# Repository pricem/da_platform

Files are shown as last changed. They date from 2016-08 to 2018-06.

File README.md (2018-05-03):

# "Samoyed" digital audio platform

[Documentation site](http://da-platform.readthedocs.io)

##  What is it?

This is a set of PCB designs, FPGA firmware, and software for a digital audio interface.  The designs allow for up to 32 channels of audio I/O from four ADC/DAC modules per chassis.  The intent is to provide audio quality suitable for hi-fi systems, and to allow experimentation with ADC/DAC module design, digital filtering, and user interfaces.

More detailed documentation is located in the docs directory.  This documentation is in Sphinx format and is synchronized to http://da-platform.readthedocs.io.  A PDF version is periodically published to docs/da_platform.pdf.

Work is in progress.  If you have any questions, please contact the author by creating an issue, or commenting on a relevant issue if one already exists.

##  Use cases

The author is using this project as a music streaming server, digital crossover, and measurement device in a DIY audio system.  Other uses are possible and are described in more detail in the documentation.

## License information

This project is open source and intended for non-commercial use.  Intellectual property developed for this project is licensed partly under the Solderpad license (hardware) and partly under the GPL (software).  Please see the LICENSE file for more information, and the individual licenses in the docs/licenses directory for the complete terms.

Any other intellectual property included in this repository (whether for users' convenience, or accidentally) is covered by its own original license.

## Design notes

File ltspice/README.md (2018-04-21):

## LTspice schematics

This directory contains LTspice files for the design of some analog circuits used in this project:
* List to be added after all files are placed in this directory.

All designs here are licensed under the Solderpad license (docs/licenses/LICENSE-SHL).

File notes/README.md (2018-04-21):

## Miscellaneous planning and design notes

These files contain useful information, but are disorganized.  You can learn a lot (too much?) about my thought process by looking into the text files.  There are also BOM spreadsheets for ordering parts.

Over time, much of this will be reorganized into the docs directory.

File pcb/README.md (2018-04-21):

## Eagle PCB designs

This directory contains Eagle files for the design of PCBs used in this project:
* List to be added after all files are placed in this directory.

Please note that the files are in Eagle 5.x format.

All designs here are licensed under the Solderpad license (docs/licenses/LICENSE-SHL).

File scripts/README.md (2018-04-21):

## Shell scripts for DA platform

These are from the Raspberry Pi that I put in my DA platform box.  For now, these should be considered unsupported examples.

All code here is licensed under the GPL license (docs/licenses/LICENSE-GPL).

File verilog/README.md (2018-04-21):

## HDL design for DA platform

The baseline DA platform implementation has an FPGA in it, to act as an asynchronous FIFO and I2S/SPI/GPIO interface to the DAC and ADC cards.  This directory contains the SystemVerilog hardware description language (HDL) code for the digital logic on the FPGA.

The design is to some extent decoupled from the hardware platform that it runs on.  Please look at the xilinx directory for the scripts that build this into a bitstream for a specific FPGA.

All code here is licensed under the Solderpad license (docs/licenses/LICENSE-SHL).

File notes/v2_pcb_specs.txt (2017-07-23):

Specs for things to include on v2 PCBs
=========================================

PSU
---
Lowest reverse-recovery diodes possible
    Why not Schottkys?
12-pin connector to isolator

Carrier (shared)
----------------

Footprint for upside down RPi
JST power connector for 5 V (probably from ext wall wart)

Carrier option A - ZTEX FPGA
---------
FPGA board footprint (no mounting holes)
JTAG connector

Carrier option B - {USB, Mini}streamer
---------
Mechanical scheme for mounting streamer board
Header for attaching streamer board connections (put streamer upside down?)

Isolator
--------

Stuffing option for resistors instead of ADUM isolators
Debug header that is outside shadow of carrier

Jung discrete regs under center of board
Stuffing option for low cost 3 terminal regs for +/- 15, 5, 3.3 V

Clock
-----
Clock source support (stuffing options):
    Crystek CCHD-957
    Tentlabs XO
    Some other decent inexpensive osc.
    SMA input (SE CMOS level), as if from an arrogant module
Differential driver support:
    LVDS - low cost
        FIN1001 type driver
    CML - high performance
        ADCLK948 driver
        AD9515 receiver
Debug connections for:
    Clock sources - SMA
    Clock select input

Series resistance for CMOS clock outputs (10 to 22 ohm?)
Good supply decoupling / ferrite beads
Stuffing option for local supply regulation

Modules
--------
Module adapter for testing v1 modules before v2 modules are designed

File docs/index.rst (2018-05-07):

"Samoyed" digital audio platform
=======================

This page is the starting point for documentation about the project (often referred to as the "DA platform").

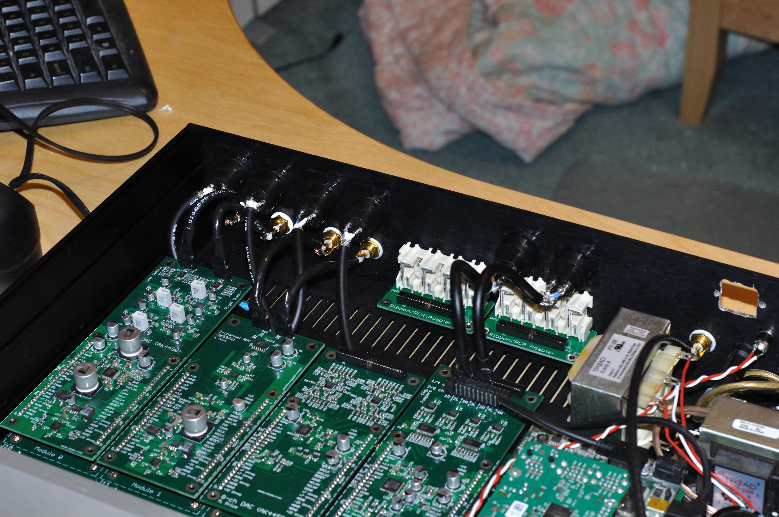
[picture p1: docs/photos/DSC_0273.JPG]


    A baseline implementation of the platform.  This one has two AK4490-based 2-channel DACs, as well as an 8-channel DAC and 8-channel ADC.  The onboard Raspberry Pi functions as a music streaming server and digital active crossover.
    
.. toctree::
   :maxdepth: 2
   :caption: Contents:
   
   intro
   history
   hw_arch
   measurements

Indices and tables
==================

* :ref:`genindex`
* :ref:`modindex`
* :ref:`search`

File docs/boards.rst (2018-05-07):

Boards designed so far
======================

This section describes the features of the PCB designs that have been completed and tested so far.  Eagle 5.x files for the boards can be found in the ``pcb`` directory.

Some modules were developed for an earlier version of the platform, and have been tested with the current version using an adapter PCB.  These older modules would need to be revised to meet the current interface specification, and don't fit within a reasonably sized chassis with the current backplane (because they are mounted vertically).

**Modules**

More detailed information about modules (explaining the design process) will be added later.  For now, here is a short summary of what is on each board.  The baseline implementations use AKM parts because they are readily available (with full datasheets), perform well, and the DACs conveniently have voltage outputs.

* DAC2 (2 channel DAC)

  * DSD1792_ (tested on earlier platform only)
  
    * No local regulation; uses regulated supplies from backplane
    * Two iterations of a common-base I/V stage
    
      * `Revision A`__ with simple BJT current sources and MOSFET follower output 
      * `Revision B`__ with improved PSRR, 3rd-order antialising filter and diamond buffer output
      
  * AK4490_

    * LT3042 local regulators for VDDL/R and VREFL/R; ADM7160 regulators for AVDD and DVDD
    * AD9515 LVPECL clock receiver powered by ADM7154 regulator
    * ADA4899-1 output buffer/filter powered by ADP7142/ADP7182 regulators
    * 2 V differential (1 V single-ended) full-scale output
    * 0/10/20/30 dB resistive attenuator controlled by GPIO

.. _DSD1792: https://github.com/pricem/da_platform/raw/master/docs/schematics/dac2_v1.pdf
.. __: https://github.com/pricem/da_platform/raw/master/docs/schematics/dac2_v1_iv_a.pdf
.. __: https://github.com/pricem/da_platform/raw/master/docs/schematics/dac2_v1_iv_b.pdf
.. _AK4490: https://github.com/pricem/da_platform/raw/master/docs/schematics/dac2_v2.pdf

* ADC2 (2 channel ADC)

  * AK5572_

    * LT3042 local regulators for AVDD and VREFL/R; ADM7160 regulator for DVDD
    * AD9515 LVPECL clock receiver powered by ADM7154 regulator
    * ADA4004-4 input buffer; ADA4932-2 ADC driver powered by ADP7142/ADP7182 regulators
    * 2.25 V full-scale input (differential or single-ended)

* DAC8 (8 channel DAC)

  * AD1934_ (tested on earlier platform only)
  
    * No local regulation; uses regulated supplies from backplane
    * Two iterations of a voltage gain / antialiasing filter stage
    
      `Revision A`_, `Revision B`_
      
  * AK4458_
  
    * ADP7118 regulators for AVDD and VREF; ADM7160 regulator for DVDD
    * LS90LV012 LVDS clock receiver powered by ADP7118 regulator
    * OPA1664 output buffer/filter
    * 2 V single-ended full-scale output (no differential output)
    * 0/10/20 dB resistive attenuator controlled by SPI

* ADC8 (8 channel ADC)

  * AK5578_
  
    * ADP7118 regulators for AVDD and VREF; ADM7160 regulator for DVDD
    * LS90LV012 LVDS clock receiver powered by ADP7118 regulator
    * OPA1664 input buffer; THS4524 ADC driver
    * 2.25 V full-scale input (differential or single-ended)

.. _AK5572: https://github.com/pricem/da_platform/raw/master/docs/schematics/adc2_v2.pdf
.. _AD1934: https://github.com/pricem/da_platform/raw/master/docs/schematics/dac8_v1.pdf
.. _Revision A: https://github.com/pricem/da_platform/raw/master/docs/schematics/dac8_v1_scaler_a.pdf
.. _Revision B: https://github.com/pricem/da_platform/raw/master/docs/schematics/dac8_v1_scaler_b.pdf
.. _AK4458: https://github.com/pricem/da_platform/raw/master/docs/schematics/dac8_v2.pdf
.. _AK5578: https://github.com/pricem/da_platform/raw/master/docs/schematics/adc8_v2.pdf

**Clock source**

* `Initial version`__ with multiple stuffing options
  
  * One clock is on and one is powered down at all times (selected by carrier)
  * Damped ferrite bead supply filters leading to each oscillator and to logic
  * Low cost stuffing example:
  
    * ADM7160 regulator
    * Epson SG-210STF oscillators
    * 74xx CMOS mux and FIN10xx LVDS buffer
  
  * High performance stuffing example:
  
    * ADM7154 regulator
    * Crystek CCHD-957 oscillators
    * ADCLK948 LVPECL clock mux/buffer
    
  Note that you can use any combination of oscillator, regulator and buffer.  There are SMD footprints which would fit (for example) the NDK NZ2520SD, and DIP footprints that fit (for example) the Tentlabs XO.
  
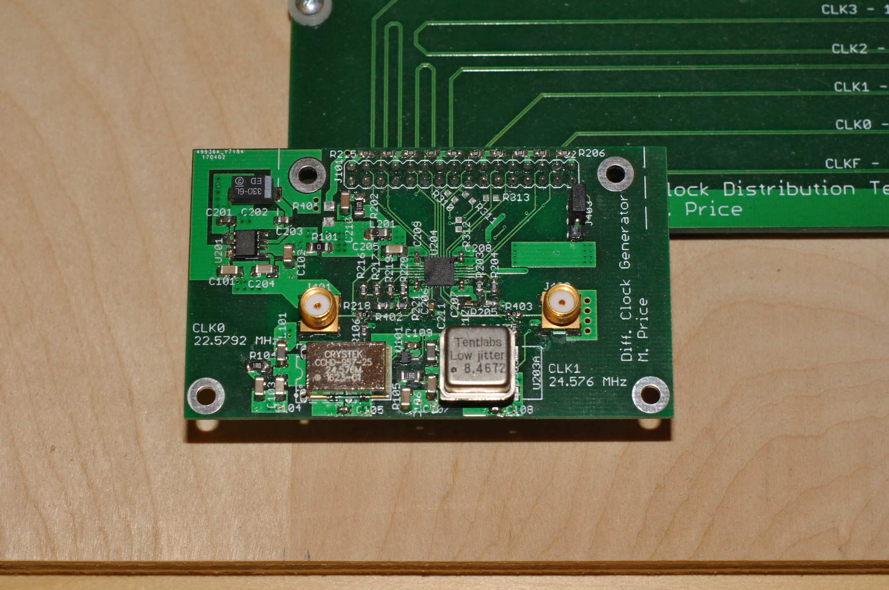
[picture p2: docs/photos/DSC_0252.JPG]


    Testing of a clock source board allowing comparison between Crystek CCHD-957 and Tent XO oscillators.
  
.. __: https://github.com/pricem/da_platform/raw/master/docs/schematics/clock_v2.pdf

**Backplane**

* `Initial version`__

  * Stuffing options for digital interconnect:
  
    * ADUM340x / ADUM14xE0 transformer isolators
    * Resistor/jumper bypass option for non-isolated system

  * Global regulation (+5 V, +3.3 V, +/- 15 V) with stuffing options:
  
    * LM317/LM337 with Vadj bypass
    * Jung regulators with LM317/LM337 preregulator

.. __: https://github.com/pricem/da_platform/raw/master/docs/schematics/isolator_v2.pdf

**Carrier**

* `Initial version`__ contains:

  * ZTEX USB-FPGA 2.13a (Xilinx Artix-7 XC7A35T FPGA, 256 MB memory)
  
    This project includes an HDL design and build scripts for the FPGA to function as the carrier, exercising all features of the module interface.  It also acts as a deep (8M sample) asynchronous FIFO, since the USB interface clock is unrelated to the audio clocks.  Much more information about this can be found in the `Digital design`_ section.
  
  * Raspberry Pi (optional)
  
    I use MPD running on the Raspberry Pi as a streaming server for audio files stored on a NAS.  The Raspberry Pi is mounted on the carrier card within the chassis, and has an extension cable to an Ethernet jack on the back.  However, you can leave out the Raspberry Pi and connect any computing device to the FPGA board using USB (with a similar extension cable).  It's possible to use a USB Wi-fi adapter.
  
  * External 5 V DC wall wart supply (can be isolated from audio supplies, if backplane is equipped with isolators)

  * Debug/expansion header (0.1" pitch) for prototyping

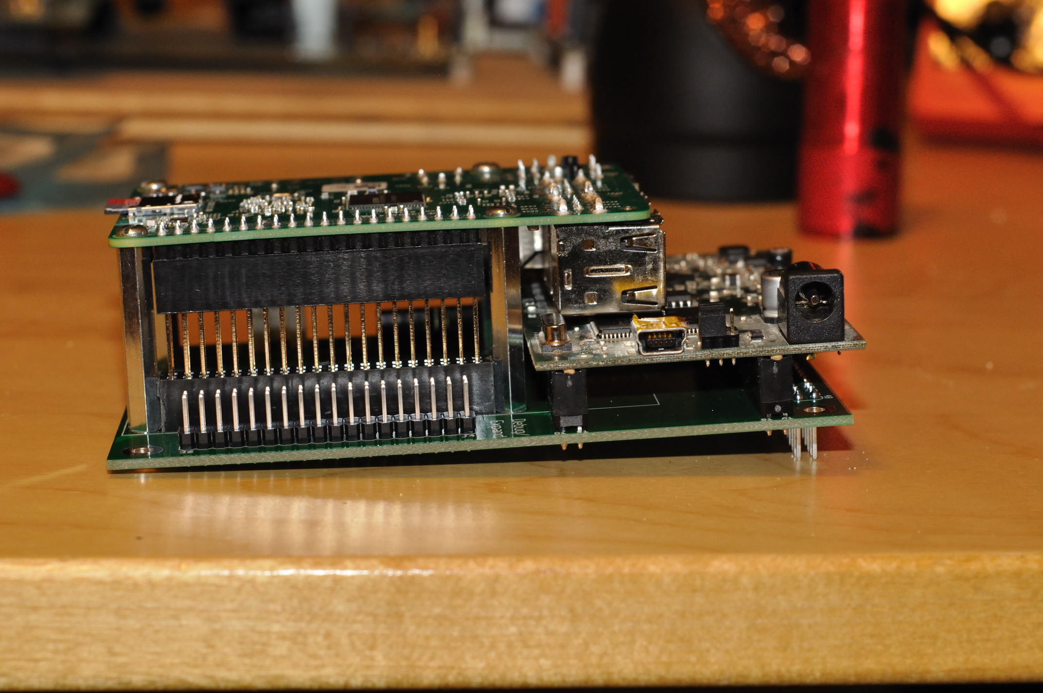
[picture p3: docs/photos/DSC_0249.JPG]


    Photo of carrier board stack showing ZTEX FPGA board (right) and Raspberry Pi (top) connected with a stacking header.

.. __: https://github.com/pricem/da_platform/raw/master/docs/schematics/carrier_v2.pdf

**PSU**

* `Initial version`_

  * 60 Hz linear supply with diode rectifiers
  * Dual 5 V (Triad VPS10-2500) and 28 Vct (Triad FD7-28) transformers
  * +7 V unregulated outputs for analog and digital sections
  * +/- 22 V unregulated outputs for analog sections
  * 10,000 uF decoupling for each rail
  * At least 1 A load is allowed for all supplies simultaneously

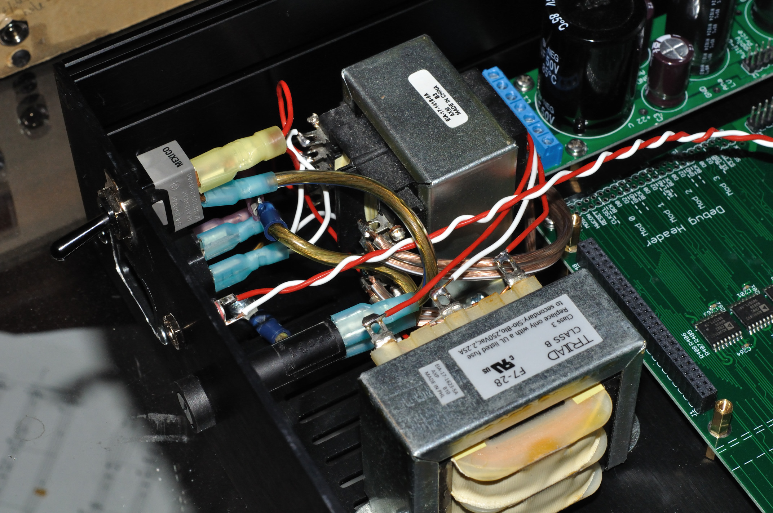
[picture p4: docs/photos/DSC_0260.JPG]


    Detail of transformer wiring for PSU.  The rectifier/filter PCB is in the upper right.

.. _`Initial version`: https://github.com/pricem/da_platform/raw/master/docs/schematics/psu_v2.pdf

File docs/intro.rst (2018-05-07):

Introduction
------------

Motivation
==========

There are many options for DIY digital audio, especially 2-channel DACs.  
You can buy complete kits or building blocks like USB I2S interfaces, power supplies, and DAC boards.
But there are some more complicated choices and compromises to make for other applications, like home theather, digital crossovers, music recording, and measurements.
This project aims to provide a common platform to support this variety of applications with minimal hardware or software re-design.
All of its PCB designs, FPGA firmware, and software code are open-source and included in the GitHub repository.

Features
========

The baseline design allows you to build a box with up to 32 channels of audio I/O at standard sample rates (44.1--192 kHz).  The main capabilities I pursued are: 

- **Removable DAC/ADC modules with a common mechanical and electrical specification**

  The modules can be swapped out based on system configuration needs, budget limitations, or listening preferences.
  DIYers can contribute novel converter and analog designs by designing a module, without "reinventing the wheel" for everything else.
  The platform carries up to 4 modules with up to 8 channels each.
  PCB designs are provided for 2-channel and 8-channel DACs and ADCs with recent AKM parts.

- **Support for FPGA-based asynchronous FIFO**

  The digital interfaces in the platform can be controlled by a ZTEX USB-FPGA 2.13a board containing a Xilinx XC7A35T FPGA and 256 MB of DRAM.
  I provide firmware for the FPGA to act as a set of large asynchronous FIFOs in both directions.
  This allows the use of a local master clock and makes performance independent of software and USB behavior.
  
- **Support for built-in music streaming server and real-time FIR filtering using Raspberry Pi**

  The Raspberry Pi can connect to a wired or wireless Ethernet network.
  MPD is used as a music server that can be controlled by an Android mobile app.
  It can play music stored on another computer or NAS, and stream music from another device.
  ALSA configuration options allow some channels to be directed through the speakers library or another filtering engine.

- **Support for galvanic isolation of modules**

  The complex digital portions of the system (typically Raspberry Pi and FPGA) have a separate power supply from the modules and clock sources.
  Digital signals (e.g. I2S, SPI) are routed through Analog Devices transformer isolators which allow these supplies to use separate grounds.
  The purpose of this is to reduce the currents flowing in the grounds (both digital and analog) used by the modules and clock sources.

- **Stuffing options for different budgets**

  In order to broaden the accessibility of this platform, different versions can be built with different capabilities.
  The only constant is the underlying PCBs, which are inexpensive.
  If an asynchronous FIFO and low-jitter clocking are not needed, a USBStreamer or Ministreamer I2S interface could be used.
  The baseline backplane can be built with jumpers in place of the galvanic isolators.
  Different DAC and ADC modules, clock sources, power supplies, and chassis can also be chosen for the desired system cost.

- **Moderate performance limitations**

  This platform probably won't achieve the same performance as a carefully designed and tweaked, purpose-built setup for a particular application.
  However, I believe it can get close.
  The backplane PCB does not carry analog audio signals.
  EMI can be suppressed by installing a conductive divider that places the ADC/DAC modules in a Faraday cage.
  Modules can provide their own supply regulation.
  The differential clock distribution scheme limits excess phase noise added to that of the clock sources.

These features are justified and explained in more detail in the following sections.

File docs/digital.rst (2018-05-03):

Digital design
==============

The baseline carrier design includes an FPGA, which gives it a lot of flexibility.  This section describes the digital logic that runs on the FPGA, providing up to 32 channels of audio I/O through asynchronous FIFOs, and allowing a host computer to exercise all module features via USB.

The logic is defined in SystemVerilog hardware description language (HDL).  Any future improvements will be shared with users who can simply reprogram their boards.  The design could also be retargeted to other carrier boards.  Please see the ``verilog`` directory of the repository for design and simulation sources, and the ``xilinx`` directory for build scripts.  

I started out with the `ZTEX USB-FPGA 2.13a board <https://www.ztex.de/usb-fpga-2/usb-fpga-2.13.e.html>`_, which has all of the necessary features and comes with an elegant and open-source software/firmware stack for delivering data to and from the custom logic via USB.  It is also affordable compared to other FPGA boards with similar capabilities.

The primary function of this design is to provide a bridge between a computing device and the physical interfaces (I2S, SPI, and GPIO) of the four DAC/ADC modules.  (From a digital design perspective, it would be easy to change the number of modules at build time.)  For now we are using a USB interface for the host computer, but other interfaces could be added in the future; for example, audio could be streamed over Ethernet, or control commands could be sent over a UART or SPI.

The architecture is shown in the following diagram.



Each module interfaces with a "slot controller" which accepts commands and audio samples specific to that module.  The audio sample I/Os are 32 bits wide and the stream of samples can be rearranged according to runtime configuration (number of channels, I2S vs. left-justified vs. right-justified, etc).  The command interface is 8 bits wide; commands are encoded into a stream of bytes, with the first byte representing the type of command and the remaining bytes containing parameters/arguments.

Data sent over USB (broken into 16-bit words) is directed to the command handler, a state machine which examines each word and takes the appropriate action.  There are some global commands which can be dealt with immediately by the command handler, for example the command to reset all of the modules.  Other commands are addressed to a specific module and thus are delivered to the appropriate slot controller; the response is returned to the host.  

Audio samples are handled differently: we want to provide a large buffer (FIFO) so the software on the host doesn't need to keep up with the exact timing of playback or recording.  A single buffer isn't enough since there are four modules, each of which could be functioning as a DAC or ADC, or not being used at all.  But with some massaging, we can use a single fast memory (DDR3) to provide a set of 8 virtual FIFOs (one in each direction for each module).  Access to this external memory is controlled by a block called the FIFO arbiter.  To the outside world, it looks like we have several independent FIFOs.  On the ZTEX FPGA board, the DDR3 memory is 256 MB, so each virtual FIFO is big enough for 8M samples--more than a minute of stereo audio at 44.1 kHz.

There are three clock domains in the design.  

1. The USB interface provides a 48 MHz clock.  The command handler and most of the control logic is driven by this clock; it is divided down to 3 MHz for SPI and GPIO signals.
2. The DAC/ADC modules run on a clock that is a multiple of the audio sample rate.  Nominally this is 22.5792 MHz or 24.576 MHz.  This clock must have very low phase noise at the DAC or ADC itself, but the data signals to/from the carrier don't need any special treatment as long as they meet the timing constraints of the chips they are talking to.  
3. The DDR3 memory runs on a faster clock (nominally 400 MHz).  Interfacing to this memory is handled by a specialized IP block provided by the FPGA vendor.

Within the design, synchronizers and asynchronous FIFOs are used to transfer signals between different clock domains.

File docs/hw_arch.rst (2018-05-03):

Hardware architecture
---------------------

The platform is divided into several components on PCBs.  Different functions may be implemented on each PCB, but the interfaces should stay the same to keep them interoperable.  These PCBs are illustrated in the figure below.



The following sections briefly describe the function of each PCB and their interfaces to the other PCBs.

**Modules**: An audio ADC or DAC.  The basic requirement of a module is an I2S input (or output).  The module interface provides for:

* Up to 4 lanes of I2S data (nominally 8 channels of audio)
* Regulated and unregulated power supplies
* SPI interface for software control of audio converters and other peripherals
* GPIO interface: 8 bits in and 8 bits out

If you design a new module complying to the module interface specification, you can write some high-level software to control it, but won't have to change any of the other links in the chain.

**Carrier**: A digital source/sink for the signals that go to each module.  Can include or interface to a computing device (whether embedded or separate) to improve flexibility.  Carriers don't necessarily have to support every possible feature.

**Backplane**: Interconnect between the carrier and the modules.  Also distributes power from the PSU to the modules.  The carrier can be powered by the same power supply as the modules, or have its own power supply.  The backplane also contains supply regulators for any modules that don't have local regulation.

**Clock source**: Supply of the necessary clocks for audio converters, at a nominal frequency of 22.5792 MHz or 24.576 MHz.  Clocks are distributed differentially by the backplane.  The clock source has separate output pins for 5 loads: one for each of the four modules, and one for the carrier.

**PSU**: An unregulated power supply.  Generates separate +7 V rails for the digital and analog sections, and +/- 22 V rails for the analog sections of modules.

.. include:: boards.rst

.. include:: interfaces.rst

.. include:: digital.rst

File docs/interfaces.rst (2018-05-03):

Interfaces
==========

This section describes the electrical interfaces in the initial version of the DA platform.  The idea is that different PCBs can be designed for each function (carrier, backplane, modules, etc.) and safely interchanged if they meet the interface specifications.  All of the board-to-board connections are made with standard 0.1" pitch headers.  It's possible to stack boards, or (except for modules) to put the boards side by side and make the connection with an appropriately sized ribbon cable.

**PSU to backplane** : 12 pins (6x2 header)

In the baseline design, the PSU has transformers directly screwed to the chassis, and a small rectifier/filter board that mounts to the right of the backplane.  They are connected via a ribbon cable.



==========  ======  ===========================================
Pin number  Name    Description
==========  ======  ===========================================
1           D7VU    Unregulated +7 V for digital section
2           DGND    Digital ground
3           D7VU    Unregulated +7 V for digital section
4           DGND    Digital ground
5           A7VU    Unregulated +7 V for analog section
6           AGND    Analog ground
7           A7VU    Unregulated +7 V for analog section
8           AGND    Analog ground
9           AP22VU  Unregulated +22 V for analog section
10          AGND    Analog ground
11          AN22VU  Unregulated -22 V for analog section
12          AGND    Analog ground
==========  ======  ===========================================

**Carrier to backplane**:

In the baseline design, the backplane has a female header on top, and the carrier has a male header on the bottom.  The carrier stacks on top of the backplane.


    
==========  ========    ============================================
Pin number  Name        Description
==========  ========    ============================================
1           S0_LRCK     I2S word clock for module slot 0
2           S0_BCK      I2S bit clock for module slot 0
3           S0_D1       I2S data lane 1 for module slot 0
4           S0_D0       I2S data lane 0 for module slot 0
5           S0_D3       I2S data lane 3 for module slot 0
6           S0_D2       I2S data lane 2 for module slot 0
7           DGND        Digital ground
8           DGND        Digital ground
9           S1_LRCK     I2S word clock for module slot 1
10          S1_BCK      I2S bit clock for module slot 1
11          S1_D1       I2S data lane 1 for module slot 1
12          S1_D0       I2S data lane 0 for module slot 1
13          S1_D3       I2S data lane 3 for module slot 1
14          S1_D2       I2S data lane 2 for module slot 1
15          DGND        Digital ground
16          DGND        Digital ground
17          S2_LRCK     I2S word clock for module slot 2
18          S2_BCK      I2S bit clock for module slot 2
19          S2_D1       I2S data lane 1 for module slot 2
20          S2_D0       I2S data lane 0 for module slot 2
21          S2_D3       I2S data lane 3 for module slot 2
22          S2_D2       I2S data lane 2 for module slot 2
23          DGND        Digital ground
24          DGND        Digital ground
25          S3_LRCK     I2S word clock for module slot 3
26          S3_BCK      I2S bit clock for module slot 3
27          S3_D1       I2S data lane 1 for module slot 3
28          S3_D0       I2S data lane 0 for module slot 3
29          S3_D3       I2S data lane 3 for module slot 3
30          S3_D2       I2S data lane 2 for module slot 3
31          DGND        Digital ground
32          DGND        Digital ground
33          HWFLAG      Serialized GPIO input from modules
34          HWCON       Serialized GPIO output to modules
35          CS_n        Serialized SPI chip select (active low)
36          DIRCHAN     Serialized module configuration indicator
37          SRCLK2      2nd level (64 bit) deserializer clock
38          SRCLK       1st level (8 bit) deserializer clock
39          MOSI        SPI data output to modules
40          MISO        SPI data input from modules
41          DGND        Digital ground
42          CLKSEL      Clock select (e.g. 22.5792 vs. 24.576 MHz)
43          SCLK        SPI and serializer clock
44          RESET_n     Module reset (active low)
45          DGND        Digital ground
46          C3V3        3.3 V digital supply from carrier
47          MCLK        Audio clock for I2S masters
48          C3V3        3.3 V digital supply from carrier
==========  ========    ============================================

**Clock source to backplane**:

In the baseline design, the backplane has a female header on top, and the clock source has a male header on the bottom.  The clock source stacks on top of the backplane, hanging over the lower edge.



==========  ========    ===========
Pin number  Name        Description
==========  ========    ===========
1           D7VU        Unregulated 7 V supply
2           DGND        Ground
3           DGND        Ground
4           S0_MCLKP    Differential clock output to module slot 0
5           DGND        Ground
6           S0_MCLKP    Differential clock output to module slot 0
7           D7VU        Unregulated 7 V supply
8           DGND        Ground
9           DGND        Ground
10          S1_MCLKP    Differential clock output to module slot 1
11          DGND        Ground
12          S1_MCLKP    Differential clock output to module slot 1
13          D3V3        Regulated 3.3 V supply
14          DGND        Ground
15          DGND        Ground
16          S2_MCLKP    Differential clock output to module slot 2
17          DGND        Ground
18          S2_MCLKP    Differential clock output to module slot 2
19          D3V3        Regulated 3.3 V supply
20          DGND        Ground
21          DGND        Ground
22          S3_MCLKP    Differential clock output to module slot 3
23          DGND        Ground
24          S3_MCLKP    Differential clock output to module slot 3
25          D3V3        Regulated 3.3 V supply
26          DGND        Ground
27          DGND        Ground
28          C_MCLKP     Differential clock output to carrier
29          DGND        Ground
30          C_MCLKP     Differential clock output to carrier
31          CLKSEL      Selects active oscillator (22.5792 or 24.576 MHz)
32          DGND        Ground
==========  ========    ===========

**Module to backplane** : 54 pins (2x 27x1 header, with 2.0" spacing)

The module has some additional mechanical requirements because they sit on top of the backplane.  

TODO: Drawing of mechanical footprint of module

If you can't fit all the necessary circuitry on one board of this size, consider vertical stacking.  You could also design an extra-wide module that takes up 2, 3, or 4 slots.



==========  ========    ====================================================
Pin number  Name        Description
==========  ========    ====================================================
1L          AP15V       Regulated +15 V supply for analog section
2L          AGND        Analog ground
3L          AGND        Analog ground
4L          AN15V       Regulated -15 V supply for analog section
5L          AGND        Analog ground
6L          A5V         Regulated 5 V supply for analog section
7L          D3V3        Regulated 3.3 V supply for digital section
8L          DGND        Digital ground
9L          BCK         I2S bit clock
10L         DGND        Digital ground
11L         LRCK        I2S word clock
12L         SDATA0      I2S data lane 0
13L         SDATA1      I2S data lane 1
14L         SDATA2      I2S data lane 2
15L         SDATA3      I2S data lane 3
16L         DGND        Digital ground
17L         CS_n        SPI chip select (active low)
18L         MOSI        SPI data input
19L         MISO        SPI data output
20L         DGND        Digital ground
21L         D7VU        Unregulated 7 V supply for digital section
22L         A7VU        Unregulated 7 V supply for analog section
23L         AGND        Analog ground
24L         AN22VU      Unregulated -22 V supply for analog section
25L         AGND        Analog ground
26L         AGND        Analog ground
27L         AP22VU      Unregulated +22 V supply for analog section
==========  ========    ====================================================

==========  ========    ====================================================
Pin number  Name        Description
==========  ========    ====================================================
1R          AP15V       Regulated +15 V supply for analog section
2R          AGND        Analog ground
3R          AGND        Analog ground
4R          AN15V       Regulated -15 V supply for analog section
5R          AGND        Analog ground
6R          A5V         Regulated 5 V supply for analog section
7R          D3V3        Regulated 3.3 V supply for digital section
8R          DGND        Digital ground
9R          HWCON       Serialized GPIO input
10R         HWFLAG      Serialized GPIO output    
11R         DIR         Module direction: 1 = DAC, 0 = ADC
12R         CHAN        Number of channels: 1 = 8-ch, 0 = 2-ch
13R         SCLK        SPI and serializer clock
14R         SRCLK       1st level deserializer clock
15R         SRCLK2      2nd level deserializer clock
16R         RESET_n     Reset (active low)
17R         DGND        Digital ground
18R         MCLKN       Differential audio clock input
19R         MCLKP       Differential audio clock input
20R         DGND        Digital ground
21R         D7VU        Unregulated 7 V supply for digital section
22R         A7VU        Unregulated 7 V supply for analog section
23R         AGND        Analog ground
24R         AN22VU      Unregulated -22 V supply for analog section
25R         AGND        Analog ground
26R         AGND        Analog ground
27R         AP22VU      Unregulated +22 V supply for analog section
==========  ========    ====================================================

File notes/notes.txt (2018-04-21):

Protocol and design notes

Command packet format
Byte 0: header byte (0xFF default)
Byte 1: port ID (0x00 - 0x03)
Byte 2-3: command

Data packet format
Byte 0: header byte (0xFF default)
Byte 1: port ID (0x00 - 0x03)
Bytes 2-3: length in bytes

Jan 18, 2015

- Micron DDR3 sim testbench

D:\projects\cdp\libs\micron_ddr3>iverilog -g2012 -Dsg125 -Dx16 -Dden2048Mb tb.v ddr3.v -o ddr3_tb

D:\projects\cdp\libs\micron_ddr3>vvp ddr3_tb
ERROR: $urandom_range requires two arguments.
ERROR: $urandom_range requires two arguments.
ERROR: $urandom_range requires two arguments.
-> fixed, added 0 as 2nd arg in subtest.vh

Confusing pins on DDR:
    cs_n - can tie low
    dm_tdqs - connect to dm
    tdqs_n - can be high impedance

Compiling FIFO-DDR testbench:
D:\projects\cdp\fpga_projects\usb_fifo_ddr>iverilog -g2012 -Dsg125 -Dx16 -Dden2048Mb -o usb_fifo_ddr_tb -I "D:\projects\cdp\libs\micron_ddr3" -y "C:\Xilinx\Vivado\2014.4\data\verilog\src\unisims" -y "C:\Xilinx\Vivado\2014.4\data\verilog\src\retarget" -s usb_fifo_ddr_tb -f sources.txt -f mig_sources.txt

D:\projects\cdp\fpga_projects\usb_fifo_ddr>iverilog -g2012 -Dsg125 -Dx16 -Dden2048Mb -o usb_fifo_ddr_tb -I "D:\projects\cdp\libs\micron_ddr3" -y "C:\Xilinx\Vivado\2014.4\data\verilog\src\unisims" -y "C:\Xilinx\Vivado\2014.4\data\verilog\src\retarget" -s usb_fifo_ddr_tb -f sources.txt -f mig_sources.txt

Aug 1--12, 2016
---------------
See paper notes packet on "DA platform resumption"
Much progress was made: basic audio output on ZTEX platform working, but there are glitches
ADC hardware is probably bad; so is DAC I/V conversion
Started working on an I2S loopback test to get that aspect working (slot 1 has DAC, slot 0 has ADC)

Dec 30, 2016
------------
Resurrecting project (again).  Keeping electronics notes since they last longer.

Startup procedure:
- Ensure that boards are hooked up
- program FPGA using FWLoader or Vivado
- run python ztex_test.py

Current state:
- can (most of the time) write/read one chunk of a small number of samples (80)
- can't do anything after that (hard lockup), even after reset_slots
    Note: reset_slots work but slot write FIFO command doesn't
    which indicates that top level I/O might be alright, but slot isn't

Short term: review I/O protocol to see what the device is supposed to be doing
    Looks like we're doing the right thing; short global commands don't have checksum like per-slot commands

ILA debug
    When SW gets stuck, main module is in state 2 (handle output) with write_counter 0xf4
    That doesn't seem right... let's check after the small initial test -> state 0, word counter 1
    Receiving the start-recording command goes alright
    Then we get some output... maybe we started writing samples and read samples came back at the same time?
        No, I never trigger the handle input state after recording started
        Was I2S running, or was there some buffer with samples left in it?
    It's possible to read 512 samples before even writing anything.
        -> Yes, I2S is left running.
        It looks like this is by design.  I2S outputs for DAC are always running and the data is all zeros.
    There is probably some problem parsing the ADC audio messages in SW
    After testing fixed data, there is a 22 word message left in report_unparsed
        It is an incomplete ADC audio packet
        That's because we were flushing by using low-level read() and not update_receive_state()
        Using a new flush() function seems to get rid of the leftovers, most of the time?
        This allows us to at least proceed to continuous test
    Continuous test: gets through 3 chunks (768 samples each way) then hangs
        It seems there is too much data waiting to be read
        Try, for now, reading more data than we wrote
        See if we can at least get continuous operation...
        If I read 4x as many samples as I write, it runs without crashing... but there are tons of zeros
        How to get things running at the same rate?  Big FIFOs?
        It looks like there are basically no FIFOs internally.  da_platform has 16 word FIFOs, and connects directly to EZ-USB.
        -> Increase size of da_platform FIFOs... trying 1k words
        With 1k FIFOs, still need to read at 2x write speed to avoid lockup... why?
        Bringing chunk up to 256 and reducing read timeout to 10 allows continuous operation
    Now time to investigate sample errors
        First 256 samples look good, then there are 186 zeros, then 256 more samples, then more zeros
        In general, it looks like there are some hiccups at beginning and eventually it gets "into a rhythm"
        First 178 samples OK, then samples 178--255 are a repeat of samples 0--77; then we have a string of zeros before correct samples resume
        Run to run, the exact number of samples varies (e.g. 176, 246)
        Note: switched to ramp input (i.e. count 1 to 44100) to avoid ambiguity.
    Trying ILA debug in arbiter to see if that has anything to do with it.
    Could this be done in simulation?
        Once we have a more detailed sense of the problem.  No sense wandering aimlessly in sim.
    Experimenting with smaller chunks, to see if the error can be tracked down
        With chunk size = 128, caught error on Logicport. (Lesson: DAC output is messed up.)
        After sample 88, left channel outputs 89 then right channel 0, both channels 0, then both channels 1
        Error is hard/impossible to trigger with a chunk size of less than 120
        But I saw it happen as early as sample 67
        Arbiter FIFOs have a 64 word capacity (1 word = 32 bits = 1 sample for 1 channel)
        Read side of DAC port has 80 word capacity.  
        Arbiter fills that up, then writes short bursts of typ. 9 words at a time to RAM FIFO
    Try another ILA test looking more at arbiter port 1
        In the "bad" case, it looks like samples get read during the write burst?
        Sim has a problem I haven't seen in reality: 1 word gets dropped from host input, leading to 16-bit shift in audio samples
            This seems to be caused by a modeling issue - main I/O had a repeated word, but I don't think this happens in reality
        Look at data going into arbiter's main write FIFO?
        arbiter.ports_dup[1].write_fifo output doesn't wrap around
        Main write FIFO in doesn't wrap around... need to look at main read FIFO out
        Read FIFO output does wrap around.
        -> Problem seems to be in either those FIFOs or the DRAM FIFO
            Mem write FIFO doesn't wrap around (i.e. main write FIFO out)
            Mem read FIFO does wrap around (i.e. main read FIFO in)
        Confusion between slots, maybe?
        Check internal FIFOs within MIG adapter.
            Write side: Not wrapping around
            Read side: Wrapping around
        -> MIG adapter must be getting confused between the two ports somehow.
        Try disabling recording. -> no wraparound on MIG read
        So what exactly is happening, with recording enabled?
            When ADC is writing 0x12e, DAC is reading 0x21
            So when ADC was writing 0x21, what was DAC doing?
            When DAC was writing 0x1ca, ADC was writing 0x003 to location 0x161 [wraparound at sample 0x160]
            And DAC was reading 0x57...
        Errors seem to happen whenever the ADC starts to get nonzero samples
            i.e. DAC errors start as soon as ADC samples are nonzero
            If DAC-ADC latency is larger than entire signal, then we don't notice errors
            Actually, this isn't DAC-ADC latency, this is software latency from start_recording to write_audio
            So something goes wrong as soon as DAC and ADC are going at the same time
            Memory address aliasing?  (ADC data overwrites DAC data)
    -> There was a memory aliasing issue. 2 bugs:
        Memory address app_addr was coded as [23:0], needed to be [27:0]
        Address was zero-padded going into MIG, which cut off the upper bits
        
On to the next set of problems
    First 512 samples recorded are fine, but then there are gaps
    The gaps are especially large near the beginning, but they don't entirely go away with time
    Software shows that the time to write each packet goes down
    -> Is this purely an issue of software-lag in sending samples?
        Writes only (no recording) takes 40-50% of real time at chunk size 256, 20% at 2048, 7-10% at 32k+
        It would be reasonable to assume that when you add reading, you're too slow
        Some slowdown is probably due to the VM, but still.  
        This is just 44.1 kHz stereo (32 bit = 352.8 kB/s), it should work fast.
        Right now it's about 4.6 MB/s at most, and it should be 40.  (ZTEX test of VM clocked at 9 MB/s.)
        Maybe this is a problem for later.
    So, should reads be at the request of the host?  How does the system know when to read out data from a particular port?
        Imagine that it isn't at request of the host. We can
            a) Wait for a certain number of samples to accumulate in the mem FIFO
            b) If idle, wait for a certain number of idle cycles to discharge the next port (round robin)
        Currently we are doing (b)
        The problem is, the host doesn't know when to read.  
            It could be trying to write when there is read data being sent (which wouldn't work).
        Let's look at how USB device drivers (audio class) do it.
            First, it looks like these are meant to be stereo out / mono in only.  Not so versatile.
            In USB, the source and sink endpoints are independent.  In other words, it can send and receive audio concurrently/independently.

1/1/2017
--------

Some background research
    ALSA
        has an "external plugin interface" that could be used to create a user space PCM driver
        already has a "file" plugin which can pipe a stream to a file or to a shell command (i.e. Python audio playing script)
        A plugin, once created, can be used by putting the right stuff in the .asoundrc file
        A plugin can also act as a signal source
    -> It is alright to work purely in user-space for now; ALSA will allow a user-space program to connect to other Linux apps
    Windows
        There is a user-mode driver framework, but it's apparently no good for drivers
        Tim Roberts of Probo recommends AVStream, but an easier method is a Directshow source filter
        Microsoft has an updated driver example: https://github.com/Microsoft/Windows-driver-samples/tree/master/audio/sysvad
        More documentation on MSDN
        But Windows programming is hard.
    USB audio class
        Seems to not be what we need.  But sometime down the line, it would be possible to alter the hardware architecture
        to comply with this spec.  (Multiple endpoints)
    Strategy for now (1/1/2017): make the hardware as simple as possible, do everything in userspace (i.e. request data from ADCs)

Implementing audio read request

1/2/2017
--------

    First test: send separate msg instead of read request at end of write msg
        No ILA
        Looks like we get data back, but even with blocking slots there's a big batch of audio at beginning - why?
        Also, we get an extra word received which throws off receive parsing
        In all, we don't get any valid samples back (maybe with a larger chunk we get one chunk?)
        After making audio_read use update_receive_state and requesting exact number of words: it takes 100 ms to receive even 32 samples (same for 64 samples) -- something in the USB chain?
        Larger chunk size fixes that, but:
        - Received data starts around 500 - is there a lag when unblocking slots, or lost samples?
           (Stop using slot-blocking for now)
        - FIFO status shows what you'd expect: massive number of ADC samples piling up and not being read
        - With a long enough timeout, it's possible to retrieve all of those samples at the end
        - As you'd expect, in the recording there are wide gaps between the chunks of valid samples, due to the long latency as seen by software
        -> Latency was being artificially supported by pktend_timeout input to ezusb_io
           Setting that to min. reduces latency from 100 ms to 1.3 ms
        Now, there are some performance issues in the software (multiple roundtrips).  Need to fix later.
        But by making the chunk size large enough (2k samples / 45 ms) we can close the loop in real-time.
        Now we see additional artifacts:
        1. Dropped samples (gap of 2 sample periods with 0 values, then signal resumes as if it "forgot" one sample)
           Note: sometimes there are gaps spaced by just 1 valid (mono) sample:. we drop LR then have a good L sample then drop RL
        2. Wrong samples (word swap?) - look into later
        Simulation probably isn't going to reveal these artifacts, but in the testbench there was a clock bug.  Could we be seeing a clock bug?
            Current clock structure: 
            - ifclk (generated by ezusb_io) used as host interface and core clock
            - fxclk used to generate 200/400 MHz memory clocks within da_platform_wrapper
        Example of bug: 2k chunk size, gap from 1703-1707 with first nonzero = 1224, or 679-683 with 971, 679-683/1138
        The gaps show up at the exact same places (679, 1703, ...), plus or minus a couple of samples
        Sometimes the gaps appear to have a regular pattern (every 512 samples?) but not always
        Are these gaps in playback or recording?  Try playing ones and looking at ILA
        Can't see since ILA only gets about 3 ms / 130 samples, while first gap is around 340
        Seems data dependent: if I change from a ramp to something else, errors go away
        -> So why not make the ILA trigger on the data?
    With the ILA, things actually get better... don't see errors at 680 again
        Look for something regular though
        Sometimes there are errors on a chunk boundary, e.g. 4k
        It took many tries to get a gap within a single chunk : 13654/16k/1382
        Seems possible to get error at 10920
        These errors aren't sufficiently repeatable.  Try different input patterns.
        -> To investigate async FIFO issues, could use ifclk instead of fxclk to generate mem clock (then it would be 192 rather than 200 MHz... close enough?)
        DAC sample == 0 didn't trigger when there was a gap in the output, so this is *probably* on the recording side
        Bad I2S connection? Fiddling with the wires made the problem worse.
        -> Try soldering I2S wires
        That's where the glitches within a chunk were coming from; probably parasitics, rather than bad connection
            (since moving the wires around makes more difference than soldering)
        Now we have to deal with gaps between chunks
        -> Was buffer underrun.  Just writing 1 chunk before starting reads fixes that, though smarter SW arch will help in the future.
        
    Time for a song test (4 minutes / 11M samples)
        First run: there was a 64 sample long error at 16M/22M
        This corresponds with 2^24 samples since the start of recording
        -> Explore in sim with region depth of 64 samples
        In sim, data after 171 is a bunch of zeros, followed by 107 (only) then 108--171, e.g 64 samples of errors?
        At least debug the sim...
    -> Clean results on 2 different songs (4-5 min each); no longer term testing yet
    
Now, try listening and measuring.
    Yuck.
    Lots of gain.
    Left channel distorts really fast
    Right channel may be a bit cleaner, but both have lots of spiky artifacts?
    At idle there are lots of spiky artifacts, i.e. 0s going into I2S
    Rate of spiky artifacts goes up significantly when music is playing
    Let's see if the loopback test still works, then disconnect I2S jumpers.  I2S could be coupling into I/V.
    -> Aha. Millions of errors.
    Disabled recording; shoved I2S wires out of the way.  Now fewer artifacts, but still some.
    -> Try to desolder them now.
    Left channel has way more gain than right (test at some point by exchanging I/V boards)
        Confirmed, this is with S/N 1 on left, S/N 2 on right; swapping I/V boards changes the gain
        Scope app confirms: gain difference is about 6, or 16 dB
    I2S wires removed: still clicking artifacts, but less than before
    For now, use the louder channel and try to fix clicking
        THD doesn't look so bad, if you ignore the clicking
        Clicking is scaled down in left channel, so it's present in the DAC output (not IV induced), and seems to happen on the same samples in L/R channels
        Probably 1-sample spike with pre- and post-ringing due to lowpass
        I2S signals themselves are probably fine.  
        Low quality of clock reaching DAC?
        When I did the I2S loopback test I was probing the I2S lines after the register.  And since those were fine, my guess is the DAC is having issues with the clock.
    Also try slot 0?
    -> Much better.  Must have been something wrong with slot 1 (probably clock distribution)--check soldering and layout.
    No spikes, though there is some hum (not too bad
    Back to the FFT.
        See measurements.txt.  SNR 79 dB, THD is generally around -70 dB though better around -20 dBFS
        Good enough for now.  Let's fix that other channel.

S/N 2 I/V stage debug
    Bias checks....
        Output: -39 mV on left, +196 mV on right (note: L- output is 86 mV)
        Inputs: R 5.6/5.3 mV, L 3.7/5.4 mV
        Current source (base): R 13.58/-13.63, L 13.52/-13.61
    Inspection.  Differences:
        R13 and R16 = 82.5 (L) / 47.5 (R)
        R12 = 1k (L) / 82.5 (R)
        The lower channel (neg out) is consistent with pos
    So what do those differences mean?
        a) R12
            This sets bias current for Q12.  With 82.5 ohm, expect 10.5 mA.  With 1k, expect much less (and clipping).
            Is this dependent on the zero point of the DAC?
            Datasheet says the center current is -6.2 mA.  Maybe I had the sign wrong?
        b) R13/R16
            This sets bias current for MOS output follower
            47.5 -> 18 mA
            82.5 -> 11 mA
            Why not leave these as is and see which channel is better
            (Maybe I changed that value for Sourcemeter testing?)
    -> Removed R12, it looks like I had the wrong sign on the datasheet current offset.
    THD is better without R12 esp. at high output (see measurements.txt)

At this point, the hacky setup is working as 2-channel DAC (see pictures).
    Stereo output (with isolation transformer) is reasonably clean.  
    THD < -80 dB in both channels at -30 dB and up
    Added to rack and configured laptop for testing with speakers
    Initial listening impressions: (comparing to memory of modified RCD-855 CD player)
        Reasonably relaxed, haven't been driven out of the room.
        Midrange a little more spacious?
        Bass is lean (good) and clean, but perhaps doesn't have as much impact as RCD-855
        Treble: noticeably drier, doesn't have the same body as before
            This might motivate a voicing adjustment on the speakers?
            Clean and detailed, though something might be missing.
        Better than Ezra track 12 was beautiful.
    Second listening (note: a little sick)
        More polite, peaceful.  Kind of sleepy? (Bela Fleck, Lumineers)
        Easier to follow the melody of the secondary instruments
        Missing the sense of body and impact (at moderate levels)

== End of sprint winter break 2016/2017 ==

Revisions to try on initial setup
- IV stage antialias filter (1st order: 3.3 nF cap to ground from IVOUT node of 750 ohm resistor)
- Different clock or clock distribution

1/4/2017
--------
Tried music server setup
    MPD on Linux VM
    Files shared over Samba (host: Windows PC)
    MPDroid on Android tablet
Seems to work, but didn't check audio output
    Wish list: album art?
Plan is to run MPD on a Raspberry Pi 3, should have a footprint for it on PCB

1/6/2017
--------
Trying IV stage antialias filter
First try, blew up IV stage output buf with shorted output (maybe some protection would be nice...)
Replaced MOSFET
Second try, got a lot of the clicking artifacts (bad clk/I2S signal integrity? more debug needed)
-> Needs more debug, and probably a hardware rev

1/7/2017
--------
Started bringing up DAC 8 ch board
Refreshed memory on the circuit.  Distortion performance may need improvement.
Plugged it in and turned on - nothing blew up.  
SV changes:
    - open up 8 channel I2S port support (when dir=1 chan=1) -- done
    - will need to support different SPI formats - currently only 16 bit (8 bit addr, 8 bit data) for DSD1792
        AD1934 needs 24 bit (8 bit global addr +RW, 8 bit reg addr, 8 bit data)
      in theory, there is a way to do this (in spi_master interface) but slot_controller hardcodes the bits.
      Just spend some time in the sim to prototype.

Note:
    When you have SPI working, carefully go through registers in the datasheet and make sure the settings make sense.
        i.e. read all regs, see initial vals, reprogram and reread
    Reg 0 bit 7 is internal MCLK enable - needs to be set to 1 for DAC to work?
    Reg 0 bit [4:3] is MCLKO pin - we can disable (set to 11) since MCLKO is NC
    Reg 1 bit 0 and 1 select between PLL (0) and MCLK (1)
    Try internal PLL, see if it helps over direct input

1/14/2017
---------
Modified SPI command handling in slot controller - new msg format needs to be migrated to Python code
Seems to do something, although the bits of each byte read are shifted left one, and bit 0 is then repeated

Soldered a pigtail for 4 channels (no matter, with only 1 scaler board we can only get 2 channels)

Examining output of first 2 channels - DC offset
    1L  170 mV
    1R  640 mV
    -> bad
    DC level of DAC output pins is 1.58 V - same as CM

Now check AC...
    1L  ~40 mV (wandering... just hook up and see)
    1R  ~90 mV
    
8-ch I2S: Looks like it's working, according to ILA

Need to look at 
a) DC operating point of scaler
b) Whether DAC outputs are doing anything
    No.  Probing output 2L gives const ~50 mV
    Probably jibberish because of no clock lock

Viewing on  scope:
    1L output does... nothing, but noise and offset
    
OK, alt. strategy: try using the PLL
    If I leave registers in default config, AC on output goes away; supplyign audio doesn't do anything
    Now turn on MCLK?
    I can see a little signal at the output... and not as horrible noise.
    Hey, a 400 Hz sine wave!  But it's really small, and doesn't register on the multimeter (AC volts) either.
    That's because the level was set in SW at -60 dB.  -40 is bigger.  Big enough to look clean.
    Definitely some clipping - 1.2% THD at 1 kHz full scale
    At -20 dB?  0.1%.  Not horrible, but mediocre.
    Some may be coming from transformer due to DC offset.  But yay, DAC is working!
        Nope, still 0.1% when bypassing transformer.  0.3% at -10 dB, 0.08% at -30
        1% at full scale... Hmm.
        According to LTspice it should be 0.1%, and most of it is coming from the diff pair.
        But my diff pair bias is at 6 V instead of 8 V - 12 mA instead of 9?
        Main diff pair should be 20 mA if the right resistors were used.  Increasing bias doesn't hurt distortion in LTspice.
        0 dB FS spectrum really looks like clipping the sound card.  Back off..
        At -3 dB, No more clipping, but still 0.8% THD.  Fund at -3, H2 at -45, H3 at -74
            -> mostly 2nd harmonic, 3rd harmonic is in line with expectations
    Definitely 2 problems: DC offset due to poor MOS matching, and crappy SMD caps that leak?
        The caps could be the cause of the HD also?  Maybe not.

So, need to fix the scaler.
    DC offset may just be down to MOSFET matching.  Vgs is supposed to be 0.8-2.4 V, and I made no effort to match.
    though there's a creepy 300 mV voltage drop across the gate resistors - why is there DC current? (bad soldering/bad caps?)
    
Do all 4 channels work?  (Test and write THD at -20 dBFS)
    1L: Yes, 0.11%
    1R: Yes, 0.03%
-> NM, scaler isn't plugged in.  Need more scalers.  But can test 8 DAC channels by moving scaler once fixed.

Also, note that the DAC does not work when external MCLK is selected or when MCLK is used as the PLL source.
But how do the I2S signals get in?  maybe there is a bad connection.

1/15/2017
---------
Viewed the 11.2896 MHz clock at the DAC board on the scope today
Note: scope probe adds additional ~10 pF load; scope itself has 20 pF, but it's a 10x probe

With scope hooked up to clock, PLL recovering LRCK may not work as reliably? Not sure.

Waveform obs:
    Freq looks OK, but there might be a massive amount of jitter?  Can't resolve waveform properly on my scope.  Trigger settings seem to impact display.
    Exponential decay rising.  No flat top.  Looks like a sawtooth almost.
    Voltage range = 0.2 to 2.6 V
    Slew (1-2 V) time = 12 ns (note: scope bandwidth may be coming into play)

Probe elsewhere to see if the wave shape changed?
    At the oscillator, it's much sharper, 0 to 5 V, 4 V rise in 10 ns -> scope isn't the main factor
    
    With DAC in slot 0, it looks, possibly, a little less jitter, but peaks at 2.5 V

Note: 74VHC04 output current specced at 4 mA for 3.0 V supply
    So, with 20 pF load, that's a slew rate of 0.2 V/ns or 5 ns/V
    We see 12 ns/V which would mean the load is closer to 50 pF? 

Switching CLKSEL = 0x0D on other channels to other clock makes a difference
Faster rise time, but harder to trigger; why?
Closer to 8 ns/V; voltage range now 0--2.9 V
    e.g. we went from 50 pF to 35 pF
But then the DAC doesn't work (recovering from LRCK).

Wait: ADG1436 has some significant cap.
    Cs (off) = 23 pF
    Cd (off) = 50 pF
    Cd+Cs (on) = 120 pF
    ???
    So maybe the 7404 is fine and we're just loading the crap out of it.

Multimeter shows 195 pF from CLK0A to gnd, minus 31 pF from holding wire nearby -> 164 pF

What about from SCLK1 (output side of switch)?
    115 pF (minus about 20 from holding wire) - with DAC8 board in place
    100 pF without DAC8 board
    
Wow.  Alright, clock switching needs to be rethought.
No "smoking gun" for PLL clock and clicking issues, but it's pretty strong circumstantial evidence.

So what's the plan?  Some options (non-exclusive):
    a) Rev the scaler and IV boards for better analog performance with same DAC2/DAC8 boards.  (Need more scalers anyway...)
        This will make me feel better since I don't want DC offset going into the amps or into the analog XO input transformers
        Also provides a warmup for Eagle, PCB ordering and assembly (get the necessary tools for SMT)
    b) Do mods to the current isolator board to improve clk reliability i.e. cut/jump (say, eliminating clock switching; 44.1 OK for now)
    c) Try to get the 8 channel ADC working
        Note: LRCLK PLL trick won't work since I2S pin direction is set jointly for all 6 slot data pins
        So, if we want the ADC to output SDATA, it has to also output BCK and LRCK (i.e. I2S master)
        meaning the FPGA cannot supply LRCK
    -> This is unlikely to work given the current clock situation
       So, abandon ADC plans until next isolator rev.
    d) Try to get DAC2 and DAC8 working at same time
        Ideally this would make digital XO and analog XO possible without reconfiguring hardware--just move connectors
    e) While prototype is working with DAC2/8, design next isolator rev.
    
-- Plan selected: (a), (b), (d), (e) in that order

1/15/2017 (Later that day)
----------

Experimenting with I/V stage.
Using ideal current sources to identify fundamental distortion sources

Baseline signal is 6dB at 1k, dist is -78 dB at 2k (-84 dB), -114 dB at 3k
    Not bad, but let's see if we can knock down the 2nd harmonic

Does Wilson current mirror help?
    No.
    
How about a regular cascoded current mirror?
    No.
    
So what's the nonlinearity from?
    Base current?  Varies between 21-48 uA at full scale

Try 10x current.. (and 10x power supply)
    Now base current is 390-435 uA
    OK, that made a small difference in THD... 2nd harmonic is down to -81... obviously not worth it
    
Try 1/10 voltage gain (75 ohm resistor instead of 750)... same 10 mA bias
    This gives -14 dB signal and -109 H2 = -95 dB
    So maybe a second stage would help.
    BTW, with 20 mA bias, H2 is same
    So it's not the current but the voltage swing that seems to be causing the distortion
    Nonlinear Vce cap?
    Try boosting supply voltage, see if that's related
    30 V supply, H2 at -111, 2 dB improvement for 2x the supply voltage
    Try 1/5 voltage gain (150 ohm res)... H2 = -100, sig = -8 (-92)
    Looking at Q1 (closest to input), the emitter current is a sinewave, but collector current has distortion -94 dB down (150 ohm or 750 ohm)
    So there is some base current, and that is nonlinear
    Base voltage is moving up and down (as it should)... 88 uV
    Ic from 6-14 mA, Ib from 21-48u -> Beta = 500
    -> Darlington connect?
        This severely raises the floor of the FFT.  Why?
        Compression doesn't affect it
        Tightening abstol makes sim really slow.  Loosening it... makes no difference
        Ah. changed to save sim data starting at 1 ms, maybe there was some transient at the beginning
        Now we're talking.  H2 at -116 with 750 ohm / 10 mA (-122 rel.)
        H3 is a little higher? -134 ... so still better, just not relative to H2.

Now add the MOS follower output buffer, which will probably get replaced eventually.
    V(ivout): Signal at +6 H2 at -115 H3 at -125 (hmm.. higher H3 especially, from loading?)
    V(out):   Signal at +6 H2 at -107 H3 and higher under the numerical floor (-118)
    numerical issue (need to wait more?)
    Wait 10 ms instead of 1.... doesn't help.  Waah?  Simulation accuracy is a pain.
    For some reason, we're good at IVOUT but not on the other side of the cap.

Darlington might be too much gain, see how it introduces higher harmonics?
    -> Deal with this later.  Buy some space first.

Time for bed.  But one problem has been solved (current buffer nonlinearity).  Try the other 3 tomorrow:
    2) Output buffer without DC offset
    3) 2nd order or steeper antialias filter
    4) Practical implementation of current sources that were made ideal for this experiment
    1) Numerical problems preventing accurate sim

Also, what transistor to use?  Want high current gain that's flat with current, and low noise.
    May still have some 2SC2240 lying around.  NXP claims BC849/850 is low noise.  (BC849 = 30 V, BC850 = 45 V, C version has better current gain)
    Borbely recommends 2SC3329/2SA1316
    rljones: 2SA1015L and 2SC1815L
    Bob Cordell: 2N4401/4403
    Salas: "2N4401/4403 will come at circa 0.9nVrtHz and they are a dime a dozen. "
    Maybe noise isn't an issue here since the swing is so big.  It's not a phono stage input.

1/16/2017
---------
LTspice: examine MOS follower distortion
Bias = 1 mA, driving 10k load: not good
Bias = 10 mA, driving 10k load: good, sig -6 H2 -106 H3 -146
    But it probably won't be able to drive heavier loads: H2 = -52 H3 = -68
    -> Output needs to be complementary e.g. diamond-buffer
    Or what about a BJT?
    Nope doesn't help.
Now looking at diamond buffer with BJTs. 600 ohm load
    1 mA bias not enough
    10 mA bias: H2 -83 H3 -75
    Note: into 600 ohm, 2 V RMS = 2.83 V peak = 4.7 mA peak
    Now, with 100 ohm emitter resistors in 1st stage and 10 ohm in 2nd stage: H2 -89 H3 -101
        Note: bias currents are 2 mA and 14 mA
    I think that's good enough given the load.  With 10k: H2 -90 H3 -117
        Hmm, anyway to get H2 down a bit?  (Where does it come from?)
        
Mirroring around the input current seems hard? (what am I missing... I get -70 dB dist even with Darlingtons)

OK, for now, I give up and just hook the load resistor to the supply.
Performance simulated:
    THD in 600 ohm: H2 -97 H3 -110 (rel +6)
    THD in 10k: H2 -99 H3 -115 (rel +6)
    THD in 10k, -26 dBFS: H2 -151, others not visible (rel -20)
    Supply current: about 60 mA (1.8 W)
        Note: much of this is in output stage, can be reduced...
        Biasing = 2 mA
        DAC 16 mA neg, 11 mA pos
        Interstage buffer 4 mA
        Diamond buffer first stage 3 mA
        Diamond buffer second stage 25 mA
    Freq response
        (-3 dB) 1.6 Hz to 55k Hz
        (-0.1 dB) 11 Hz to 20k Hz
        3rd order rolloff
        70 dB stopband suppression (1--100 MHz, no parasitics)
    PSRR
        Pos supply: 0 dB (Adding RC filter just filters HF; cap has to be quite large for LF audio performance to be helped)
            Adding Darlington capacitance multiplier with 10k/10u gets us to 26 dB in most of band (21 dB at 20 Hz)
            MOSFET is same.
            However, this dramatically increases distortion because of the finite output impedance
                14 dbohm = 5 ohm, so 2.5 mA RMS gives us 7.5 mV RMS -> more than -60 dB distortion
            Power the two halves of the differential circuit from the same cap multiplier?
                With ideal current sourec there's about 500 uV left, and distortion is fine.
                -> A viable idea, I think.  Can't complain about 26 dB PSRR.
        Neg supply: 1 dB (why? current sources somehow)
            Yes.  Biasing is proportional to supply.
            Switch to LED based current sources -> 40 dB from neg supply, not bad.
            Still needs to be clean however.

Choosing output stage bias
    Decreasing the current makes THD go down with 10k load.
    3.5 mA is enough
    So what loads are we going to support?
    May also want power reduction in other places
    But deal with this later. PSRR first.  Leave at 3/20 mA (diamond 1/2) for now = 26 total for output.
    Default version: -95 -107 -140 -145 into 600 ohm, -97 -114 -140 -146 into 10k
        R16/R17 = 475 current = 2/20 mA
    Reduced version: -83 -63 -117 -99 into 600 ohm, -108 -115 -140 -146 into 10k
        R16/R17 = 2.2k current  = 0.5/2 mA
    So, choose based on whether you want heavy load drive or not.
    Also, don't overdrive internal buffer stage (or maybe you should to get more H2).  Reducing bias to gives -112 -115 -140 -146.
        R10 = 1k -> 1 mA
    Can we save any power on the input stage? (without hurting distortion)
    Not really.
    For now, compromised with 1/8 mA output stage, 2 mA internal buffer. 10k gets -101 -115 -140 -146 
        600 ohm load gets -96 -89 -141 -129
    Total power = 1.3 W -> 5.2 W for stereo DAC module
    
Noise is currently about 25 nV/rt(Hz).  -> 5 uV at output, or 112 dB SNR
    Most of this appears at V(IVOut). -> 24 nV
    What's the noise of a 750 ohm resistor? About 4 nV
    R19 and R20 are big contributors.  Investigate tomorrow.
    Interestingly, increasing them decreases the noise.  But does it have any other side-effects?
    Can get down to about 3 uV noise (116 dB SNR) with 220 ohms; doesn't seem to affect linearity (plenty of power burning headroom)

Adding some big decoupling caps on high impedance nodes helps...
    Down to 11.5 nV/sqrt(Hz) in mid/high freqs.  Knee around 100 Hz.  30 nV at 10 Hz. -> ~1.7 uV out, 120 dB SNR
    But that destroys PSRR.  Can't put any cap to ground on Vc node driving current mirror.
    With other caps, PSRR is now around 40 dB on both rails.  But output noise is back to 20 nV/sqrt(Hz).
    With Big Vc cap to negative rail it might work...22 uF (different values do different things)
        + PSRR now degrades at LF... still -26 dB at 20 Hz
        - PSRR is still good
        Noise is good
    -> We have a winner.
    
Also, we should survive an output short circuit for a time.  ~120 mA on supplies means 3.6 W for the channel with the shorted output.
    
TODO: See how much capacitance to load cap multiplier with
But otherwise this is ready to go, I think
    -> No cap needed due to filtering
    PSRR remains at 26 dB (+), 40 dB (-)

Noise is

2/11/2017
---------
Want to design an op amp I/V to compare to DSD1792 discrete version
But what op amp/topology to use?

AD844 - recommended by Pedja with TZ node loaded by resistor to reduce gain
But there are potential problems:
    1) Input stage linearity?  someone mentioned 0.03-0.07% THD which showed up in Ayre CDP output.  Stereophile review of CX-7e
    2) Buffer is bad.  Pedja said 0.5% THD.  So you'd need a buffer IC or discrete from the TZ pin.

What's wrong with AD844 or other fast CFB opamp used the standard way (resistor feedback)?
    Jocko Homo and Elso Kwak didn't like CFB 10 years ago.  Said it sounded bad.
    
Avnet has AD844 slightly cheaper than Digikey.

What to do for the lowpass filter?
    Only get 1 pole with the AD844
    Need a std op amp buffer.  georgehifi from diyaudio.com uses AD825 for 3rd order filter and likes it.  But likes discrete buffer (complementary JFET follower) better.
    Just use ADA4001-2 for the 2 differential halves.

By the way, how about AD812? Cheaper, plus 2 op amps per package.
    Specs?
    OL transresistance is 800k, -In resistance 65 ohm
    145 MHz unity gain bandwidth, 1.6 V/ns slew rate at +/- 15 V
    THD of -90 dB at 1 MHz, but fig 20 shows < -120 dB in audio band (and 2nd above 3rd)
    3.5 nV/sqrt(Hz) voltage noise, 18 pA/sqrt(Hz) current noise -> 13 nV/sqrt(Hz) at output for 2 V RMS single-ended
    This looks like the way to go

Should cancel current offset with a resistor from supply.  
    Experiment with different values?
    But the nominal should balance the 6.2 mA DC output
    And there is a DC blocking cap going into the LP filter also.
    
-> Plan. AD812 configured as recommended by AD844 datasheet for IV conv.  Then ADA4001-2 LPF with same components as discrete version.

2/12/2017
----------
3 PCBs have been designed:
    1. I/V for DSD1792 - discrete version (4 layer) 1.48 x 2.22 = 3.29 in^2
    2. I/V for DSD1792 - opamp version (2 layer) 1.48 x 1.285 = 1.90 in^2
    3. Voltage scaler/filter for AD1934 - opamp version (2 layer) 2.084 x 1.637 = 3.41 in^2

All boards DRC clean in EAGLE, CAM processed for OSHPARK

When to order boards?
    As soon as I'm confident I will be able to use boards in stereo for long term testing
    Prereqs:
        DAC2 and DAC8 working smoothly/reliably (no clock or major noise/distortion issues)
    Not prereqs:
        RPi music server (i.e. laptop hack is OK)
        ADC2 and/or ADC8 operation

What to do before ordering boards?
    1) Test DAC2/DAC8 in as-is configuration.  A) one at a time, B) both
    2) Try clock switch mod
    
Notes on the bringup process
DAC2:
    Lots of nasty noise (-66 dB) and a little sinewave (-40 dB) at 0 dBFS
    0.5 V DC offset... no, 1.15 V / 0.99 V
    Check DC op point: Where is the offset coming from?
        Supplies are OK
        Current inputs at -30, -40, -70, -180 mV
        Try reseating everything... still messy
        Try giving slots 1-3 CLK1 instead of CLK0.  OK, now I get a big sinewave with a lot of glitches.
        And the idle output is full of glitches.
        But this is a separate issue from the DC offset.
        Op amp issues with the cap there?
            LTSpice doesn't see a problem.  And I don't either since it doesn't affect feedback.  Except for stray cap.
            Check DC blocking.  Gate of MOS - either side of big resistor. R17/R27
            R17.  Top side 2.15/1.84 bottom side 2.39/2.10 top side
            R27.  2.08/1.86 bot 2.40/2.14
        Whatever.  Let's deal with clock issue first.

DAC8:
    DC offset looks familiar - 0.16 V in 1 ch, 0.76 V in other
    Got it working in slot 1 - 0.1% THD at -20 dB, 1% at 0 dB (right) 0.035%/1% at 0 dB (left)... not sure of L/R ordering
    with LRCK recovery.  Smooth operation otherwise.
    -> More confidence that clock dist is the main issue.
    
Notes on the clock hacking
    Plan: Remove IC35/36 (ADG1436), solder mini-wires across pads (adjacent) connecting CLK1
        (which is the one we are using now, it looks like... 0, 1 what's the difference)
    Got IC35 off, took several of the pads with it...
    Fortunately SCLK0/1 both have vias.  As does CLK1A.  Destruction is now accepted.
    IC36: Cleaner job the 2nd time around...
    Now we're ready to wirewrap.
        FROM: CLK1A via connected to top copper T-junction, corner of IC10
        TO: SCLK0 and SCLK1 vias - under what was IC35
        
After clock hacking mod
    Trying DAC8 in slot 1
    DC offsets about same as before
    SPI read/write fails - try reprogramming FPGA.  That fixed it.  (Bitfile stored in flash didn't support 16 bit SPI addr)
    Now we have analog out.... for a second at a time, it looks like.
    On the plus side, it looks like we can lock to MCLK as the PLL source (or LRCK)
    Audio cutting in/out might be more frequent when using LRCK?  Suggests bad connection on I2S or something.  
    More EMI floating around with faster clock edges?
    Glitches still happen after removing debug wires
    Try slot 0? -> SPI doesn't work.  Weird.
    This is slightly sad.  Try DAC2 in same slot.
        Output looks reliable, but lots of noise/HD - 2-3% at -20 dB.  Worse as ampl increases.  (But ampl is correct.)
        Probably offset related.
    Try DAC2 in slot 0
        SPI is broken.  Analog output is the same.
        -> So, it's time to fix the offset issue.
    Try both: DAC2 in slot 0, DAC8 in slot 1
        Either one works, to the same degree it worked before.
        DAC8 continuity?  Looks good.  Maybe it suppressed clock ringing or something to have them both plugged in?
        
Time to figure out what happened to DAC2 I/V (for now removed DAC8)
    Try removing antialiasing cap?  Just for giggle.  (One channel)
    Removed caps from board SN 2, and now offset is 0.21 V.  Huh?
    Check distortion..  Yeah, noise floor and distortion are lower in the right channel, which is the one I removed the cap from.
    But they are still not great (not what they were originally, in measurements.txt).  Figure out, what is going on?
    Now removed caps from SN 1.  Boom, 0.01% THD in both channels.
    Definitely a major screw-up going on with those caps.
    Try alternate mounting, one channel/polarity only?
    Tried on SN 2 (right), neater soldering under the board.  Now all kinds of shit shows up in the RTA.  0.6% distortion and some sidebands.
    Parasitics?  Offset is also back up.
    May have to do with supply somehow, but I'm not going to bother finding out.
    -> Giving up on antialias caps.  May need to leave them off 2nd version also, and use 2nd order antialias filter only.  If problem continued
    Well, what about putting them on the M1 gate?  Would that be better?
        Less offset, but still worse distortion - 0.22%
        Is it related to the kind of cap?
        Tried 1 nF polyprop cap instead.  Now we have 0.04%.  Still not right.  Backing out.
        
Installed Jung regs in all slots - seems fine
DAC2 only setup back in stereo
Listening impressions:
    Clean.  Midrange is relaxed as it should be.  Maybe a little hard (nasal?) on Eva Cassidy's voice.
    But I haven't listened in a while, and might be sick.  Ears need to warm up.
    Treble balance seems slightly off, but it's not grainy like I remember.  (Regulators?)
    Dynamics are at least making an effort.

Need to buy stuff.
    DONE PCBs (Oshpark for I/Vs-$42, ITEAD for scalers-$20)
        Except ITEAD is verifying the Gerbers for the scaler.
    DONE Parts
    DONE Tweezers
    DONE Hot air station
    DONE Raspberry Pi

2/14/2017
---------

Listening notes: 
    Alabama
        Voice sounds a little funky when loud and not in the sweet spot.  Not too familiar with the record, maybe this is baffle effects from the speaker?  Also studio processing.
        Bass sounds surprisingly lively and clean.  Again, unfamiliar record.
    Tom Harrell (trumpet jazz)
        Not grainy anymore (due to regulators, or clock changes?).  Still pretty chill, highs a little recessed.
        There is just a little edge missing, like the band is playing from within a cloud.
        The "air" is cool, like a more "analog" sound but it sounds a little fake.

Next up: Raspberry Pi music server setup for DAC2 and some software cleanup.

2/16/2017
---------
DAC doesn't work, suspecting clock issue.

2/17/2017
----------
Turns out the 5V LDO reg (which BTW has 21 V in) was putting out 1 V.  
Temporarily, replaced it with a 7805.  Listening impressions:
    Tone is more neutral, it seems.  Highs missing the fake air.  A little crisper.  
    Dynamics not impressive (but only listened to a couple of tracks).
    Overall pretty clean.  Maybe the 5 V reg was causing problems and it's got potential to be better?

Will have to debug the reg eventually.
Anyway, more important things to do: Raspberry Pi is here

2/18/2017
---------
Raspberry Pi is running (password = strawberry)
Running Python in a virtualenv might be a bad move

Got streaming working, controlled by MPDroid.  
    ALSA PCM file output piping to Python script
    Rearranged Python scripts to be more organized (SVN r116)
    
This is fun to use.  Problems:
1. Albums don't appear.  MPD thinks the only album is a Nine Days album that was MP3 instead of WAV.
    Hypothesis was that the tag parsing (ID3 format) was only being done on MP3 files.
    But WAV can contain ID3, and Windows Explorer seems to think the WAV files are properly annotated.
    -> Can try converting an album to MP3 and see if it gets picked up.
    Tried compiling latest version of MPD.  No change.
2. No volume control from the app
    Is this a client limitation or an MPD limitation?
    Long term, may need to write a separate app for controlling the configuration, volume, filters etc.

Sound seems same as before (hopefully)
    Hypothesis:
    - Using 78xx regs for +/- 15 V supply was causing grainy sound due to bad I/V PSRR
    - Bad 5V discrete reg was causing "fake air" on treble (but should probably listen to Tom Harrell again)
    - Any difference caused by clock risetime?

Need to think about the next steps, given hardware debug situation on the original DAC/ADC boards and isolator (and reg...).

2/19/2017
----------
Order of operations after thinking about planning:
1.  Try ADC boards and debugging other issues (SPI, 5 V reg) with current setup
2.  Assemble and test new DAC output boards
3.  Figure out Netflix streaming and other practical needs (i.e. someone's phone)
4.  Try digital crossover - work on speakers library

General goal: Get as far as you can with current platform, and do some extra SW/integration work for:
a) Risk reduction
b) So it's fun to use while working on next HW platform

Also consider working on measurement tools, e.g. noise amp to examine supplies/outputs.  Would help understand where problems are.

2/20/2017
---------
Listening notes: The Jayhawks
    Clean, balanced, easy to follow the counterpoint
    Highs may be a bit "crisper" than I'm used to, but not fatiguing at the low levels I listened at.
The Wallflowers
    Laid back at 80 dB.
    Didn't notice the same crispiness, but treble is generally softer on this album.
    Compressed.  Firm sound, though.  I think this is making the best of the record.
Eva Cassidy
    Amazing as always.  Hard to say anything about the sound.
Beethoven piano concerto
    Piano more engaging than I remember it.  Maybe this is just a lower noise floor (or masking?)
    Soundstage a bit unbalanced on this track (violins all seem to come from one place?)
    Acceptable microdynamics.  Overall dry sound which you'd expect from the speakers.
    
Overall, it was a very good evening.
Good time to take it down for ADC testing.

2/21/2017
----------
ADC debugging

Notes
    ACON should be 0x59 but I think I knew that already.
    Python script: runs fine, doesn't receive any audio
    Once I got a USB overflow error suggesting there was audio (intermittent if any, can't reproduce)?
    Probing nodes: 
        RST is high (good, it's active low)
        LRCK is high, BCK is low, SDATA is low
        This would seem to indicate lack of lock
    OK, the problem is that the 5 V rail is low.  Why?
        Overcurrent protection.  Why?
        Because the CM level of the input buffer is wrong.
        -2.5 V is dragging the op amp output negative, turning on the ESD clamps in the ADC.
        So the op amps are getting hot and the ADC is getting hot.
        Fixed, sort of.  Won't really be fixed until a PCB revision gives a proper input buffer.
    Now I can record samples.  But the frequency looks wrong.
    Stim freq = 1k Hz
    Recorded period = 15 samples?  Should be 44.1.. (using 500 Hz gives period = 30, same issue)
    What I do with ACON seems to not matter.  100 Hz, period = 146.8 indicating Fs = 14.68 kHz (44.1 kHz / 3)
    This would indicate that the chip is operating with the assumption of 768 Fs.
    -> Next time, check ACON for real.  (PCB probe)

2/24/2017
---------
It looks like you can only control ACON if you are in slot 0 or 2 (see slot_controller.v)
So, moved to slot 0.  Now what?
    No trouble reading samples, but they're all 0.
    Wait, now ACON has an effect.
        Default of 0x51 or no setting -> -20 dB RMS, jibberish data (wrong format?)
        Set to 0x59 -> all zeros
    Why don't we use the Logicport...
        Bad connection on I2S? Looks like I2S with noisy LRCK/BCK and zero data.
        Reseated, now LRCK/BCK look better,  but data is all zeros. (Regardless of ACON)
        
2/25/2017
---------
Investigating FPGA pinout as potential cause of ACON issue
    Spreadsheet says ACON0 is ZTEX pin D26 (FPGA P2) and ACON1 is D25 (R2)
    ACON0 -> FACON1 net on PCB
    ACON1 -> FACON2 net on PCB
    ACON0 serialized version looks fine... 0x59 at the moment.  Now probe deserialized nets?
    DC level of serialized net post-isolator is 1.65 V when 0x59... 1.24 V when 0x51. Probably working.
    It goes to pin 7 of slot 0 connector (HWCON) then into IC3 on ADC board.  I guess we have to probe that.
        It's a 74164 shift reg (clocked by MCLK) tied to a 74574 reg (clocked by SRCLK)
        DC probes on ADC board: MCLK = 1.68 V, SRCLK = 3.11 V, looking good.. ACON0 = 1.24 V, meaning things are probably connected to it
        What about ACONs going into ADC?  Have to probe across the upper pins of IC2...
        Far to near...         0001010
        With ACON set to 0xFF: 0101011 
        Let's reflow the connections on those registers...
        Now with ACON0 at 0xFF: 0011101
    Maybe there is something wrong with the ADC? I did abuse it.
        SDATA DC = 0.42 V... Logicport?  Shows 1 bit high for each of L/R, maybe the 8th bit?
        Try different ACONs...  First experiment with format.
        0xFF - 1 bit high in 8th cycle; FMT = 11 = DSD
        0xFE - 1 bit high in 8th cycle; FMT = 10 = PCM standard
        0xFD - all zeros, FMT = 01 = I2S
        0xFC - some kind of data (reasonable noise like stuff)... FMT = 00 = left-justified
    Plug in a sinewave and see.
    Small sinewave with noise on it... period = 874 cycles at 100 Hz, indicating 88.2k sample rate.
    Try changing upper bits of ACON?
        Good thing bit 2 (M/S) was stuck low?.
        0xF8 =  - looks like left justified at 88.2k  1 1 111 0 00
        0xD8 = 1 1 011 0 00.  Now LRCK is very glitchy.  (But maybe 44.1k?)
        0xE8 = 1 1 101 0 00.  Same - very glitchy.
        0xC8 = 1 1 001 0 00.  Glitchy and slower.
    Try changing HPFD? 0x38 same as F8.  
    Maybe it's still having trouble with the clock input.
        At 0x60 I get clean I2S at 29.4 kHz... 0x70, 58.8 kHz
        With everything at 0, cycle through OSR options (bits [5:3]) to see which are clean and which are glitchy.
        000 -> 0x00, clean 14.7k (single rate 768fs)
        001 -> 0x08, glitchy (single rate 512fs)
        010 -> 0x10, glitchy (single rate 384fs)
        011 -> 0x18, glitchy (single rate 256fs)
        100 -> 0x20, clean 29.4k (dual rate 384fs)
        101 -> 0x28, glitchy (dual rate 256fs)
        110 -> 0x30, clean 58.8k (quad rate 192fs)
        111 -> 0x38, clean 88.2k (quad rate 128fs)
    Trying slot 1 to see if clocking or I2S makes any difference.  
    Slot 0 DIR pin is grounded.  ACON controlled via slot 0.
        000 -> 0x00, clean 14.7k (single rate 768fs)
        001 -> 0x08, glitchy (single rate 512fs)
        010 -> 0x10, glitchy (single rate 384fs)
        011 -> 0x18, glitchy (single rate 256fs)
        100 -> 0x20, clean 29.4k (dual rate 384fs)
        101 -> 0x28, glitchy (dual rate 256fs)
        110 -> 0x30, clean 58.8k (quad rate 192fs)
        111 -> 0x38, clean 88.2k (quad rate 128fs)
    Now, can we get I2S to work?  Add 01 to end...
        Logicport looks plausibly I2Sey.

Wait: Datasheet says "The PCM1804 needs RST = low when logic levels on the OSR2, OSR1, and OSR0 pins are changed."
    Likewise for the other config pins.
    So, let's implement this... now have ENTER_RESET (0x4B) and LEAVE_RESET (0x4C) commands.
    Reset functionality works.  But I2S output is still glitchy in the clock modes we care about.
    CLK0 reaching FPGA is stable 11.28953 MHz

Options..
    Look at clock signal reaching ADC pin?  (Then can decide to adjust clock dist)
        Before that, try adding 18pf cap on CLK line.  Doesn't seem to have an effect either on working or nonworking mode.
    ACON0 pins could be flaky... I did get some anomalous readings with the multimeter, but it's hard to tell if I'm probing accurately.
        Adding solder paste and reflowing digital ICs, ADCs and connector didn't help.
    ADC could be bad (heat damaged?)
        Have another one.  Try the SMT heat gun tomorrow, I guess.
        May want to retry current one- maybe some solder underneath chip (it's not flat on the board)

2/26/2017
---------
Tried more hardware debugging around ACON:
    Replaced ADC.  No difference.
    Replaced registers.  Now can't get anything besides all zeros for ACON (i.e. 14.7kHz).
    Check pinouts: LVTH574.. bad OE?  No... but maybe bad VCC.  Add a wire connection in case PCB pad is lifted.
        Fixing that didn't affect behavior.  ADC acts like its control pins are low.
        But it's worth checking the other connections around those chips.
        SRCLK to reg: OK
        data, clock to shift reg: data is OK, clock is OK
        CLR is high
 
Are there other places I use this deserializer circuit, and do they work?
    Pattern is SRCLK falls for half a cycle during positive phase of MCLK
    Yes: clock selects, and ADC/DAC chip select for SPI
    Have had some SPI problems...
    Since clock select mux is removed... can experiment with that.
        Setting CLKSEL to 0x03 (0011) shows:
            CLKSEL3 = 0.05 V
            CLKSEL2 = 2.41 V (0.72x)
            CLKSEL1 = 3.32 V
            CLKSEL0 = 2.07 V (0.62x)
        Hmmmm...
            CLKSEL = 0x01: 0, 0, 2.24, 1.94
            CLKSEL = 0x02: 0, 2.57, 3.32, 0
        Looks like a timing violation to me... or a misunderstanding of how the shift reg is supposed to work.
        Output (574) is a DFF positive edge triggered.

Much debugging (2+ hr) later...
Looks like there were 2 problems
    1) Bad timing going into shift reg. due to launch on rising clock edge
    2) Bad connectivity on PCB between shift reg and DFF
Now, I can get good data at 44.1k.  There might be a bit shift though.
How's the performance?
    Datasheet says to expect around -102 dB THD+N.
    I see a lot of power supply crap.  Also other odd spurs (can't tell if they're from the soundcard or not).
    And the harmonics are around -90 dB (HD2/3 each around -93 dB).

OK, let's bring the DAC back.
    Had to modify RTL to allow slot 1 to set ACON0
    Reason: for mechanical clearance of PCBs (I/V stages), DAC must be in slot 0 and ADC in slot 1.
    Now there's a problem: ADC output is intermittent when both it and DAC are plugged in.
    Presumed reason: bad connection
        But try it the other way round, anyway.
        DAC appears to work.  But ADC doesn't come up and do anything with its I2S port.
        Scope?  Clock is OK.
        A5V is at 1.69 V... (isolator board has 5.01)
        Bad connection.  Reflowed slot connector pin, seems OK.  
        But there are still a bunch of other bad connections on the ADC board, relating to ACON at least.
        -> Retire this board.  The concept was proven, the execution was bad.

Time to look at the new I/V
    Doesn't blow anything up.  
    Follow up.
        Supplies: -15.42 +15.45
        Offset (mV): IIN- 25 IIN+ -163 VOUT- -108 VOUT+ -80
        Bias: voltages across (pos half)
            (pos rail) R26=15.45/13.90 (1.55)  R27=15.45/14.09 (1.35) R28=14.49/0.35 R14=14.1 
            (neg rail) R23=-9.85 R22=-9.85 R15=-14.1 R17=-14.1
        LTSpice expected for R22/23 was -11.4
        Others are reasonable.  1.3 V drop across res is... possibly heating up bias?
            Vpb = +13.65, Vnb = -13.64 (1.8 V drop on LED)
            LTspice expects 1.7 V across the LED and 1.03 V across the resistors.  I have 1.8 and 1.35 or so. (+30%)
                -> BC817 have lower Vbe than expected.  OK.
            LTspice expects 6 V (13.5 - 10 mA * 750 ohm) at IVOut.  I have 0.35 V (14.5 - 19 mA * 750 ohm).
        Now instead of 16.5 mA in 62 ohm and 10.3 mA in 100 ohm, I have 21.7 and 13.5.
        220 ohm resistors show Wilson mirror current is 25 mA instead of expected 16.5.
            -> Mirror appears to be working.  But R26 has too much current due 1.55 V drop instead of 1.03.
            Replace with 100 ohm?  That would bring current to 15.5 mA.

    Given drop on R26 (1.55 V), R27 (1.35 V), to get 16.5 mA and 10.3 mA, I need 94 ohm and 131 ohm.
    But I only have 100 ohm, 200 ohm, and higher values. Paralleling?
    First investigate other half:
        R46: 15.45 - 13.95 = 1.50
        R47: 15.45 - 14.08 = 1.37
    All LEDs are around 1.8
    Let's try:
        R26 -> 100 ohm (15.5/15 mA mA)
        R27 -> 162 ohm (8.3/8.5 mA)
        Difference of currents = 7.2/6.5 mA
        Meaning: upper half will sink 1 mA too little, dragging output up by 0.75 V.
        But that's better than what we're doing now, which is sinking 9 mA too much and collapsing the output entirely.

Maybe I need to switch from green to red LEDs?  Red may have smaller voltage drop.
Nope, trying 100/162 ohm.  Seems to fix the most egregious issue.  IVOut is now 7.88 V which is OK I guess (target was 6).
    Note: fix on negative half also.  But should be able to test THD as is.  (Nope... then cap multiplier won't work.)
    
Performance: Some quick measurements
    Looks like -95 dB or so at full scale.  -100 dB at -14 dB and lower.  Mostly 2nd harmonic.  Some 3rd.
        Note: Sound card loopback shows the floor is around -106
    Almost what I was hoping for.  Investigate more later?  Maybe.   Want to listen first.
    Worse at higher/lower frequencies - could be isolation transformer, could be something else
    
Listening notes: Purple I/V boards
    Tonally, back closer to what I remember from the CD player.  But not quite.
    Bass was loose at first (amp warming up?) and treble a little hard/opaque e.g. "I Feel Lucky"
    Still laid back, but not as much as previous version.  Especially in the mids
        Guns and Roses still sounds squashed, with a piercing guitar, but more tolerable than I remember
        Toy Matinee is relaxed except for the one part towards the end of "Last Plane Out"
        Wallflowers is relaxed
    Highs a little sharper/shimmery.
        Eva Cassidy tracks more alive
    Surprising ass kicking capability.
    Piano leaps out from the darkness (spent a while listening to quiet Schubert)
        Classical may be as engaging as previous version, will have to listen more
-> Seems more neutral, but its possible something has been lost since the last version.
    Will have to listen more.

2/27/2017
----------
Some more listening, didn't pay close attention.  Sounded fine.

Soldered op amp IV board.  Not tested yet.

3/2/2017
--------
Did a quick comparison of "old" and "new" discrete IV stages while friends were over.
    Jenny Scheinman, relatively quiet
    Old was definitely softer IMO.  Mike thought this was a negative, but I thought it was a positive.
    Should investigate more carefully on the bench and experiment with discrete IV.   
        Cap related distortion?
        DAC loading difference with 3.3n IV conversion bypass?

Tried opamp IV.
    Turned on, was quiet for a few seconds and made some nasty sounds.  (No damage apparent.)
    Appears to be oscillating.  Fixed some solder joints, didn't help.
    Need to try with fewer caps.  Might just need more careful layout.

Next up:
    a) DSD1792 I/V comparison experiments
    b) AD1934 prep/testing - prepare digital crossover using speakers library
        (want to be ready to try it out when the XLR connectors arrive)

3/3/2017
--------
A little more listening to V2 discrete I/V.
    Seems to be growing on me.
    Amazing treble (realism? maybe) on Stanley Clarke Trio
    Everything seems in balance, even at a higher volume level.
    Not relaxed, but not fatigued either.
    May be more transparent in the mids.  Bass could be a little light?  Hard to tell.
    Is it breaking in, or are my ears breaking in?
    Should probably listen more when people aren't around.
    
Another try for opamp I/V.
    Current FB op amps don't like caps in the feedback network.
    Removed 3.3n lowpass caps.
    Changed 4.7n to 3.3n in LPF to keep response reasonably flat.
    Result: Distortion
    The circuit is really sensitive to stray capacitance.
    -> Next thing to try will be fiddling with power supply bypassing - remove (short) ferrite bead L52?  
    But do this next time you have the platform on the bench.

3/4/2017
--------
Plan: 
    a) Test 8-ch DAC and try speakers lib (so we're ready for XLRs)
    b) Explore variants on discrete IV stage in more detail (caps as distortion source?)
    c) Try 8-ch ADC again.  Loopback would be great.
    
Discrete IV stage comes first
Captured spectrums at 1k and 5k.  
    Some extra spurs at HF, would like to see them gone.  
    Also want higher order HD gone.
    Left and right are similar.
Also found that turning on soldering iron makes the noise floor go up.
Also found that LF distortion (-60 dB at 50 Hz full scale) was mostly caused by isolation transformer.  
    About -86 dB without isolation transformer.  Decent, but maybe should be improved?
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

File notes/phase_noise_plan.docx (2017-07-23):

Audio clock distribution prototyping - Phase noise measurement plan

Author: Michael Price <price@kilentra.net>

Background

I work for Analog Devices (Cambridge, MA), but this is a hobby project not sanctioned by the company. In other words, low priority.

In my spare time, I’m making a board that allows up to 4 audio DAC/ADC modules to be plugged in with a standardized interface. Each module can be either 2-channel or 8-channel. The intent is to support various audio system configurations (digital crossover/equalization, music recording, multichannel, etc.) and facilitate experimentation. The design will be open sourced after I test a complete prototype.

The system has two clocks, 22.5792 MHz and 24.576 MHz. At any time, one of the clocks is active depending on the desired audio sample rate (44.1 kHz vs. 48/96/192 kHz). The board has to perform this 2:1 muxing and distribute the selected clock to the 4 modules (over about 12” or 300 mm of PCB) and to an FPGA that buffers the audio samples.

Audio enthusiasts can be particular about the quality of the clocks provided to their DAC/ADC chips. Phase noise in the clock is one of the error sources, in addition to the converter itself and the analog interface (filtering and/or I/V conversion). Some audio DAC designs employ high performance oscillators (positioned in proximity to the DAC chip), extensive supply filtering, and/or mechanical isolation to minimize phase noise. The errors are small, and I’m not very experienced with the subjective impacts. However, I would like to ensure that my clock distribution does not significantly degrade the performance of the oscillator, or at least quantify the degradation if it is measurable. The intent is to make other hobbyists comfortable using the platform even if they have concerns about phase noise.

Another intent of this measurement is to teach myself about the impact of board-level design choices, which is why I constructed options to evaluate different oscillators and clock distribution parts. The options are listed below.

Device under test

The prototyping setup consists of two boards: a clock source and clock receiver.

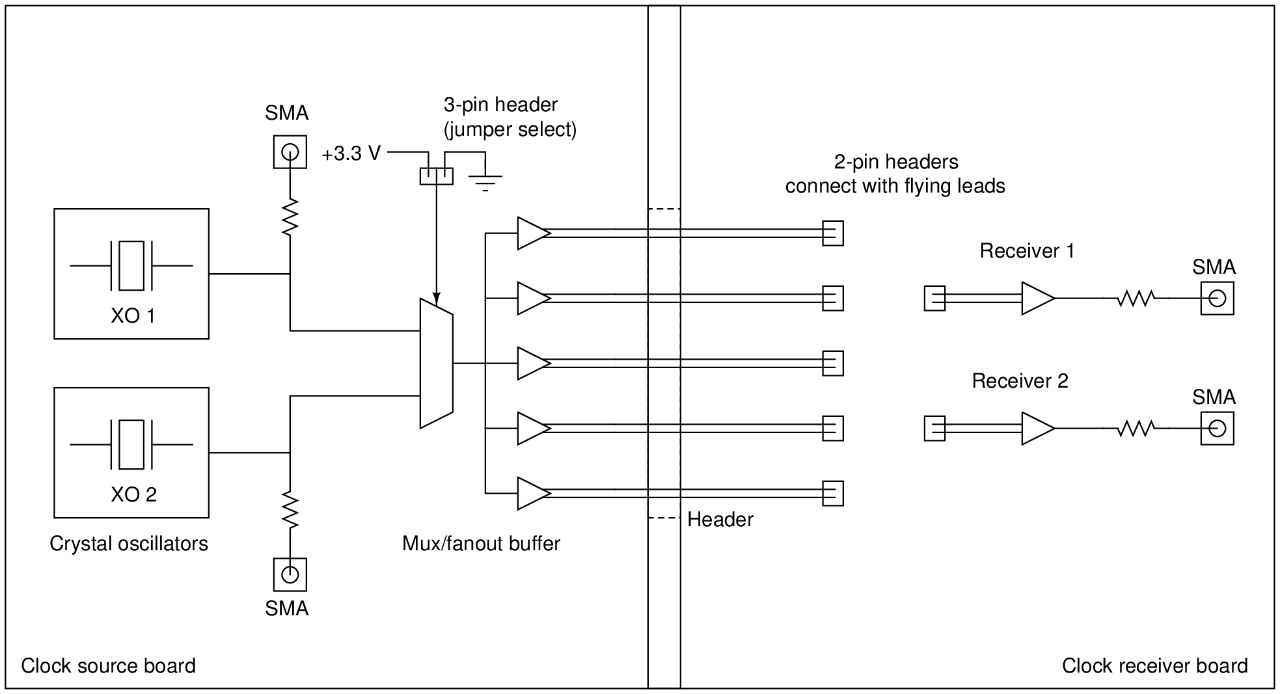
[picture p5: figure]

There are two interchangeable clock source boards:

- One clock source uses a 74-series mux and standard LVDS transmitters to drive differential outputs. It is populated with two crystal oscillators (selectable by jumper):
  1. Epson SG-210STF (2.5x2.0 mm SMD), 22.5792 MHz. Specified phase noise is -145 dBc/Hz at 1 kHz offset.
  2. Crystek CCHD-957 (14x9 mm SMD), 22.5792 MHz. Specified phase noise is -149 dBc/Hz at 1 kHz offset. (-97 dBc/Hz at 10 Hz offset)
- The other clock source uses an ADCLK948 to perform muxing and drive differential outputs. Its oscillators are:
  3. Crystek CCHD-957 (14x9 mm SMD), 24.576 MHz. Specified phase noise is -149 dBc/Hz at 1 kHz offset. (-98 dBc/Hz at 10 Hz offset)
  4. Tentlabs XO (11x11 mm DIP), 8.4672 MHz. Specified phase noise is -151 dBc/Hz at 1 kHz offset. (-93 dBc/Hz at 10 Hz offset)

Each clock source board has 5 differential clock outputs routed to a 0.1”-pitch header that connects to a socket on the clock receiver board. (These outputs are named CLK0, CLK1, CLK2, CLK3, and CLKF.)

There are two receivers (differential to single-ended converters) on the clock receiver board:

- One uses a standard LVDS receiver.
- The other uses an AD9515.

Each of these receivers has a 2-pin 0.1” header for differential input and is AC coupled by 10 nF capacitors. Meanwhile, the 5 outputs of the clock source are routed (over traces from 3.5” to 12” in length) to 2-pin 0.1” headers. One of these can be connected to each receiver using jumper wires or zero-ohm resistors.

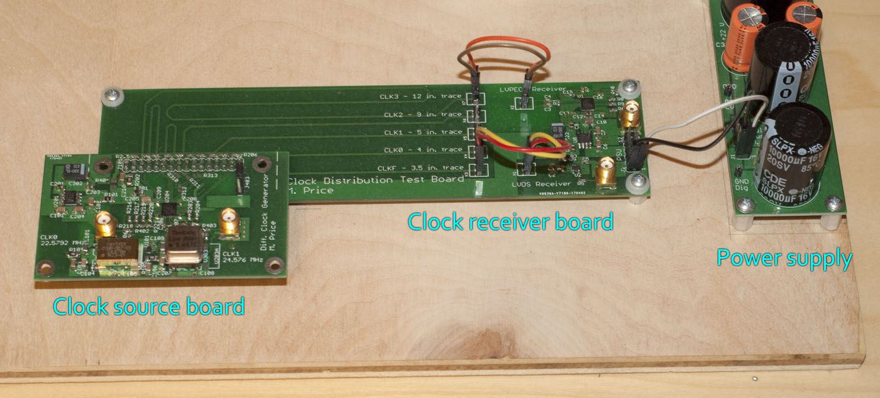
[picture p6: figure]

QUESTION: Any obvious problems with this design?

QUESTION: Would this DUT require metal shielding to obtain the desired performance?

QUESTION: Each SMA connector is connected to its CMOS output pin through series resistance. Is the value of the resistor important? If so, what should it be?

Measurements so far

I confirmed that the boards are functional: 3.3 V single-ended clock outputs appear with the right frequency for each oscillator.

TODO: Test with a 50 ohm load and/or attenuator.

SAFETY WARNING: The linear PSU has exposed connections that carry high voltages, including the 120 V AC input. To minimize risk, no one should reach into the open chassis while it’s powered on, or touch it except to switch the power off. Also, the filter capacitors retain charge after AC power is removed. Any changes to power supply connections must be made carefully (this should not be necessary as part of the phase noise measurements).

Measurement plan

Equipment:

- Prototyping chassis with PSU and clock boards installed
- Phase noise analyzer with appropriate reference source
- SMA cables and attenuators as needed
- SPL meter for vibration sensitivity tests

QUESTION: What attenuator configuration should be used for a 3.3 V single-ended source?

QUESTION: What reference sources (VCO) are available and which should be used? The E5505 manual shows that the 8662/3A has better close-in performance than other sources, but the numbers still seem high compared to the crystal oscillator specifications (maybe because the frequencies are different).

The frequency offset range of interest is from 10 Hz to half the oscillator frequency (a constant limit between 1-4 MHz for all tests would be fine). I would ideally like to obtain measurement files on a USB stick (or, failing that, images of the spectrum display for each measurement).

I envision that some setup adjustments (and possibly revisions to the DUT hardware) may be required to get the best measured performance.

Part 1: oscillators

The first set of measurements is to capture the differences between the three available types of oscillators. The clock receivers are not connected or used. We only observe the 3.3 V CMOS output directly from the oscillator.

1. Install clock source board 1. Place the oscillator select jumper on pins 1-2. Connect the phase noise analyzer to SMA connector J401. Power up the PSU and capture the phase noise spectrum.
2. Power down the PSU. Move the oscillator select jumper to pins 2-3. Move the phase noise analyzer to SMA connector J402. Power up the PSU and capture the phase noise spectrum.
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

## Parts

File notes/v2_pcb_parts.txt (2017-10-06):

iv_diff_v2 parts - nonstandard
-----------------

100 uf tant 399-5214-1-ND 
22 uf tant 399-3746-1-ND
10 uf tant 399-3734-1-ND 

1.5 nf np0 1276-2814-1-ND
3.3 nf np0 490-3351-1-ND
4.7 nf np0 445-2333-1-ND

1 uf mkt box 399-11451-1-ND 

LED 1206 160-1456-1-ND

BC807 PNP SOT23 BC807-40LT1GOSCT-ND 
BC817 NPN SOT23 BC817-40LT1GOSCT-ND 

scaler_v2 parts (if not listed above)
----------------

33 pf np0 1276-1252-1-ND
220 pf np0 399-8167-1-ND
270 pf np0 478-1485-1-ND
470 pf np0 399-1213-1-ND

ADA4001-2 ADA4001-2ARZ-R7CT-ND 

Other notes
------------
0.1u 1206 NP0 cap: 490-6505-1-ND (warning: expensive at $15 for 100)
600R 1206 ferrite bead: 732-1623-1-ND (expensive at $23 for 100)

isolator and carrier parts
--------------------------
2x24 0.1" female header with 0.325" insulation height: 929975E-01-24-ND

4-40 Al standoff M/F 1/4" high: 36-8714-ND 

Diode: Panasonic DB2W40300L DB2W40300LCT-ND  has 40V, 3A, 50 pF cap, 15 ns trr - Schottky
    Use for 7 V supply: SOD-123F 

    ES2AFSCT-ND  has 20 ns trr, 18 pf - not Schottky (50V 2A)
    I think this is good for the +/- 22 V supply.  Package = DO-214AA (SMB) 

How much cap do you need?
    1 A load, 100 mV droop at 120 Hz: 83000 uF.
    That sounds excessive.  Try 1/5 of that.
    10000 uF cap across +/- (50 V rated), one 1000 uF cap (30 V rated) from each rail.
        10k uF 50 V: 338-1568-ND (snap-in) - $4, 10mm spacing, 30x40mm
        1000 uF 35 V: 493-16077-1-ND  (SMD 14x14 mm) or 399-6120-ND  (TH 13mm D x 27 mm H, 5mm spacing)
    For 5V supplies: 16 V rated caps
        1k uF 16 V; 399-6082-ND - 10x21mm can, 5mm lead spacing
        10k uF 16 V: 338-1564-ND  - snap in with 10mm lead spacing, 22x30mm
    10 uF film bypass.
        399-12458-ND - 26.5x8.5x18mm box with 22.5mm spacing, $2.64
        Or a ceramic/tantalum one would be cheaper and in this app, just as effective. 399-8336-1-ND 2413
        Nice low-Q characteristic with ~0.1 ohm from 10k to 3meg
    Series power res.?  (to limit charging current)
        Leave space for 1 ohm or 0 ohm jumper... 2512

Also: AC input filter?

Clock parts
-----------
10u 25V 1206 cap: 1276-1804-1-ND 
1u 25V 0805 cap: 399-8004-1-ND
330u tantalum cap: 718-1038-1-ND  2917 pkg 0.287" L x 0.169" W (7.30mm x 4.30mm) 
SMA conn $2.86 CONSMA001-SMD-G-ND 

Regulator and regulator-testing parts
-------------------------------------
16V SOD-123 zener DDZ16Q-7DICT-ND 
15V DDZ16Q-7DICT-ND 
10V DDZ10C-7DICT-ND 
25 ohm 10W resistor with small footprint: TNP10SC25R0FE-ND 
15V SOT-223 Reg LM2940IMP-15/NOPBCT-ND 
-5V reg (DPAK) MC79M05CDTRKGOSCT-ND 

100uf 35v cap with low ESR: PCE4554CT-ND $0.48/ea qty 10 (Panasonic size code D8)... taller version of D, 7.7 mm high
    The larger, lower ESR version is PCE4442CT-ND $.62/ea qty 10 (size code F)... 8mm dia 10mm high
    These are better than the FC of the same size (obsolete... even capacitors get better)
    The low ESR through hole series is FM, which is about the same performance as the FP
    -> Use FP size F
    
D2PAK version of D44H11: 497-15455-1-ND (D45H11: MJB45H11GOS-ND )

6.8 V SOD-123 diode: BZT52C6V8-FDICT-ND 
3.0 V version BZT52C3V0-FDICT-ND 

Surface mount headers for jumpers etc.
    5x2 header 952-2842-ND $0.63 https://cdn.harwin.com/pdfs/M20-876.pdf
    1x2 952-1913-ND $0.24 
    1x3 952-1951-ND $0.27
    1x4 female  	S5596-ND  $0.83
    
1000uf 50v cap UVY1H102MHD-ND

V2 module parts

2200uf, 10 V cap for reference filtering
    PCE3456CT-ND $1.32  Size code H13
    
10uf, 16 V cap for +/- 5 V opamp supply bypassing, and AKM supply bypassing
    PCE4179CT-ND  $.32  Size code B

-5 V reg ADP7182ACPZ-5.0-R7CT-ND $4.00

6.8 V SMB zener diode

1uf 0603 X5R cap for ADM7160 decoupling: 587-4281-1-ND

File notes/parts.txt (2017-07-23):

Connectors
----------
Consider polarized headers from Futurlec

Isolator to audio slots: 30-pin 0.05" x 0.05"
Vertical SMD receptacle 	609-1551-ND
Right-angle T/H header      609-3174-ND

Isolator to power regulators: 3-pin 0.1" breakaway
Vertical T/H receptacle 36  929850E-01-36-ND
Right-angle T/H header 36   S1111E-36-ND
Vertical T/H header 36     	S1011E-36-ND

FX2 receptacle:     FX2-100S-1.27DS(71)    H10644-ND

Chips
-----
ADuM3400                ADUM3400CRWZ-ND
ADuM3401                ADUM3401CRWZ-ND (2 samples ordered)
ADuM3402                ADUM3402CRWZ-ND
DSD1792A                296-21534-1-ND (2 samples ordered)
PCM1804                 PCM1804DB-ND (2 samples ordered)
AD1934                  AD1934YSTZ-ND (2 samples ordered)
AD1974                  AD1974YSTZ-ND (2 samples ordered)
ADG1436                 ADG1436YRUZ-ND (not available)
74VHC164 (8-bit SIPO)   TC74VHC164FTMCT-ND
74VHC165 (8-bit PISO)   TC74VHC165FTMCT-ND
74FCT2574 (8-bit D)     296-13635-1-ND
74LTVH574 (8-bit D)     296-8736-1-ND
AD844                   AD844JRZ-16-ND
LM358 (cheap opamp)     LM358MXFSCT-ND
74VHC02 quad NOR        74VHC02MTCXCT-ND
LM317 D2PAK             LM317D2TGOS-ND

LM329 (6.9 V) TO-92     LM329DZ-ND
ADR441 (2.5 V) MSOP-8   ADR441ARMZ-ND       

Actives
-------
BC856B PNP SOT-23       BC856BMTFCT-ND
BC846B NPN SOT-23       BC846BMTFCT-ND
D44H11 DPAK             MJD44H11TMCT-ND
D45H11 DPAK             MJD45H11TMCT-ND

MSR860 soft recovery    MSR860GOS-ND

1N5235B (DO-35 6.8V)    1N5235BFSCT-ND         
1N5225B (DO-35 3.0V)    1N5225B-TPCT-ND 

Green LED SMD 1206      160-1169-1-ND

Passives
--------

PSU filter caps
0.1u 50V SMD 1206 ceramic           399-1248-1-ND
10u 20V SMD 6032-28 (6x3mm) tant    718-1043-1-ND
22u 6.3v SMD 3216-18 tant           478-3865-1-ND
47u 6.3v SMD (4.3x4.3mm) lytic      PCE3863CT-ND            Panasonic Size Code B
120u 6.3V SMD (6.60mm x 6.60mm)     493-2985-1-ND           Panasonic Size Code C
120u 25V FC radial              	P10270-ND    

Ferrites
Bead SMD 1206                       732-1625-1-ND
    -> 7/9/2017: Should use 732-1623-1-ND instead, higher current

Resistors
10k 1/4w SMD 1206 thick film        RHM10.0KFCT-ND

Film signal caps
0.1u 50V SMD 1913 film              PCF1561CT-ND
1n SMD 1206 film

Power
-----
AC receptale            Q212-ND

Other things to get
-------------------
Electret capsule        P9965-ND        (Note: perform Linkwitz 3-wire mod)

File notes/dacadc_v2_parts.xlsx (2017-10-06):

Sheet: parts to order
Parts for 1x DAC2v2, 1x ADC2v2
Desc | Qty needed | Qty on hand | Qty order | Supplier | Part num | Notes
ADA4932-2 24 pin LFCSP | 1 |  | 1 | Arrow
AD9515 | 2 |  | 2 | Arrow
ADA4899-1 8 pin LFCSP | 4 |  | 4 | Digikey |  | Rrrr, Arrow didn't have them
ADA4004-4 SOIC14 | 1 |  | 1 | Arrow
ADM7154 SOIC8 | 2 |  | 2 | Arrow
ADM7160 5-lead TSOT | 1 |  | 1 | Arrow
ADP7142 5-lead TSOT | 2 |  | 2 | Arrow
ADP7182 5-lead TSOT | 2 |  | 2 | Arrow
1u box film cap | 4 |  | 4 | Digikey | 399-11451-1-ND
15n 0603 NP0 cap | 2 |  | 2 | Digikey | 399-10044-1-ND
1n 0603 NP0 cap | 4 |  | 4 | Digikey | 445-15236-1-ND
3.3n 0603 NP0 cap | 4 |  | 4 | Digikey | 445-16162-1-ND
4.7n 0603 NP0 cap | 4 |  | 4 | Digikey | 399-14206-1-ND
1u 0805 cap | 8 |  | 10 | Digikey | 399-8004-1-ND
10u 1206 cap | 19 | 10 | 10 | Digikey | 1276-1804-1-ND
4.7u 1206 cap | 1 |  | 10 | Digikey | 1276-6706-1-ND
LF50ABDT (5 V, DPAK regulator) | 2 |  | 2 | Digikey | 497-8344-1-ND
4 pin female 0.1" header | 4 | 0 | 4 | Digikey | S7037-ND
10u Panasonic B-size electrolytic cap | 20 |  | 25 | Digikey | PCE3878CT-ND
2200u Panasonic H13-size electrolytic cap | 3 |  | 3 | Digikey | PCE3456CT-ND
AK4490 | 1 |  | 1 | Digikey | 974-1060-1-ND
AK5572 | 1 |  | 1 | Digikey | 974-1116-1-ND
2.49 ohm 0603 resistor | 4 |  | 10 | Digikey | 311-2.49HRCT-ND
10 ohm 0603 resistor | 8 |  | 10 | Digikey | 311-10.0HRCT-ND
10.5 ohm 0603 resistor | 4 |  | 10 | Digikey | 311-10.5HRCT-ND
24.9 ohm 0603 resistor | 4 |  | 10 | Digikey | 311-24.9HRCT-ND
45.3 ohm 0603 resistor | 4 |  | 10 | Digikey | 311-45.3HRCT-ND
90.9 ohm 0603 resistor | 4 |  | 10 | Digikey | 311-90.9HRCT-ND
249 ohm 0603 resistor | 8 |  | 10 | Digikey | 311-249HRCT-ND
887 ohm 0603 resistor | 4 |  | 10 | Digikey | 311-887HRCT-ND
100k 0603 resistor | 8 |  | 10 | Digikey | 311-100KHRCT-ND
74164 TSSOP14 | 1 |  | 1 | Digikey | 1727-6656-1-ND
DG9424 switch TSSOP16 | 2 |  | 2 | Digikey | DG9424EDQ-T1-GE3CT-ND
74574 TSSOP20 | 1 |  | 1 | Digikey | 1727-6472-ND
10n 0402 cap | 8 | 15 | 0 | N/A
0.1u 0603 cap | 32 | 100 | 0 | N/A
10n 0603 cap | 4 | 7 | 0 | N/A
330u 7343 tantalum cap | 2 | 2 | 0 | N/A
D44H11 DPAK | 1 | 2 | 0 | N/A
D45H11 DPAK | 1 | 2 | 0 | N/A
27 pin male 0.1" header | 4 | Many | 0 | N/A
0 ohm 0603 resistor | 4 | 8 | 0 | N/A
1 ohm 0603 resistor | 3 | 7 | 0 | N/A
22.1 ohm 0603 resistor | 5 | 10 | 0 | N/A
49.9 ohm 0603 resistor | 13 | 18 | 0 | N/A
100 ohm 0603 resistor | 6 | 10 | 0 | N/A
825 ohm 0603 resistor | 2 | 8 | 0 | N/A
1k 0603 resistor | 6 | 7 | 0 | N/A
4.12k 0603 resistor | 2 | 9 | 0 | N/A
Ferrite bead 1206 | 3 | 5 | 0 | N/A
MMSZ5235B SOD-123 | 2 | 8 | 0 | N/A
1u 0603 cap | 3 | 2 | 10 | Digikey |  |  | Added just before purchase

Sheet: parts on pcb
Board | Desig | Value | Pkg
adc | C37 | 10n | C0402
adc | C38 | 10n | C0402
adc | C39 | 10n | C0402
adc | C40 | 10n | C0402
dac | C37 | 10n | C0402
dac | C38 | 10n | C0402
dac | C39 | 10n | C0402
dac | C40 | 10n | C0402
dac | C28 | 1u | C050-050X075
dac | C53 | 1u | C050-050X075
dac | C61 | 1u | C050-050X075
dac | C69 | 1u | C050-050X075
adc | C1 | 0.1u | C0603
adc | C2 | 0.1u | C0603
adc | C3 | 0.1u | C0603
adc | C8 | 0.1u | C0603
adc | C11 | 0.1u | C0603
adc | C12 | 0.1u | C0603
adc | C13 | 0.1u | C0603
adc | C16 | 0.1u | C0603
adc | C19 | 0.1u | C0603
adc | C20 | 0.1u | C0603
dac | C1 | 0.1u | C0603
dac | C2 | 0.1u | C0603
dac | C3 | 0.1u | C0603
dac | C7 | 0.1u | C0603
dac | C9 | 0.1u | C0603
dac | C11 | 0.1u | C0603
dac | C13 | 0.1u | C0603
dac | C15 | 0.1u | C0603
dac | C23 | 0.1u | C0603
dac | C24 | 0.1u | C0603
dac | C48 | 0.1u | C0603
dac | C49 | 0.1u | C0603
dac | C56 | 0.1u | C0603
dac | C57 | 0.1u | C0603
dac | C64 | 0.1u | C0603
dac | C65 | 0.1u | C0603
dac | C72 | 0.1u | C0603
dac | C73 | 0.1u | C0603
dac | C74 | 0.1u | C0603
dac | C75 | 0.1u | C0603
dac | C81 | 0.1u | C0603
dac | C82 | 0.1u | C0603
adc | C33 | 10n | C0603
adc | C34 | 10n | C0603
dac | C33 | 10n | C0603
dac | C34 | 10n | C0603
adc | C4 | 15n | C0603
adc | C5 | 15n | C0603
dac | C25 | 1n | C0603
dac | C50 | 1n | C0603
dac | C58 | 1n | C0603
dac | C66 | 1n | C0603
adc | C18 | 1u | C0603
dac | C18 | 1u | C0603
dac | C77 | 1u | C0603
dac | C26 | 3.3n | C0603
dac | C51 | 3.3n | C0603
dac | C59 | 3.3n | C0603
dac | C67 | 3.3n | C0603
dac | C27 | 4.7n | C0603
dac | C52 | 4.7n | C0603
dac | C60 | 4.7n | C0603
dac | C68 | 4.7n | C0603
adc | C36 | 1u | C0805
adc | C42 | 1u | C0805
adc | C43 | 1u | C0805
adc | C71 | 1u | C0805
dac | C36 | 1u | C0805
dac | C42 | 1u | C0805
dac | C43 | 1u | C0805
dac | C71 | 1u | C0805
adc | C17 | 10u | C1206
adc | C29 | 10u | C1206
adc | C30 | 10u | C1206
adc | C31 | 10u | C1206
adc | C32 | 10u | C1206
adc | C35 | 10u | C1206
adc | C41 | 10u | C1206
adc | C44 | 10u | C1206
dac | C10 | 10u | C1206
dac | C17 | 10u | C1206
dac | C20 | 10u | C1206
dac | C29 | 10u | C1206
dac | C30 | 10u | C1206
dac | C31 | 10u | C1206
dac | C32 | 10u | C1206
dac | C35 | 10u | C1206
dac | C41 | 10u | C1206
dac | C44 | 10u | C1206
dac | C76 | 10u | C1206
adc | C6 | 4.7u | C1206
adc | C45 | 330u | CT7343
dac | C45 | 330u | CT7343
adc | U12 | LF50ABDT | DPACK
dac | U12 | LF50ABDT | DPACK
dac | Q1 | D44H11MT | DPAK
dac | Q2 | D45H11MT | DPAK
adc | U2 |  | LFCSP24
adc | U6 | AD9515 | LFCSP32
dac | U6 | AD9515 | LFCSP32
dac | U2 | ADA4899-1 | LFCSP8
dac | U7 | ADA4899-1 | LFCSP8
dac | U9 | ADA4899-1 | LFCSP8
dac | U10 | ADA4899-1 | LFCSP8
adc | SV1 |  | MA04-1
adc | SV2 |  | MA04-1
dac | J2 |  | MA04-1
dac | J3 |  | MA04-1
adc | J1 | MOD-V2 | MOD-V2
dac | J1 | MOD-V2 | MOD-V2
adc | C7 | 10u | PANASONIC_B
adc | C9 | 10u | PANASONIC_B
adc | C14 | 10u | PANASONIC_B
adc | C15 | 10u | PANASONIC_B
adc | C21 | 10u | PANASONIC_B
dac | C4 | 10u | PANASONIC_B
dac | C5 | 10u | PANASONIC_B
dac | C8 | 10u | PANASONIC_B
dac | C12 | 10u | PANASONIC_B
dac | C14 | 10u | PANASONIC_B
dac | C16 | 10u | PANASONIC_B
dac | C21 | 10u | PANASONIC_B
dac | C22 | 10u | PANASONIC_B
dac | C46 | 10u | PANASONIC_B
dac | C47 | 10u | PANASONIC_B
dac | C54 | 10u | PANASONIC_B
dac | C55 | 10u | PANASONIC_B
dac | C62 | 10u | PANASONIC_B
dac | C63 | 10u | PANASONIC_B
dac | C70 | 10u | PANASONIC_B
adc | C10 | 2200u | PANASONIC_H13
dac | C6 | 2200u | PANASONIC_H13
dac | C19 | 2200u | PANASONIC_H13
dac | U1 | AK4490 | P-QFP48-7X7MM
adc | U1 | AK5572 | QFN48_EP_AKM
dac | R43 | 0 | R0603
dac | R48 | 0 | R0603
dac | R53 | 0 | R0603
dac | R58 | 0 | R0603
adc | R3 | 1 | R0603
dac | R3 | 1 | R0603
dac | R60 | 1 | R0603
dac | R42 | 2.49 | R0603
dac | R47 | 2.49 | R0603
dac | R52 | 2.49 | R0603
dac | R57 | 2.49 | R0603
adc | R14 | 10 | R0603
adc | R15 | 10 | R0603
adc | R16 | 10 | R0603
adc | R17 | 10 | R0603
dac | R4 | 10 | R0603
dac | R15 | 10 | R0603
dac | R20 | 10 | R0603
dac | R25 | 10 | R0603
dac | R41 | 10.5 | R0603
dac | R46 | 10.5 | R0603
dac | R51 | 10.5 | R0603
dac | R56 | 10.5 | R0603
adc | R1 | 22 | R0603
adc | R26 | 22 | R0603
dac | R1 | 22 | R0603
dac | R2 | 22 | R0603
dac | R10 | 22 | R0603
dac | R5 | 24.9 | R0603
dac | R16 | 24.9 | R0603
dac | R21 | 24.9 | R0603
dac | R26 | 24.9 | R0603
dac | R40 | 45.3 | R0603
dac | R45 | 45.3 | R0603
dac | R50 | 45.3 | R0603
dac | R55 | 45.3 | R0603
adc | R23 | 50 | R0603
adc | R24 | 50 | R0603
adc | R25 | 50 | R0603
adc | R27 | 50 | R0603
adc | R28 | 50 | R0603
adc | R29 | 50 | R0603
dac | R12 | 50 | R0603
dac | R13 | 50 | R0603
dac | R14 | 50 | R0603
dac | R36 | 50 | R0603
dac | R37 | 50 | R0603
dac | R38 | 50 | R0603
dac | R39 | 50 | R0603
dac | R44 | 90.9 | R0603
dac | R49 | 90.9 | R0603
dac | R54 | 90.9 | R0603
dac | R59 | 90.9 | R0603
adc | R21 | 100 | R0603
dac | R9 | 100 | R0603
dac | R30 | 100 | R0603
dac | R31 | 100 | R0603
dac | R32 | 100 | R0603
dac | R33 | 100 | R0603
dac | R6 | 249 | R0603
dac | R7 | 249 | R0603
dac | R17 | 249 | R0603
dac | R18 | 249 | R0603
dac | R22 | 249 | R0603
dac | R23 | 249 | R0603
dac | R27 | 249 | R0603
dac | R28 | 249 | R0603
dac | R34 | 825 | R0603
dac | R35 | 825 | R0603
adc | R11 | 887 | R0603
adc | R18 | 887 | R0603
adc | R19 | 887 | R0603
adc | R20 | 887 | R0603
adc | R2 | 100k | R0603
adc | R4 | 100k | R0603
adc | R5 | 100k | R0603
adc | R6 | 100k | R0603
dac | R8 | 100k | R0603
dac | R19 | 100k | R0603
dac | R24 | 100k | R0603
dac | R29 | 100k | R0603
adc | R7 | 1k | R0603
adc | R8 | 1k | R0603
adc | R9 | 1k | R0603
adc | R10 | 1k | R0603
adc | R12 | 1k | R0603
adc | R13 | 1k | R0603
adc | R22 | 4.12k | R0603
dac | R11 | 4.12k | R0603
adc | L2 | BEAD | R1206
dac | L1 | BEAD | R1206
dac | L2 | BEAD | R1206
adc | U5 | ADA4004-4 | SO14
adc | U8 | ADM7154 | SO8-EP
dac | U8 | ADM7154 | SO8-EP
dac | D1 | MMSZ5235B | SOD123
dac | D2 | MMSZ5235B | SOD123
dac | U5 | ADM7160 | SOT23-DBV
adc | U3 | ADP7142 | SOT23-DBV
dac | U3 | ADP7142 | SOT23-DBV
adc | U4 | ADP7182 | SOT23-DBV
dac | U4 | ADP7182 | SOT23-DBV
dac | U21 | 74164FT | TSSOP14
dac | U13 | DG9424E | TSSOP16
dac | U14 | DG9424E | TSSOP16
dac | U22 | 74LVTH574 | TSSOP20

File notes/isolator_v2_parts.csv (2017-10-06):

Component Type | Value | Package | adapter | isolator | isolator_bypass | isolator_iso | isolator_jung | isolator_lm317 | pwrload | Required Qty | Supplier | Part num. | Order Qty
Female 0.1" header | 27 pin |  |  | 8 |  |  |  |  |  | 16
Male 0.1" header | 16x2 pin |  |  | 1 |  |  |  |  |  | 2
Male 0.1" header | 24x2 pin |  |  | 2 |  |  |  |  |  | 4
Male 0.1" header | 27 pin |  | 2 |  |  |  |  |  | 2 | 12
Male 0.1" header | 3 pin |  | 2 |  |  |  |  |  |  | 4
Male 0.1" header | 4x2 pin |  | 1 |  |  |  |  |  | 8 | 34
Male 0.1" header | 6 pin |  | 2 |  |  |  |  |  |  | 4
Male 0.1" header | 6x2 pin |  | 2 | 1 |  |  |  |  |  | 6
Male 0.1" header | 8 pin |  | 1 |  |  |  |  |  |  | 2
Male 0.1" header | 8x2 pin |  | 2 |  |  |  |  |  |  | 4 |  |  |  | Qty of boards
Cap (electrolytic) | 100u | Code F |  | 4 |  |  | 14 |  |  | 22 |  |  |  | adapter | 2
Cap (tantalum) | 330u | 7343 | 1 |  |  |  |  |  |  | 2 |  |  |  | isolator | 2
Capacitor | 0.1u | 603 | 3 | 10 |  | 30 |  |  |  | 56 |  |  |  | isolator_bypass | 1
Capacitor | 10n | 402 | 4 |  |  |  |  |  |  | 8 |  |  |  | isolator_iso | 1
Capacitor | 10n | 603 | 2 | 2 |  |  |  |  |  | 8 |  |  |  | isolator_jung | 1
Capacitor | 10u | 1206 | 7 | 4 |  |  |  | 4 |  | 26 |  |  |  | isolator_lm317 | 1
Capacitor | 1u | 603 | 1 |  |  |  |  |  |  | 2 |  |  |  | pwrload | 4
Capacitor | 1u | 805 | 3 |  |  |  |  |  |  | 6
Capacitor | 1u | 1206 |  | 7 |  |  | 5 |  |  | 19
Connector | SMA |  | 2 |  |  |  |  |  |  | 4
Connector | Samtec ????? |  | 1 |  |  |  |  |  |  | 2
Diode | 1N4148 | SOD-123 |  |  |  |  | 8 |  |  | 8
Diode | MMSZ5226B | SOD-123 |  |  |  |  | 2 |  |  | 2
Diode | MMSZ5235B | SOD-123 |  |  |  |  | 2 |  |  | 2
Ferrite bead |  | 1206 | 1 | 4 |  |  |  |  |  | 10
LED |  | 1206 |  |  |  |  | 4 |  |  | 4
Logic chip | 7404 | TSSOP14 |  |  |  | 1 |  |  |  | 1
Logic chip | 74164 | TSSOP14 | 1 | 2 |  | 1 |  |  |  | 7
Logic chip | 74165 | TSSOP16 | 1 | 2 |  |  |  |  |  | 6
Logic chip | 74574 | TSSOP20 | 1 | 2 |  | 1 |  |  |  | 7
Regulator | LM317 | D2PAK |  | 3 |  |  |  |  |  | 6
Regulator | LM337 | D2PAK |  | 1 |  |  |  |  |  | 2
Regulator | NCP1117-3.3 | DPAK | 1 | 2 |  |  |  |  |  | 6
Resistor | 0 | 603 | 6 |  |  |  |  |  |  | 12
Resistor | 0 | 1206 |  |  | 36 |  |  | 4 |  | 40
Resistor | 1 | 603 | 1 |  |  |  |  |  |  | 2
Resistor | 1 | 1206 |  | 2 |  |  |  |  |  | 4
Resistor | 1.42k | 603 |  |  |  |  |  | 2 |  | 2
Resistor | 1.5k | 1206 |  |  |  |  | 1 |  |  | 1
Resistor | 10 | 1206 |  |  |  |  | 4 |  |  | 4
Resistor | 100 | 603 | 1 | 1 |  |  |  |  |  | 4
Resistor | 10k | 603 | 9 | 15 |  |  |  |  |  | 48
Resistor | 10k | 1206 |  |  |  |  | 4 |  |  | 4
Resistor | 1k | 603 |  | 3 |  |  |  |  |  | 6
Resistor | 1k | 1206 |  |  |  |  | 2 |  |  | 2
Resistor | 2.21k | 603 |  |  |  |  |  | 2 |  | 2
Resistor | 200 | 603 |  |  |  |  |  | 2 |  | 2
Resistor | 22 | 603 | 1 | 1 |  |  |  |  |  | 4
Resistor | 2k | 1206 |  |  |  |  | 1 |  |  | 1
Resistor | 3.01k | 1206 |  |  |  |  | 1 |  |  | 1
Resistor | 4.12k | 603 | 1 |  |  |  |  |  |  | 2
Resistor | 475 | 1206 |  |  |  |  |  | 1 |  | 1
Resistor | 499 | 603 |  |  |  |  | 4 |  |  | 4
Resistor | 50 | 603 | 3 |  |  |  |  |  |  | 6
Resistor | 604 | 1206 |  |  |  |  | 1 |  |  | 1
Resistor | 649 | 1206 |  |  |  |  | 1 |  |  | 1
Resistor | 68.1 | 1206 |  |  |  |  | 4 |  |  | 4
Resistor | 750 | 1206 |  |  |  |  | 1 |  |  | 1
Resistor | 825 | 603 |  |  |  |  | 2 |  |  | 2
Resistor | 866 | 1206 |  |  |  |  |  | 1 |  | 1
Resistor 1 W | 27 | Axial |  |  |  |  |  |  | 4 | 16
Resistor 1 W | 39 | Axial |  |  |  |  |  |  | 4 | 16
Resistor 1 W | 56 | Axial |  |  |  |  |  |  | 8 | 32
Resistor 5 W | 100 | Axial |  |  |  |  |  |  | 8 | 32
Resistor 5 W | 180 | Axial |  |  |  |  |  |  | 8 | 32
Special chip | AD8655 | SO-8 |  |  |  |  | 2 |  |  | 2
Special chip | AD9515 | LFCSP32 | 1 |  |  |  |  |  |  | 2
Special chip | ADM7154 | SO8-EP | 1 |  |  |  |  |  |  | 2
Special chip | ADR4525 | SO-8 |  |  |  |  | 2 |  |  | 2
Special chip | ADUM3401 | SO-16W |  |  |  | 2 |  |  |  | 2
Special chip | ADUM3402 | SO-16W |  |  |  | 13 |  |  |  | 13
Special chip | DS90LV012 | DBV |  | 1 |  |  |  |  |  | 2
Special chip | LME49710 | SO-8 |  |  |  |  | 2 |  |  | 2
Special chip | LT1236-10 | SO-8 |  |  |  |  | 1 |  |  | 1
Special chip | MAX6220 | SO-8 |  |  |  |  | 1 |  |  | 1
Transistor | B44H11 | D2PAK |  |  |  |  | 3 |  |  | 3
Transistor | B45H11 | D2PAK |  |  |  |  | 1 |  |  | 1
Transistor | BC807 | SOT23 |  |  |  |  | 3 |  |  | 3
Transistor | BC817 | SOT23 |  |  |  |  | 1 |  |  | 1

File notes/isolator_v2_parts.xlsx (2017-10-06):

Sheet: isolator_v2_parts
Board | Component Type | Value | Package | Supplier | Part Number | Quantity
isolator_jung | Cap (electrolytic) | 100u | Code F |  |  | 14
isolator_jung | Capacitor | 1u | 1206 |  |  | 5
isolator_jung | Diode | 1N4148 | SOD-123 |  |  | 8
isolator_jung | Diode | MMSZ5226B | SOD-123 |  |  | 2
isolator_jung | Diode | MMSZ5235B | SOD-123 |  |  | 2
isolator_jung | LED |  | 1206 |  |  | 4
isolator_jung | Resistor | 10 | 1206 |  |  | 4
isolator_jung | Resistor | 68.1 | 1206 |  |  | 4
isolator_jung | Resistor | 499 | 0603 |  |  | 4
isolator_jung | Resistor | 604 | 1206 |  |  | 1
isolator_jung | Resistor | 649 | 1206 |  |  | 1
isolator_jung | Resistor | 750 | 1206 |  |  | 1
isolator_jung | Resistor | 825 | 0603 |  |  | 2
isolator_jung | Resistor | 1.5k | 1206 |  |  | 1
isolator_jung | Resistor | 10k | 1206 |  |  | 4
isolator_jung | Resistor | 1k | 1206 |  |  | 2
isolator_jung | Resistor | 2k | 1206 |  |  | 1
isolator_jung | Resistor | 3.01k | 1206 |  |  | 1
isolator_jung | Special chip | AD8655 | SO-8 |  |  | 2
isolator_jung | Special chip | ADR4525 | SO-8 |  |  | 2
isolator_jung | Special chip | LME49710 | SO-8 |  |  | 2
isolator_jung | Special chip | LT1236-10 | SO-8 |  |  | 1
isolator_jung | Special chip | MAX6220 | SO-8 |  |  | 1
isolator_jung | Transistor | B44H11 | D2PAK |  |  | 3
isolator_jung | Transistor | B45H11 | D2PAK |  |  | 1
isolator_jung | Transistor | BC807 | SOT23 |  |  | 3
isolator_jung | Transistor | BC817 | SOT23 |  |  | 1

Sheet: isolator_v2_partlist
Part | Value | Device | Package | Library | Sheet
R401 | 0 | R-US_R1206 | R1206 | rcl | 1
R402 | 0 | R-US_R1206 | R1206 | rcl | 1
R403 | 0 | R-US_R1206 | R1206 | rcl | 1
R404 | 0 | R-US_R1206 | R1206 | rcl | 1
R405 | 0 | R-US_R1206 | R1206 | rcl | 1
R406 | 0 | R-US_R1206 | R1206 | rcl | 1
R407 | 0 | R-US_R1206 | R1206 | rcl | 1
R408 | 0 | R-US_R1206 | R1206 | rcl | 1
R409 | 0 | R-US_R1206 | R1206 | rcl | 1
R410 | 0 | R-US_R1206 | R1206 | rcl | 1
R411 | 0 | R-US_R1206 | R1206 | rcl | 1
R412 | 0 | R-US_R1206 | R1206 | rcl | 1
R413 | 0 | R-US_R1206 | R1206 | rcl | 2
R414 | 0 | R-US_R1206 | R1206 | rcl | 2
R415 | 0 | R-US_R1206 | R1206 | rcl | 2
R416 | 0 | R-US_R1206 | R1206 | rcl | 2
R417 | 0 | R-US_R1206 | R1206 | rcl | 2
R418 | 0 | R-US_R1206 | R1206 | rcl | 2
R419 | 0 | R-US_R1206 | R1206 | rcl | 2
R420 | 0 | R-US_R1206 | R1206 | rcl | 2
R421 | 0 | R-US_R1206 | R1206 | rcl | 2
R422 | 0 | R-US_R1206 | R1206 | rcl | 2
R423 | 0 | R-US_R1206 | R1206 | rcl | 2
R424 | 0 | R-US_R1206 | R1206 | rcl | 2
R425 | 0 | R-US_R1206 | R1206 | rcl | 2
R426 | 0 | R-US_R1206 | R1206 | rcl | 2
R427 | 0 | R-US_R1206 | R1206 | rcl | 2
R428 | 0 | R-US_R1206 | R1206 | rcl | 2
R429 | 0 | R-US_R1206 | R1206 | rcl | 2
R430 | 0 | R-US_R1206 | R1206 | rcl | 2
R431 | 0 | R-US_R1206 | R1206 | rcl | 2
R432 | 0 | R-US_R1206 | R1206 | rcl | 2
R433 | 0 | R-US_R1206 | R1206 | rcl | 2
R434 | 0 | R-US_R1206 | R1206 | rcl | 2
R435 | 0 | R-US_R1206 | R1206 | rcl | 2
R436 | 0 | R-US_R1206 | R1206 | rcl | 2
R501 | 0 | R-US_R1206 | R1206 | rcl | 3
R503 | 0 | R-US_R1206 | R1206 | rcl | 3
R507 | 0 | R-US_R1206 | R1206 | rcl | 4
R510 | 0 | R-US_R1206 | R1206 | rcl | 4
R181 | 1 | R-US_R1206 | R1206 | rcl | 6
R281 | 1 | R-US_R1206 | R1206 | rcl | 6
R341 | 10 | R-US_R1206 | R1206 | rcl | 3
R342 | 10 | R-US_R1206 | R1206 | rcl | 3
R343 | 10 | R-US_R1206 | R1206 | rcl | 4
R344 | 10 | R-US_R1206 | R1206 | rcl | 4
R124 | 22 | R-US_R0603 | R0603 | rcl | 1
R331 | 68.1 | R-US_R1206 | R1206 | rcl | 3
R332 | 68.1 | R-US_R1206 | R1206 | rcl | 3
R333 | 68.1 | R-US_R1206 | R1206 | rcl | 4
R334 | 68.1 | R-US_R1206 | R1206 | rcl | 4
R123 | 100 | R-US_R0603 | R0603 | rcl | 1
R505 | 475 | R-US_R1206 | R1206 | rcl | 4
R371 | 499 | R-US_R0603 | R0603 | rcl | 3
R372 | 499 | R-US_R0603 | R0603 | rcl | 3
R373 | 499 | R-US_R0603 | R0603 | rcl | 4
R374 | 499 | R-US_R0603 | R0603 | rcl | 4
R361 | 604 | R-US_R1206 | R1206 | rcl | 3
R354 | 649 | R-US_R1206 | R1206 | rcl | 4
R352 | 750 | R-US_R1206 | R1206 | rcl | 3
R311 | 825 | R-US_R0603 | R0603 | rcl | 3
R312 | 825 | R-US_R0603 | R0603 | rcl | 3
R508 | 866 | R-US_R1206 | R1206 | rcl | 4
C111 | 0.1u | C-USC0603 | C0603 | rcl | 6
C112 | 0.1u | C-USC0603 | C0603 | rcl | 6
C113 | 0.1u | C-USC0603 | C0603 | rcl | 6
C114 | 0.1u | C-USC0603 | C0603 | rcl | 6
C115 | 0.1u | C-USC0603 | C0603 | rcl | 6
C116 | 0.1u | C-USC0603 | C0603 | rcl | 6
C121 | 0.1u | C-USC0603 | C0603 | rcl | 1
C201 | 0.1u | C-USC0603 | C0603 | rcl | 1
C202 | 0.1u | C-USC0603 | C0603 | rcl | 1
C203 | 0.1u | C-USC0603 | C0603 | rcl | 1
C204 | 0.1u | C-USC0603 | C0603 | rcl | 1
C205 | 0.1u | C-USC0603 | C0603 | rcl | 1
C206 | 0.1u | C-USC0603 | C0603 | rcl | 1
C211 | 0.1u | C-USC0603 | C0603 | rcl | 1
C212 | 0.1u | C-USC0603 | C0603 | rcl | 1
C213 | 0.1u | C-USC0603 | C0603 | rcl | 1
C214 | 0.1u | C-USC0603 | C0603 | rcl | 1
C215 | 0.1u | C-USC0603 | C0603 | rcl | 1
C216 | 0.1u | C-USC0603 | C0603 | rcl | 1
C221 | 0.1u | C-USC0603 | C0603 | rcl | 1
C222 | 0.1u | C-USC0603 | C0603 | rcl | 1
C223 | 0.1u | C-USC0603 | C0603 | rcl | 1
C224 | 0.1u | C-USC0603 | C0603 | rcl | 1
C225 | 0.1u | C-USC0603 | C0603 | rcl | 1
C226 | 0.1u | C-USC0603 | C0603 | rcl | 1
C231 | 0.1u | C-USC0603 | C0603 | rcl | 1
C232 | 0.1u | C-USC0603 | C0603 | rcl | 1
C233 | 0.1u | C-USC0603 | C0603 | rcl | 1
C234 | 0.1u | C-USC0603 | C0603 | rcl | 1
C235 | 0.1u | C-USC0603 | C0603 | rcl | 1
C236 | 0.1u | C-USC0603 | C0603 | rcl | 1
C240 | 0.1u | C-USC0603 | C0603 | rcl | 2
C261 | 0.1u | C-USC0603 | C0603 | rcl | 1
C262 | 0.1u | C-USC0603 | C0603 | rcl | 1
C263 | 0.1u | C-USC0603 | C0603 | rcl | 1
C264 | 0.1u | C-USC0603 | C0603 | rcl | 1
C265 | 0.1u | C-USC0603 | C0603 | rcl | 1
C266 | 0.1u | C-USC0603 | C0603 | rcl | 1
C271 | 0.1u | C-USC0603 | C0603 | rcl | 1
C272 | 0.1u | C-USC0603 | C0603 | rcl | 1
R506 | 1.42k | R-US_R0603 | R0603 | rcl | 4
R509 | 1.42k | R-US_R0603 | R0603 | rcl | 4
R362 | 1.50k | R-US_R1206 | R1206 | rcl | 3
C301 | 100u | CPOL-USF | PANASONIC_F | rcl | 3
C302 | 100u | CPOL-USF | PANASONIC_F | rcl | 3
C311 | 100u | CPOL-USF | PANASONIC_F | rcl | 3
C312 | 100u | CPOL-USF | PANASONIC_F | rcl | 3
C313 | 100u | CPOL-USF | PANASONIC_F | rcl | 4
C314 | 100u | CPOL-USF | PANASONIC_F | rcl | 4
C321 | 100u | CPOL-USF | PANASONIC_F | rcl | 3
C322 | 100u | CPOL-USF | PANASONIC_F | rcl | 3
C323 | 100u | CPOL-USF | PANASONIC_F | rcl | 4
C324 | 100u | CPOL-USF | PANASONIC_F | rcl | 4
C331 | 100u | CPOL-USF | PANASONIC_F | rcl | 3
C332 | 100u | CPOL-USF | PANASONIC_F | rcl | 3
C333 | 100u | CPOL-USF | PANASONIC_F | rcl | 4
C334 | 100u | CPOL-USF | PANASONIC_F | rcl | 4
C341 | 100u | CPOL-USF | PANASONIC_F | rcl | 3
C342 | 100u | CPOL-USF | PANASONIC_F | rcl | 3
C343 | 100u | CPOL-USF | PANASONIC_F | rcl | 4
C344 | 100u | CPOL-USF | PANASONIC_F | rcl | 4
R121 | 10k | R-US_R0603 | R0603 | rcl | 1
R122 | 10k | R-US_R0603 | R0603 | rcl | 1
R131 | 10k | R-US_R0603 | R0603 | rcl | 6
R132 | 10k | R-US_R0603 | R0603 | rcl | 6
R133 | 10k | R-US_R0603 | R0603 | rcl | 6
R134 | 10k | R-US_R0603 | R0603 | rcl | 6
R135 | 10k | R-US_R0603 | R0603 | rcl | 6
R136 | 10k | R-US_R0603 | R0603 | rcl | 6
R137 | 10k | R-US_R0603 | R0603 | rcl | 6
R138 | 10k | R-US_R0603 | R0603 | rcl | 6
R139 | 10k | R-US_R0603 | R0603 | rcl | 6
R140 | 10k | R-US_R0603 | R0603 | rcl | 6
R141 | 10k | R-US_R0603 | R0603 | rcl | 6
R142 | 10k | R-US_R0603 | R0603 | rcl | 6
R143 | 10k | R-US_R0603 | R0603 | rcl | 6
R321 | 10k | R-US_R1206 | R1206 | rcl | 3
R322 | 10k | R-US_R1206 | R1206 | rcl | 3
R323 | 10k | R-US_R1206 | R1206 | rcl | 4
R324 | 10k | R-US_R1206 | R1206 | rcl | 4
C122 | 10n | C-USC0603 | C0603 | rcl | 1
C123 | 10n | C-USC0603 | C0603 | rcl | 1
C181 | 10u | C-USC1206 | C1206 | rcl | 6
C184 | 10u | C-USC1206 | C1206 | rcl | 6
C281 | 10u | C-USC1206 | C1206 | rcl | 6
C283 | 10u | C-USC1206 | C1206 | rcl | 6
C501 | 10u | C-USC1206 | C1206 | rcl | 3
C502 | 10u | C-USC1206 | C1206 | rcl | 3
C503 | 10u | C-USC1206 | C1206 | rcl | 4
C504 | 10u | C-USC1206 | C1206 | rcl | 4
R301 | 1k | R-US_R0603 | R0603 | rcl | 3
R302 | 1k | R-US_R0603 | R0603 | rcl | 3
R382 | 1k | R-US_R0603 | R0603 | rcl | 3
R353 | 1k | R-US_R1206 | R1206 | rcl | 4
R363 | 1k | R-US_R1206 | R1206 | rcl | 4
D311 | 1N4148_SMD | 1N4148_SMD | SOD123 | smps | 3
D312 | 1N4148_SMD | 1N4148_SMD | SOD123 | smps | 3
D313 | 1N4148_SMD | 1N4148_SMD | SOD123 | smps | 4
D314 | 1N4148_SMD | 1N4148_SMD | SOD123 | smps | 4
D321 | 1N4148_SMD | 1N4148_SMD | SOD123 | smps | 3
D322 | 1N4148_SMD | 1N4148_SMD | SOD123 | smps | 3
D323 | 1N4148_SMD | 1N4148_SMD | SOD123 | smps | 4
D324 | 1N4148_SMD | 1N4148_SMD | SOD123 | smps | 4
C182 | 1u | C-USC1206 | C1206 | rcl | 6
C183 | 1u | C-USC1206 | C1206 | rcl | 6
C282 | 1u | C-USC1206 | C1206 | rcl | 6
C351 | 1u | C-USC1206 | C1206 | rcl | 3
C352 | 1u | C-USC1206 | C1206 | rcl | 3
C353 | 1u | C-USC1206 | C1206 | rcl | 4
C354 | 1u | C-USC1206 | C1206 | rcl | 4
C361 | 1u | C-USC1206 | C1206 | rcl | 3
C362 | 1u | C-USC1206 | C1206 | rcl | 3
C363 | 1u | C-USC1206 | C1206 | rcl | 4
C364 | 1u | C-USC1206 | C1206 | rcl | 4
C371 | 1u | C-USC1206 | C1206 | rcl | 3
R364 | 2.0k | R-US_R1206 | R1206 | rcl | 4
R502 | 2.21k | R-US_R0603 | R0603 | rcl | 3
R504 | 2.21k | R-US_R0603 | R0603 | rcl | 3
R351 | 3.01k | R-US_R1206 | R1206 | rcl | 3
U240 | 7404MT | 7404MT | TSSOP14 | cdp | 2
U112 | 74164FT | 74164FT | TSSOP14 | cdp | 6
U115 | 74164FT | 74164FT | TSSOP14 | cdp | 6
U271 | 74164FT | 74164FT | TSSOP14 | cdp | 1
U111 | 74165FT | 74165FT | TSSOP16 | cdp | 6
U114 | 74165FT | 74165FT | TSSOP16 | cdp | 6
U113 | 74LVTH574 | 74LVTH574 | TSSOP20 | cdp | 6
U116 | 74LVTH574 | 74LVTH574 | TSSOP20 | cdp | 6
U272 | 74LVTH574 | 74LVTH574 | TSSOP20 | cdp | 1
U181 | 78M33 | 78XXS | DPACK | cdp | 6
U281 | 78M33 | 78XXS | DPACK | cdp | 6
U303 | AD8655 | AD811_SO8 | SO8 | analog-devices | 4
U304 | AD8655 | AD811_SO8 | SO8 | analog-devices | 4
U313 | ADR4525 | MAX6220 | SO8 | cdp | 4
U314 | ADR4525 | MAX6220 | SO8 | cdp | 4
U261 | ADUM3401 | ADUM3401 | SO-16W | cdp | 1
U263 | ADUM3401 | ADUM3401 | SO-16W | cdp | 1
U201 | ADUM3402 | ADUM3402 | SO-16W | cdp | 2
U202 | ADUM3402 | ADUM3402 | SO-16W | cdp | 2
U203 | ADUM3402 | ADUM3402 | SO-16W | cdp | 2
U211 | ADUM3402 | ADUM3402 | SO-16W | cdp | 2
U212 | ADUM3402 | ADUM3402 | SO-16W | cdp | 2
U213 | ADUM3402 | ADUM3402 | SO-16W | cdp | 2
U221 | ADUM3402 | ADUM3402 | SO-16W | cdp | 2
U222 | ADUM3402 | ADUM3402 | SO-16W | cdp | 2
U223 | ADUM3402 | ADUM3402 | SO-16W | cdp | 2
U231 | ADUM3402 | ADUM3402 | SO-16W | cdp | 2
U232 | ADUM3402 | ADUM3402 | SO-16W | cdp | 2
U233 | ADUM3402 | ADUM3402 | SO-16W | cdp | 2
U262 | ADUM3402 | ADUM3402 | SO-16W | cdp | 1
Q311 | BC807-25SMD | BC807-25SMD | SOT23-BEC | transistor-pnp | 3
Q313 | BC807-25SMD | BC807-25SMD | SOT23-BEC | transistor-pnp | 4
Q314 | BC807-25SMD | BC807-25SMD | SOT23-BEC | transistor-pnp | 4
Q312 | BC817-25SMD | BC817-25SMD | SOT23-BEC | transistor-npn | 3
L101 | BEAD | R-US_R1206 | R1206 | rcl | 3
L181 | BEAD | R-US_R1206 | R1206 | rcl | 6
L281 | BEAD | R-US_R1206 | R1206 | rcl | 6
L401 | BEAD | R-US_R1206 | R1206 | rcl | 3
J1 | CARRIER-V2 | CARRIER-V2 | MA24-2 | cdp | 1
J3 | CLKBRD-V2 | CLKBRD-V2 | MA16-2 | cdp | 6
Q301 | D44H11 | D44H11 | D2PACK | cdp | 3
Q303 | D44H11 | D44H11 | D2PACK | cdp | 4
Q304 | D44H11 | D44H11 | D2PACK | cdp | 4
Q302 | D45H11 | D45H11 | D2PACK | cdp | 3
U121 | DS90LV012 | DS90LV012 | SOT23-DBV | cdp | 1
D301 | Green | LEDCHIPLED_1206 | CHIPLED_1206 | led | 3
D302 | Green | LEDCHIPLED_1206 | CHIPLED_1206 | led | 3
D303 | Green | LEDCHIPLED_1206 | CHIPLED_1206 | led | 4
D304 | Green | LEDCHIPLED_1206 | CHIPLED_1206 | led | 4
U321 | LM317BD2T | LM317BD2T | D2PACK | v-reg | 3
U503 | LM317BD2T | LM317BD2T | D2PACK | v-reg | 4
U504 | LM317BD2T | LM317BD2T | D2PACK | v-reg | 4
U322 | LM337 | LM337LD2 | D2PACK | cdp | 3
U301 | LME49710 | AD811_SO8 | SO8 | analog-devices | 3
U302 | LME49710 | AD811_SO8 | SO8 | analog-devices | 3
U312 | LT1236S-10 | LT1236S-10 | SOIC8 | linear-technology | 3
J4 | MA24-2 | MA24-2 | MA24-2-HEADERONLY | cdp | 3
U311 | MAX6220 | MAX6220 | SO8 | cdp | 3
D333 | MMSZ5226B | ZD | SOD123 | cdp | 4
D334 | MMSZ5226B | ZD | SOD123 | cdp | 4
D331 | MMSZ5235B | ZD | SOD123 | cdp | 3
D332 | MMSZ5235B | ZD | SOD123 | cdp | 3
J10 | MOD-V2 | MOD-V2 | MOD-V2 | cdp | 5
J11 | MOD-V2 | MOD-V2 | MOD-V2 | cdp | 5
J12 | MOD-V2 | MOD-V2 | MOD-V2 | cdp | 5
J13 | MOD-V2 | MOD-V2 | MOD-V2 | cdp | 5
J2 | PSU-V2 | PSU-V2 | MA06-2 | cdp | 3

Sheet: module_adapter_partslist
Part | Value | Device | Package | Library | Sheet
R2 | 0 | R-US_R0603 | R0603 | rcl | 1
R3 | 0 | R-US_R0603 | R0603 | rcl | 1
R4 | 0 | R-US_R0603 | R0603 | rcl | 1
R5 | 0 | R-US_R0603 | R0603 | rcl | 1
R6 | 0 | R-US_R0603 | R0603 | rcl | 1
R7 | 0 | R-US_R0603 | R0603 | rcl | 1
R1 | 1 | R-US_R0603 | R0603 | rcl | 1
R18 | 22 | R-US_R0603 | R0603 | rcl | 1
R20 | 50 | R-US_R0603 | R0603 | rcl | 1
R21 | 50 | R-US_R0603 | R0603 | rcl | 1
R22 | 50 | R-US_R0603 | R0603 | rcl | 1
R17 | 100 | R-US_R0603 | R0603 | rcl | 1
C111 | 0.1u | C-USC0603 | C0603 | rcl | 1
C271 | 0.1u | C-USC0603 | C0603 | rcl | 1
C272 | 0.1u | C-USC0603 | C0603 | rcl | 1
R8 | 10k | R-US_R0603 | R0603 | rcl | 1
R9 | 10k | R-US_R0603 | R0603 | rcl | 1
R10 | 10k | R-US_R0603 | R0603 | rcl | 1
R11 | 10k | R-US_R0603 | R0603 | rcl | 1
R12 | 10k | R-US_R0603 | R0603 | rcl | 1
R13 | 10k | R-US_R0603 | R0603 | rcl | 1
R14 | 10k | R-US_R0603 | R0603 | rcl | 1
R15 | 10k | R-US_R0603 | R0603 | rcl | 1
R16 | 10k | R-US_R0603 | R0603 | rcl | 1
C13 | 10n | C-USC0402 | C0402 | rcl | 1
C14 | 10n | C-USC0402 | C0402 | rcl | 1
C15 | 10n | C-USC0402 | C0402 | rcl | 1
C16 | 10n | C-USC0402 | C0402 | rcl | 1
C3 | 10n | C-USC0603 | C0603 | rcl | 1
C4 | 10n | C-USC0603 | C0603 | rcl | 1
C1 | 10u | C-USC1206 | C1206 | rcl | 1
C2 | 10u | C-USC1206 | C1206 | rcl | 1
C6 | 10u | C-USC1206 | C1206 | rcl | 1
C7 | 10u | C-USC1206 | C1206 | rcl | 1
C10 | 10u | C-USC1206 | C1206 | rcl | 1
C11 | 10u | C-USC1206 | C1206 | rcl | 1
C17 | 10u | C-USC1206 | C1206 | rcl | 1
C5 | 1u | C-USC0603 | C0603 | rcl | 1
C8 | 1u | C-USC0805 | C0805 | rcl | 1
C9 | 1u | C-USC0805 | C0805 | rcl | 1
C12 | 1u | C-USC0805 | C0805 | rcl | 1
C22 | 330u | CPOL-USCT7343 | CT7343 | rcl | 1
R19 | 4.12k | R-US_R0603 | R0603 | rcl | 1
U271 | 74164FT | 74164FT | TSSOP14 | cdp | 1
U111 | 74165FT | 74165FT | TSSOP16 | cdp | 1
U272 | 74LVTH574 | 74LVTH574 | TSSOP20 | cdp | 1
U1 | AD9515 | AD9515 | LFCSP32 | cdp | 1
U8 | ADM7154 | ADM7154 | SO8-EP | cdp | 1
L1 | BEAD | R-US_R1206 | R1206 | rcl | 1
L2 | BEAD | R-US_R1206 | R1206 | rcl | 1
J1 | MOD-V2 | MOD-V2 | MOD-V2 | cdp | 1
U2 | NCP1117DT33 | 78XXS | DPACK | cdp | 1
X1 | SMA-SMD | SMA-SMD | SMA-SMD | cdp | 1
X8 | SMA-SMD | SMA-SMD | SMA-SMD | cdp | 1
J2 | SMD-30 | SMD-30 | FCI-SMD-30 | cdp | 1
SV3 |  | MA03-1 | MA03-1 | con-lstb | 1
SV4 |  | MA03-1 | MA03-1 | con-lstb | 1
SV8 |  | MA04-2 | MA04-2 | con-lstb | 1
SV1 |  | MA06-1 | MA06-1 | con-lstb | 1
SV2 |  | MA06-1 | MA06-1 | con-lstb | 1
SV9 |  | MA06-2 | MA06-2 | con-lstb | 1
SV10 |  | MA06-2 | MA06-2 | con-lstb | 1
SV7 |  | MA08-1 | MA08-1 | con-lstb | 1
SV5 |  | MA08-2 | MA08-2 | con-lstb | 1
SV6 |  | MA08-2 | MA08-2 | con-lstb | 1

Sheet: pwrload_partslist
Part | Value | Device | Package | Library | Sheet
J1 | MOD-V2 | MOD-V2 | MOD-V2 | cdp | 1
R1 | 56 | R-US_0411/12 | 0411/12 | rcl | 1
R2 | 180 | R-US_0817/22 | P0817/22 | rcl | 1
R3 | 180 | R-US_0817/22 | P0817/22 | rcl | 1
R4 | 180 | R-US_0817/22 | P0817/22 | rcl | 1
R5 | 180 | R-US_0817/22 | P0817/22 | rcl | 1
R6 | 180 | R-US_0817/22 | P0817/22 | rcl | 1
R7 | 180 | R-US_0817/22 | P0817/22 | rcl | 1
R8 | 180 | R-US_0817/22 | P0817/22 | rcl | 1
R9 | 180 | R-US_0817/22 | P0817/22 | rcl | 1
R10 | 100 | R-US_0817/22 | P0817/22 | rcl | 1
R11 | 100 | R-US_0817/22 | P0817/22 | rcl | 1
R12 | 100 | R-US_0817/22 | P0817/22 | rcl | 1
R13 | 100 | R-US_0817/22 | P0817/22 | rcl | 1
R14 | 100 | R-US_0817/22 | P0817/22 | rcl | 1
R15 | 100 | R-US_0817/22 | P0817/22 | rcl | 1
R16 | 100 | R-US_0817/22 | P0817/22 | rcl | 1
R17 | 100 | R-US_0817/22 | P0817/22 | rcl | 1
R18 | 56 | R-US_0411/12 | 0411/12 | rcl | 1
R19 | 56 | R-US_0411/12 | 0411/12 | rcl | 1
R20 | 56 | R-US_0411/12 | 0411/12 | rcl | 1
R21 | 39 | R-US_0411/12 | 0411/12 | rcl | 1
R22 | 39 | R-US_0411/12 | 0411/12 | rcl | 1
R23 | 39 | R-US_0411/12 | 0411/12 | rcl | 1
R24 | 39 | R-US_0411/12 | 0411/12 | rcl | 1
R25 | 56 | R-US_0411/12 | 0411/12 | rcl | 1
R26 | 27 | R-US_0411/12 | 0411/12 | rcl | 1
R27 | 56 | R-US_0411/12 | 0411/12 | rcl | 1
R28 | 56 | R-US_0411/12 | 0411/12 | rcl | 1
R29 | 56 | R-US_0411/12 | 0411/12 | rcl | 1
R30 | 27 | R-US_0411/12 | 0411/12 | rcl | 1
R31 | 27 | R-US_0411/12 | 0411/12 | rcl | 1
R32 | 27 | R-US_0411/12 | 0411/12 | rcl | 1
SV1 |  | MA04-2 | MA04-2 | con-lstb | 1
SV2 |  | MA04-2 | MA04-2 | con-lstb | 1
SV3 |  | MA04-2 | MA04-2 | con-lstb | 1
SV4 |  | MA04-2 | MA04-2 | con-lstb | 1
SV5 |  | MA04-2 | MA04-2 | con-lstb | 1
SV6 |  | MA04-2 | MA04-2 | con-lstb | 1
SV7 |  | MA04-2 | MA04-2 | con-lstb | 1
SV8 |  | MA04-2 | MA04-2 | con-lstb | 1

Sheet: isolator_v2_merged
Component Type | Value | Package | adapter | isolator | isolator_bypass | isolator_iso | isolator_jung | isolator_lm317 | pwrload | Required Qty | Qty on Hand | Supplier | Part num. | Order Qty
Regulator | LM317 | D2PAK |  | 3 |  |  |  |  |  | 6 | 4 | Arrow | NCV317BD2TG | 2
Regulator | LM337 | D2PAK |  | 1 |  |  |  |  |  | 2 | 2 | Arrow | LM337BD2TG | 0
Regulator | NCP1117-3.3 | DPAK | 1 | 2 |  |  |  |  |  | 6 |  | Arrow | NCP1117DT33G | 6
Special chip | AD9515 | LFCSP32 | 1 |  |  |  |  |  |  | 2 |  | Arrow | AD9515BCPZ-REEL7 | 2
Special chip | ADUM3401 | SO-16W |  |  |  | 2 |  |  |  | 2 | 4 | Arrow | ADUM141E0BRWZ-RL | 0 | Have ADUM3401C
Special chip | AD8655 | SO-8 |  |  |  |  | 2 |  |  | 2 |  | Arrow | AD8655ARZ-REEL7 | 2
Special chip | ADR4525 | SO-8 |  |  |  |  | 2 |  |  | 2 |  | Arrow | ADR4525ARZ-R7 | 2
Special chip | LT1236-10 | SO-8 |  |  |  |  | 1 |  |  | 1 |  | Arrow | LT1236BCS8-10#PBF | 1
Special chip | ADM7154 | SO8-EP | 1 |  |  |  |  |  |  | 2 |  | Arrow | ADM7154ARDZ-3.3-R7 | 2
Transistor | B44H11 | D2PAK |  |  |  |  | 3 |  |  | 3 | 1 | Arrow | MJB44H11T4-A | 2 |  | Qty of boards
Transistor | B45H11 | D2PAK |  |  |  |  | 1 |  |  | 1 | 1 | Arrow | MJB45H11G | 0 |  | adapter | 2
Cap (electrolytic) | 100u | Code F |  | 4 |  |  | 14 |  |  | 22 |  | Digikey | PCE4442CT-ND |  |  | isolator | 2
Cap (tantalum) | 330u | 7343 | 1 |  |  |  |  |  |  | 2 |  | Digikey | 718-1038-1-ND |  |  | isolator_bypass | 1
Capacitor | 10n | 402 | 4 |  |  |  |  |  |  | 8 |  | Digikey | 490-4516-1-ND |  |  | isolator_iso | 1
Capacitor | 0.1u | 603 | 3 | 10 |  | 30 |  |  |  | 56 |  | Digikey | 1276-1000-1-ND |  |  | isolator_jung | 1
Capacitor | 10n | 603 | 2 | 2 |  |  |  |  |  | 8 |  | Digikey | 1276-1927-1-ND |  |  | isolator_lm317 | 1
Capacitor | 1u | 603 | 1 |  |  |  |  |  |  | 2 |  | Digikey | 1276-6524-1-ND |  |  | pwrload | 4
Capacitor | 1u | 805 | 3 |  |  |  |  |  |  | 6 |  | Digikey | 399-8004-1-ND
Capacitor | 10u | 1206 | 7 | 4 |  |  |  | 4 |  | 26 |  | Digikey | 1276-6767-1-ND
Capacitor | 1u | 1206 |  | 7 |  |  | 5 |  |  | 19 |  | Digikey | 399-1249-1-ND
Connector | Samtec ????? |  | 1 |  |  |  |  |  |  | 2 | 6 | Digikey | 609-1551-ND | 0
Diode | 1N4148 | SOD-123 |  |  |  |  | 8 |  |  | 8 | 9 | Digikey | 1N4148WTPMSCT-ND
Diode | MMSZ5226B | SOD-123 |  |  |  |  | 2 |  |  | 2 |  | Digikey | MMSZ5226BS-FDICT-ND
Diode | MMSZ5235B | SOD-123 |  |  |  |  | 2 |  |  | 2 |  | Digikey | MMSZ5235B-FDICT-ND
Ferrite bead |  | 1206 | 1 | 4 |  |  |  |  |  | 10 |  | Digikey | 732-1623-1-ND
LED |  | 1206 |  |  |  |  | 4 |  |  | 4 | 6 | Digikey | 160-1456-1-ND
Logic chip | 7404 | TSSOP14 |  |  |  | 1 |  |  |  | 1 | 1 | Digikey | 1727-6453-ND
Logic chip | 74164 | TSSOP14 | 1 | 2 |  | 1 |  |  |  | 7 | 2 | Digikey | 1727-6656-1-ND
Logic chip | 74165 | TSSOP16 | 1 | 2 |  |  |  |  |  | 6 | 2 | Digikey | 1727-2063-1-ND
Logic chip | 74574 | TSSOP20 | 1 | 2 |  | 1 |  |  |  | 7 | 2 | Digikey | 1727-6472-ND
Resistor | 0 | 603 | 6 |  |  |  |  |  |  | 12 |  | Digikey | 311-0.0GRCT-ND
Resistor | 1 | 603 | 1 |  |  |  |  |  |  | 2 |  | Digikey | 311-1.0GRCT-ND
Resistor | 22 | 603 | 1 | 1 |  |  |  |  |  | 4 |  | Digikey | 311-22.1HRCT-ND
Resistor | 50 | 603 | 3 |  |  |  |  |  |  | 6 |  | Digikey | 311-49.9HRCT-ND
Resistor | 100 | 603 | 1 | 1 |  |  |  |  |  | 4 |  | Digikey | 311-100HRCT-ND
Resistor | 200 | 603 |  |  |  |  |  | 2 |  | 2 |  | Digikey | 311-200HRCT-ND
Resistor | 499 | 603 |  |  |  |  | 4 |  |  | 4 |  | Digikey | 311-499HRCT-ND
Resistor | 825 | 603 |  |  |  |  | 2 |  |  | 2 |  | Digikey | 311-825HRCT-ND
Resistor | 1.42k | 603 |  |  |  |  |  | 2 |  | 2 |  | Digikey | 311-1.42kHRCT-ND
Resistor | 10k | 603 | 9 | 15 |  |  |  |  |  | 48 |  | Digikey | 311-10.0kHRCT-ND
Resistor | 1k | 603 |  | 3 |  |  |  |  |  | 6 |  | Digikey | 311-1.00kHRCT-ND
Resistor | 2.21k | 603 |  |  |  |  |  | 2 |  | 2 |  | Digikey | 311-2.21kHRCT-ND
Resistor | 4.12k | 603 | 1 |  |  |  |  |  |  | 2 |  | Digikey | 311-4.12kHRCT-ND
Resistor | 0 | 1206 |  |  | 36 |  |  | 4 |  | 40 |  | Digikey | 311-0.0ERCT-ND
Resistor | 1 | 1206 |  | 2 |  |  |  |  |  | 4 |  | Digikey | 311-1.0ERCT-ND
Resistor | 10 | 1206 |  |  |  |  | 4 |  |  | 4 |  | Digikey | 311-10.0FRCT-ND
Resistor | 68.1 | 1206 |  |  |  |  | 4 |  |  | 4 |  | Digikey | 311-68.1FRCT-ND
Resistor | 475 | 1206 |  |  |  |  |  | 1 |  | 1 |  | Digikey | 311-474FRCT-ND
Resistor | 604 | 1206 |  |  |  |  | 1 |  |  | 1 |  | Digikey | 311-604FRCT-ND
Resistor | 649 | 1206 |  |  |  |  | 1 |  |  | 1 |  | Digikey | 311-649FRCT-ND
Resistor | 750 | 1206 |  |  |  |  | 1 |  |  | 1 |  | Digikey | 311-750FRCT-ND
Resistor | 866 | 1206 |  |  |  |  |  | 1 |  | 1 |  | Digikey | 311-866FRCT-ND
Resistor | 1.5k | 1206 |  |  |  |  | 1 |  |  | 1 |  | Digikey | 311-1.50KFRCT-ND
Resistor | 10k | 1206 |  |  |  |  | 4 |  |  | 4 |  | Digikey | 311-10.0KFRCT-ND
Resistor | 1k | 1206 |  |  |  |  | 2 |  |  | 2 |  | Digikey | 311-1.00KFRCT-ND
Resistor | 2k | 1206 |  |  |  |  | 1 |  |  | 1 |  | Digikey | 311-2.00KFRCT-ND
Resistor | 3.01k | 1206 |  |  |  |  | 1 |  |  | 1 |  | Digikey | 311-3.01KFRCT-ND
Resistor 1 W | 27 | Axial |  |  |  |  |  |  | 4 | 16 |  | Digikey | 27W-1-ND
Resistor 1 W | 39 | Axial |  |  |  |  |  |  | 4 | 16 |  | Digikey | 39W-1-ND
Resistor 1 W | 56 | Axial |  |  |  |  |  |  | 8 | 32 |  | Digikey | 56W-1-ND
Resistor 5 W | 100 | Axial |  |  |  |  |  |  | 8 | 32 |  | Digikey | 100W-5-ND
Resistor 5 W | 180 | Axial |  |  |  |  |  |  | 8 | 32 |  | Digikey | 180W-5-ND
Special chip | DS90LV012 | DBV |  | 1 |  |  |  |  |  | 2 |  | Digikey | DS90LV012ATMF/NOPBCT-ND
Special chip | MAX6220 | SO-8 |  |  |  |  | 1 |  |  | 1 |  | Digikey | MAX6220ASA-2.5+-ND
Transistor | BC807 | SOT23 |  |  |  |  | 3 |  |  | 3 | 10 | Digikey | BC807-40LT1GOSCT-ND
Transistor | BC817 | SOT23 |  |  |  |  | 1 |  |  | 1 | 10 | Digikey | BC817-40LT1GOSCT-ND
Special chip | LME49710 | SO-8 |  |  |  |  | 2 |  |  | 2 |  | Mouser | 926-LME49710MAX/NOPB
Connector | SMA |  | 2 |  |  |  |  |  |  | 4 | 20 |  |  | 0
Special chip | ADUM3402 | SO-16W |  |  |  | 13 |  |  |  | 13 | 40 |  |  | 0
Female 0.1" header | 27 pin |  |  | 8 |  |  |  |  |  | 16
Male 0.1" header | 16x2 pin |  |  | 1 |  |  |  |  |  | 2
Male 0.1" header | 24x2 pin |  |  | 2 |  |  |  |  |  | 4
Male 0.1" header | 27 pin |  | 2 |  |  |  |  |  | 2 | 12
Male 0.1" header | 3 pin |  | 2 |  |  |  |  |  |  | 4
Male 0.1" header | 4x2 pin |  | 1 |  |  |  |  |  | 8 | 34
Male 0.1" header | 6 pin |  | 2 |  |  |  |  |  |  | 4
Male 0.1" header | 6x2 pin |  | 2 | 1 |  |  |  |  |  | 6
Male 0.1" header | 8 pin |  | 1 |  |  |  |  |  |  | 2
Male 0.1" header | 8x2 pin |  | 2 |  |  |  |  |  |  | 4

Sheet: arrow
Arrow | LT1236BCS8-10#PBF | 1
Arrow | NCV317BD2TG | 2
Arrow | AD9515BCPZ-REEL7 | 2
Arrow | AD8655ARZ-REEL7 | 2
Arrow | ADR4525ARZ-R7 | 2
Arrow | ADM7154ARDZ-3.3-R7 | 2
Arrow | MJB44H11T4-A | 2
Arrow | NCP1117DT33G | 6

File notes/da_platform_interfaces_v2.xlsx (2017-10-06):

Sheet: interfaces
DA Platform Interfaces |  |  |  | Directions rel. to iso
Version | 2
Date | 2017-03-11
Author | Michael Price
Rpi/FPGA to iso |  | # In | # Out | # IO |  |  |  |  | Ideas
CLKSEL | In | 1 |  |  | 0 = 11.2896, 1 = 24.576 |  |  |  | Add 2nd level of serialization? (SRCLK2 at 1/8 SRCLK freq)
SCLK | In | 1 |  |  | SPI clock, and bit clock for ser/des |  |  |  | MCLK freq = 1/2 of ACLK whatever it is
SRCLK | In | 1 |  |  | Load clock for ser/des |  |  |  | SRCLK = 1/16 ACLK
SRCLK2 | In | 1 |  |  | 2nd level (1/64) load clock for ser/des |  |  |  | SRCLK2 = 1/128 ACLK
MCLK | Out |  | 1 |  | Audio master clock (11.2896/24.576) into FPGA |  |  |  | Fast isolator to carry:
RESET_N | In | 1 |  |  | Reset controlled by FPGA, active low |  |  |  |  | MCLK
SLOTDATA0[5:0] | I/O |  |  | 6 | I2S bus for slot 0 |  |  |  |  | ACLK
SLOTDATA1[5:0] | I/O |  |  | 6 | I2S bus for slot 1 |  |  |  |  | SRCLK
SLOTDATA2[5:0] | I/O |  |  | 6 | I2S bus for slot 2 |  |  |  |  | SRCLK2
SLOTDATA3[5:0] | I/O |  |  | 6 | I2S bus for slot 3 |  |  |  |  | (Use ADUM140E0B - $5.49)
CS_N | In | 1 |  |  | SPI chip select (serialized) |  |  |  | 6-channel medium speed (25 Mb/s) iso
MOSI | In | 1 |  |  | SPI data in |  |  |  |  | SLOTDATA | 12x 2/2 isolators needed
MISO | Out |  | 1 |  | SPI data out |  |  |  |  | ADUM3402C = $6.21 - $3.23/ea in qty 47 from ADI
DIRCHAN | Out |  | 1 |  | Indicator of direction/channel counts (serialized) |  |  |  |  | ADUM142E0B = $5.49 - $2.92/ea in qty 48 from ADI
HWCON | In | 1 |  |  | Hardware control lines for each module (2-level serialized) |  |  |  | Remainder: 4 in, 4 out, medium speed
HWFLAG | Out |  | 1 |  | Hardware response flags for each module (2-level serialized) |  |  |  |  | May as well just have 2 more 2/2 isos - same type
 |  |  |  |  |  |  |  |  | Total iso budget = 1x ADUM140E0B + 14x ADUM142E0B
Totals |  | 8 | 4 | 24 |  |  |  |  |  | About $50.
Total total |  |  |  | 36
USBStreamer to iso |  | https://www.minidsp.com/images/documents/Product%20Brief%20-%20USBstreamer.pdf
MCLK |  | 1
BCK |  | 1 |  |  |  | 12-pin (6x2) 0.1" header |  | In this case, USBStreamer drives audio clock,
LRCK |  | 1 |  |  |  |  |  | not clock board. So we need an LVDS driver.
SDATA[3:0] in |  | 4
SDATA[3:0] out |  |  | 4
Ministreamer to iso |  | https://www.minidsp.com/images/documents/Product%20Brief-%20miniStreamer.pdf
MCLK |  | 1 |  |  |  | Master/slave is configurable with a jumper
BCK in |  | 1 |  |  |  | (I guess that's only relevant for ADC)
LRCK in |  | 1
SDATA in |  | 1 |  |  |  | 10-pin (5x2) 0.1" header
BCK out |  |  | 1
LRCK out |  |  | 1
SDATA out |  |  | 1
Power supply to iso
Unreg 7 V Analog |  |  |  |  |  | Maybe a 16 pin (8x2) cable would be good? 2 pins per supply net, should be hefty
Unreg 7 V Digital
Unreg -22 V
Unreg +22 V
Ground Analog |  |  |  |  |  | Tie analog grounds together on iso, near regulators I guess
Ground Analog HV
Ground Digital
Module to iso
MCLK{p,n} |  |  | 2 |  | Audio master clock 11.2896/24.576 - differential
SLOTDATA[5:0] |  |  |  | 6 | I2S bus (either direction up to 8 ch)
DIR |  | 1 |  |  | Flag for direction 1=DAC 0=ADC
CHAN |  | 1 |  |  | Flag for channels 0=2ch 1=8ch(ish)
SCLK |  |  | 1 |  | SPI clock, and bit clock for ser/des
SRCLK |  |  | 1 |  | Load clock for ser/des
SRCLK2 |  |  | 1 |  | Load clock for ser/des
RESET_N |  |  | 1 |  | Reset controlled by FPGA, active low
CS_N |  |  | 1 |  | SPI chip select (per channel - deser on iso board)
MOSI |  |  | 1 |  | SPI data in
MISO |  | 1 |  |  | SPI data out
HWCON |  |  | 1 |  | Hardware control lines for this module (1-level serialized or const)
HWFLAG |  | 1 |  |  | Hardware response flags for this module (1-level serialized or const)
A7V_UNREG
D7V_UNREG
AN22V_UNREG
AP22V_UNREG
AGND
DGND
D3.3V
A5V
AP15V
AN15V
Clock board to iso
MCLK0{p,n} |  | 2 |  |  | Output to slot - isolator just carries differential lines
MCLK1{p,n} |  | 2
MCLK2{p,n} |  | 2 |  |  |  |  | Note: include unstuffed debug SMA outputs of buffered single-ended clocks
MCLK3{p,n} |  | 2 |  |  |  |  | Note: include Tentlabs and Crystek footprints as well as SMA inputs for ext source
MCLKF{p,n} |  | 2 |  |  | Output to FPGA
D3.3V
D7V_UNREG |  |  |  |  |  |  | Connector format: GND-P-N - 16x2 (one row for clocks+separators, one row for CLKSEL and supplies)
DGND
CLKSEL |  |  | 1 |  | Clock select
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

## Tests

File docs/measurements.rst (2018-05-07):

Measurements
------------

This section provides some measured performance results.  Currently all results pertain to the baseline boards.  These measurements are not enough to provide a complete picture, but hopefully illustrate the potential for good audio performance.

DAC2 and ADC2
=============

**Differential**: The following figures show the combined performance of the DAC2 (AK4490 based) and ADC2 (AK5572 based) with loopback via XLR cables.  It is not possible to separate the contributions of the DAC from those of the ADC, since I don't have any better ADCs or test equipment at home.  Note that the ADC module includes 1 dB of attenuation for overload margin.  



    Frequency response of DAC2/ADC2 loopback at 44.1 kHz sample rate. 

The rolloff above 10 kHz is larger than expected.  The frequency response is down by about 0.7 dB at 20 kHz.  I built a second DAC2 module with different capacitor values in the output filter, in an effort to flatten the response.  However, this has not yet been tested.



    Distortion and noise of DAC2/ADC2 loopback at -3 dBFS.  The top curve is the THD+N ratio or (inverse) SNDR. 

The level of various harmonics seems to be relatively independent of frequency.  The measurement bandwidth is limited to 20 kHz, which causes the steps in 3rd harmonic at 6.7 kHz and in 2nd harmonic at 10 kHz.  The 3rd harmonic lies at about -110 dB and higher order harmonics are lower in level.  I don't know if the bumps in THD+N (noise) below 100 Hz are related to the data analysis, but at least it's below -100 dB at most frequencies.

**Single ended**: The following figures were generated with RCA cable loopback.  Only the "positive" (in-phase) output of the DAC2 is used.
    


    Frequency response of DAC2 single-ended output into ADC2. 

The frequency response is the same except for a 6 dB loss, as expected.



    Distortion and noise at -3 dBFS. 

In single-ended mode the 2nd harmonic is higher at around -100 dB, and in combination with higher noise this results in SNDR around 90 dB.

DAC8 and ADC8
=============

The ADC8 module has sharply rising THD at high input levels, and the board design will need to be examined and revised.  To illustrate the behavior of the DAC8 board, I used the 10 dB attenuator setting on the DAC8.  This reduces the input level and thus the contribution of ADC nonlinearity to distortion.

The DAC8 module does not have differential outputs.  These measurements were performed with loopback via RCA cables.



    Frequency response of DAC8/ADC8 loopback at -3 dBFS, with 10 dB additional attenuation. 

This is as expected given the 10 dB attenuation from the DAC8 and 1 dB attenuation from the ADC8.  Unlike the DAC2, there is no rolloff (beyond the expected digital filter ripple) at high frequencies.



    Distortion and noise at -3 dBFS with 10 dB resistive attenuation. 

Supply-related spurs (multiples of 60 Hz) may be compromising the measurement at low frequencies, but the measurement floor is relatively low.  Distortion is characterized by a rising 2nd harmonic (and to a lesser extent, 3rd harmonic) at high frequencies.  The higher order harmonics also increase somewhat (up to around -108 dB).  Overall SNDR is around 93 dB below 3 kHz and degrades to 88 dB (mostly due to 2nd harmonic) at 10 kHz.

Development discussions
=======================

The following documents provide exploratory, but more detailed, discussions about the performance of baseline system components:

* `Clock distribution`_ (phase noise and integrated jitter)
* `Voltage regulators`_ (on backplane)

.. _`Clock distribution`: https://github.com/pricem/da_platform/raw/master/docs/phase_noise_testing.pdf
.. _`Voltage regulators`: https://github.com/pricem/da_platform/raw/master/docs/reg_testing.pdf

I hope to perform more measurements of clock distribution performance on a completed project.  The voltage regulators are less of a focus since the highest-performing modules will rely on local regulation.

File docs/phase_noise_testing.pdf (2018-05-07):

Clock distribution measurements | July 21, 2017 | Michael Price

Background

The digital audio platform has two clocks, 22.5792 MHz and 24.576 MHz. At any time, one of the clocks is active depending on the desired audio sample rate (44.1 kHz vs. 48/96/192 kHz). The board has to perform this 2:1 muxing and distribute the selected clock to the 4 DAC or ADC modules (over about 12” or 300 mm of PCB) and to an FPGA that buffers the audio samples. The proposed design converts the selected single-ended oscillator output to differential; each module needs to convert back to single-ended.

Phase noise in the clock is one of the error sources in A/D or D/A conversion, in addition to the converter itself and the analog interface (filtering and/or I/V conversion). The measurements in this document illustrate the performance differences between oscillators and quantify the performance impact of the platform’s clock distribution. The intent is to make other hobbyists comfortable using the platform even if they have concerns about phase noise, and to provide data for component selection choices.

Device under test

The prototyping setup consists of two boards: a clock source and clock receiver. On the digital audio platform, both of these components will be interchangeable; the main PCB only has differential traces between the source and each

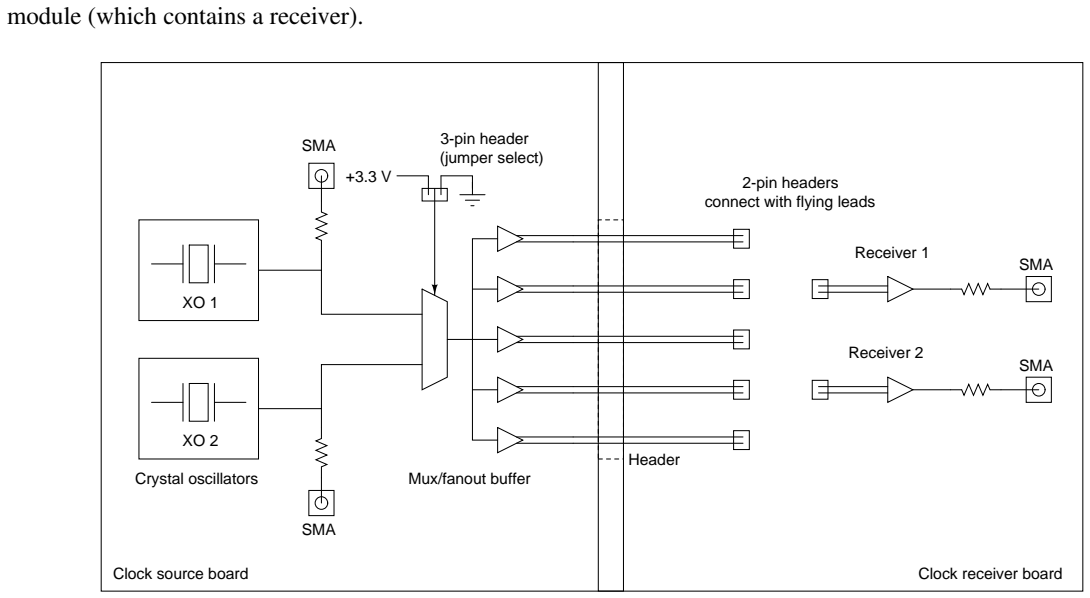
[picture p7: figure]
module (which contains a receiver).; 3-pin header (jumper select); Crystal oscillators; Mux/fanout buffer; Receiver 1; Receiver 2; SMA; 2-pin headers connect with flying leads; Clock source board; Clock receiver board; Header

Figure 1: Setup for phase noise measurements.

There are two interchangeable clock source boards:

- Clock source A uses a 74-series mux (SN74LVC1G3157) and standard LVDS transmitters (FIN1031, FIN1001) to drive differential outputs. It is populated with two crystal oscillators (selectable by jumper):
1. Epson SG-210STF (2.5x2.0 mm SMD), 22.5792 MHz.
Specified phase noise is -145 dBc/Hz at 1 kHz offset.
2. Crystek CCHD-957 (14x9 mm SMD), 22.5792 MHz.
Specified phase noise is -149 dBc/Hz at 1 kHz offset. (-97 dBc/Hz at 10 Hz offset)

This board is powered by a UA78M33 regulator. It is meant to represent a “low cost” stuffing option for the clock source, regardless of which oscillators are used.

- Clock source B uses an ADCLK948 to perform muxing and drive differential outputs. Its oscillators are:
1. Crystek CCHD-957 (14x9 mm SMD), 24.576 MHz.
Specified phase noise is -149 dBc/Hz at 1 kHz offset. (-98 dBc/Hz at 10 Hz offset)
2. Tentlabs XO (11x11 mm DIP), 11.2896 MHz.
Specified phase noise is -151 dBc/Hz at 1 kHz offset. (-93 dBc/Hz at 10 Hz offset)

This board is powered by an ADM7154 regulator with a 330 µF tantalum cap for reference bypass. It is meant to represent a “high performance” (high cost) stuffing option for the clock source.

Each clock source board has 5 differential clock outputs routed to a 32-pin 0.1”-pitch header that connects to a socket on the clock receiver board. (These outputs are named CLK0, CLK1, CLK2, CLK3, and CLKF.)

There are two receivers (differential to single-ended converters) on the clock receiver board:

- Clock receiver A uses a DS90LV12 LVDS receiver powered by a UA78M33 regulator. It is meant to represent a “low cost” option for DAC/ADC modules.
- Clock receiver B uses an AD9515 LVPECL receiver powered by an ADM7154 regulator. It is meant to represent a “high performance” (high cost) option for DAC/ADC modules.

Each of these receivers has a 2-pin 0.1” header for differential input and is AC coupled by 10 nF capacitors. Meanwhile, the 5 outputs of the clock source board are routed (over traces from 3.5” to 12” in length) to 2-pin 0.1” headers. This is meant to capture the effect of different routing lengths (to the 4 modules and FPGA) that are expected on the final boards. One of these headers can be connected to each receiver using jumper wires or zero-ohm resistors.


Figure 2: Photo of setup for phase noise measurements.

Results

I am fortunate to work for a company that has test equipment including a phase noise analyzer. I did not experiment thoroughly with the test setup, but I don’t believe the phase noise results presented here are close to the floor of the analyzer.

Measurements made with clock source A had large high-frequency spurs, mostly above 1 MHz but with one as low as 84 kHz. The amplitude of these spurs varied, and in some cases they dominated the integrated jitter calculations. This made it hard to evaluate the relative performance of different oscillator, trace, and receiver combinations. So, for the following analysis, I used software post-processing to remove the large spurs (peaks of approximately 6 dB or more). I still need to trace and eliminate the cause of the spurs, and verify that real-world performance is comparable

Oscillator | Jitter | Excess jitter
| | Receiver A | Receiver B
Crystek CCHD-957 | 1.726 ps | 0.427 ps | 0.529 ps
| 0.196 ps, >100 Hz
Epson SG-210STF | 0.876 ps | 0.510 ps | 0.189 ps
| 0.267 ps, >100 Hz

Table 1: RMS jitter for clock source A and excess jitter from each receiver.

to the filtered results presented here. (Because the spurs were present in the clocks measured at the oscillator outputs, I believe the issue is related to the power supply or ground configuration. In particular, I may have incorrectly configured the ADM7154 regulator used on source A, since source B uses the same PCB layout and doesn’t have the same problem.)

Source and receiver combinations

Figure 3 compares the 2 oscillators on clock source A (low-cost option) with large spurs removed. Table 1 shows the integrated RMS jitter for each oscillator, as well as the excess jitter introduced by the LVDS transmitter in conjunction with either of the two receiver options. The jitter is computed by integrating the post-processed (i.e. spurs removed) phase noise from 10 Hz to 5 MHz.

It isn’t clear why some of the measurements with the Crystek oscillators show higher close-in phase noise than the others. It’s possible that the sweeps were performed when the power supplies were still settling, or that there was some other mistake in the measurement procedure. To work around this, I integrated excess jitter from one measurement to the next only at the frequencies at which phase noise was higher in the “excess” measurement. This is based on my understanding that it is not possible to “subtract” jitter. I also integrated jitter starting at 100 Hz instead of 10 Hz, so you can see how much of the jitter is from the low end of the audio band–in this case, most of it.

It is hard to compare the CCHD-957 oscillator to the SG-210STF due to the low frequency anomalies with the Crystek. But on clock source A, these two oscillators deliver similar performance with the CCHD-957 having a somewhat lower phase noise (except for a hump from 10–50 kHz) at higher frequencies.

The difference between the two receiver options is apparent in this plot also. Receiver B introduces about 6 dB of extra phase noise starting at 1 kHz. (Notice that for the SG-210STF the phase noise plot with receiver B has the same hump as the CCHD-957 visible above 10 kHz, though it doesn’t appear in the direct measurement. Why?) Receiver A has a larger effect, degrading the phase noise by 10–20 dB starting around 300 Hz. The phase noise introduced by receiver A is large enough to mask the differences between the two oscillators. When integrated, the jitter added by receiver A is about 0.5 ps, and the jitter added by receiver B is about 0.2 ps. TODO: Investigate why the integrated excess jitter for the CCHD-957 is wonky.

Figure 4 and table 2 show similar results for source B, which compares the Tentlabs XO and another Crystek CCHD-957. On this board, both oscillators perform much better at low frequencies. The CCHD-957 is around -105 dBc/√
Hz at 10 Hz offset and -135 dBc/√
Hz at 100 Hz offset (better than the datasheet performance), for a total of 0.124 ps RMS jitter. The Tentlabs XO is almost as good at low frequencies, but has a higher “floor” at moderate to high frequencies, though it still integrates out to less than 1 ps RMS. With the Tentlabs XO, it is hard to see the difference between the two receiver options. With the CCHD-957, receiver B brings the floor up by about 6 dB at high frequencies; you can see this effect starting as low as 100 Hz due to the lower noise in the direct measurement. As before, receiver A adds more broadband phase noise: about 0.4 to 0.5 ps RMS jitter. (There is a scaling difference on the phase noise plot due to the difference in oscillator frequencies; that’s why the CCHD-957 with receiver A is about 3 dB higher than the Tentlabs XO with receiver A, even though its RMS jitter is lower.)

It looks like the oscillators on clock source B perform better than those on clock source A, probably due to the lower noise power supply. Again, keep in mind that I used post-processing to remove high-frequency spurs, so these

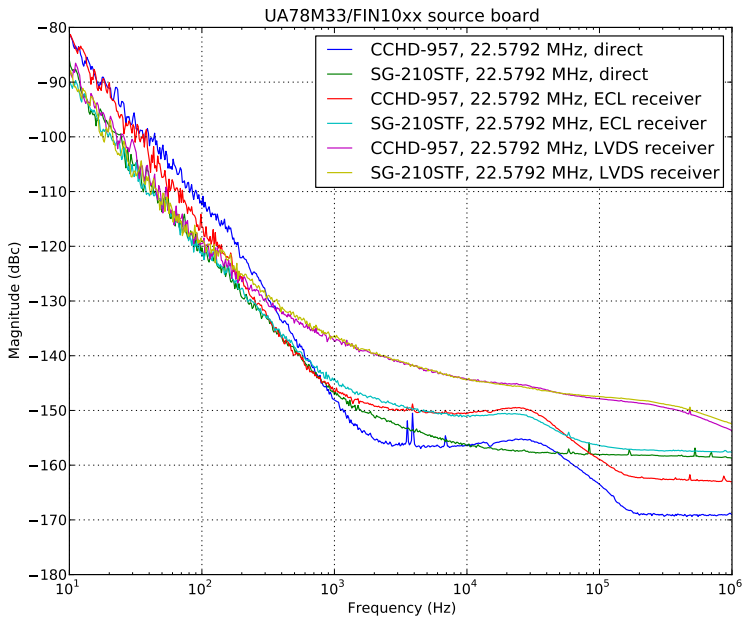
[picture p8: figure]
Frequency (Hz); Magnitude (dBc); UA78M33/FIN10xx source board; CCHD-957, SG-210STF,; 22.5792 MHz, direct 22.5792 MHz,; direct

CCHD-957, SG-210STF, | 22.5792 MHz, ECL receiver 22.5792 MHz, | ECL receiver
CCHD-957, SG-210STF, | 22.5792 MHz, LVDS receiver 22.5792 MHz, | LVDS receiver

Figure 3: Comparison of oscillators on clock source A, with three measurement options: at the oscillator, using receiver A (LVDS), and using receiver B (ECL).

Oscillator | Jitter | Excess jitter
| | Receiver A | Receiver B
Crystek CCHD-957 | 0.124 ps | 0.403 ps | 0.132 ps
Tentlabs XO | 0.842 ps | 0.504 ps | 0.217 ps

Table 2: RMS jitter for clock source B and excess jitter from each receiver.

measurements will need to be repeated once that problem is fixed.

Trace lengths

One question is whether the length of the trace matters, and if it does, does that depend on the source/receiver combination? To investigate, I compared the 5 available traces with all 4 source/receiver combinations, using the Crystek oscillators. These results are summarized in table 3, with phase noise plots and discussion thereafter.

Figure 5 shows a comparison of trace lengths for source A and receiver A, with the direct measurement shown for reference (note again that the higher close-in phase noise is probably an anomaly). Very little difference is apparent in the phase noise spectra, and table 3 bears this out with integrated excess jitter (attributed to the source/receiver chain) in a very narrow range of 0.412–0.427 ps RMS.

Figure 6 combines source A with receiver B. It is clear that receiver B introduces less phase noise than receiver A above 300 Hz. However, the close-in phase noise does seem to depend on the trace length, with the longer traces (9” or 12”) shifted up by 4–6 dB. It’s possible that this is just a measurement anomaly similar to the higher close-in phase noise in the direct measurement. However, it does indicate the possibility that the trace length may have an impact on this source/receiver combination. This may be because the LVDS transmitter, with its relatively low drive strength

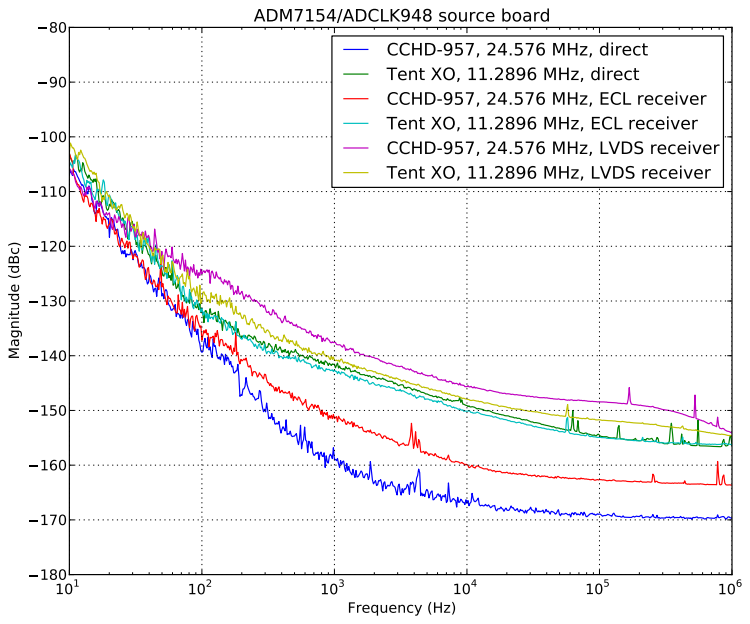
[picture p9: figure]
Frequency (Hz); Magnitude (dBc); ADM7154/ADCLK948 source board; CCHD-957, 24.576 MHz, Tent XO,; 11.2896 MHz, direct; direct; 11.2896 MHz, ECL receiver; ECL receiver; 11.2896 MHz, LVDS receiver; LVDS receiver

Figure 4: Comparison of oscillators on clock source B, with three measurement options: at the oscillator, using receiver A (LVDS), and using receiver B (ECL).

(3.5 mA), is unable to drive the capacitance of the longer traces without a slew rate degradation at the receiver. (Keep in mind that these measurements involved extra 0.1” headers and 5” long flying leads in addition to the differential traces between source and receiver, so the situation is likely to improve in the final design.)

Figure 7 combines source B with receiver A. There is a small (1–2 dB) broadband phase noise difference between the traces. However, it’s unclear if this is due to the trace length or some other aspect of the PCB layout. The excess jitter varies from 0.427–0.629 ps RMS. The degraded close-in phase noise with the CLK3 trace is probably an anomaly.

Figure 8 shows the results with source B and receiver B (the most expensive option). Phase noise performance doesn’t appear to be affected by trace length. TODO: Investigate why the integrated excess jitter for CLKF is so high.

Power supply and vibration sensitivity

In addition to the trace length, I did a couple other experiments to investigate the behavior of the CCHD-957 oscillators. Figure 9 shows the apparent effect of different power supply regulators on the oscillator outputs (before the transmitter). Two of the traces were taken with clock source A, and one with clock source B. (Note that the clock frequencies are different, but the difference is small enough to avoid drastically scaling the phase noise spectra.) For one of the measurements, I disconnected the output of the UA78M33 regulator and connected the low noise power supply built into the phase noise analyzer. This improved the results, especially in the range between 3–100 kHz. (Maybe the phase noise humps seen with clock source A are related to the UA78M33 regulator?) In general, it appears that the CCHD-957 is sensitive to power supply noise.

I was also curious about the affect of vibration on the oscillator. I wasn’t able to create any noticeable spurs by stimulating the source board with my voice, which means that the CCHD-957 isn’t egregiously sensitive to vibration. However, I was able to see a difference in the phase noise spectrum when I rapidly tapped on the table beneath the

Source | Trace | Excess jitter
| | Receiver A (LVDS) | Receiver B (ECL)
Source A (LVDS) | CLKF (3.5”) | 0.412 ps | 0.137 ps
Source A (LVDS) | CLK0 (4”) | 0.418 ps | 0.142 ps
Source A (LVDS) | CLK1 (5”) | 0.425 ps | 0.189 ps
Source A (LVDS) | CLK2 (9”) | 0.421 ps | 0.869 ps
Source A (LVDS) | CLK3 (12”) | 0.427 ps | 0.611 ps
Source B (ECL) | CLKF (3.5”) | 0.629 ps | 0.283 ps
Source B (ECL) | CLK0 (4”) | 0.427 ps | 0.153 ps
Source B (ECL) | CLK1 (5”) | 0.462 ps | 0.154 ps
Source B (ECL) | CLK2 (9”) | 0.465 ps | 0.142 ps
Source B (ECL) | CLK3 (12”) | 0.545 ps | 0.145 ps

Table 3: Excess jitter for different trace lengths.

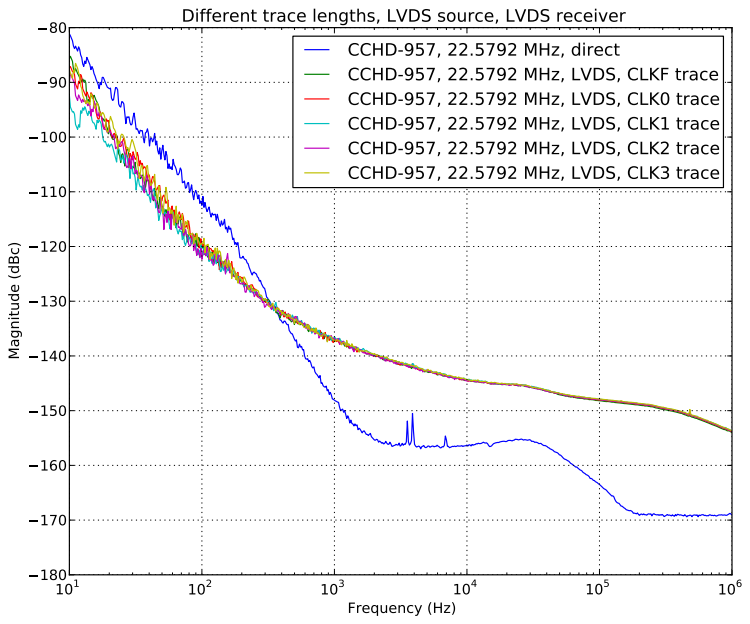
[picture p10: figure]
Frequency (Hz); Magnitude (dBc)

Different trace lengths, LVDS source, LVDS receiver CCHD-957, 22.5792 MHz, direct CCHD-957, 22.5792 MHz, LVDS, CLKF trace

CCHD-957, 22.5792 MHz, LVDS, CLK0 trace CCHD-957, 22.5792 MHz, LVDS, CLK1 trace

CCHD-957, 22.5792 MHz, LVDS, CLK2 trace CCHD-957, 22.5792 MHz, LVDS, CLK3 trace

Figure 5: Comparison of differential trace lengths for Crystek 22.5792 MHz oscillator on source board A, with receiver A.

PCBs. Figure 10 shows this effect, with the spur-removal postprocessing disabled. The excess jitter from the vibrations mixing into the oscillator output is 0.069 ps, smaller than the impact of the clock distribution circuits evaluated above.

Conclusion

These measurements examined the impact of supply regulators, oscillators, differential transmitters and receivers, and PCB traces on phase noise performance. Of the 3 oscillators tested, the Crystek CCHD-957 has the lowest phase noise. (There are probably better oscillators but I didn’t try them; finding the best oscillator wasn’t the main goal here.) It is quite sensitive to power supply noise but (unscientifically speaking) not sensitive to small amounts of

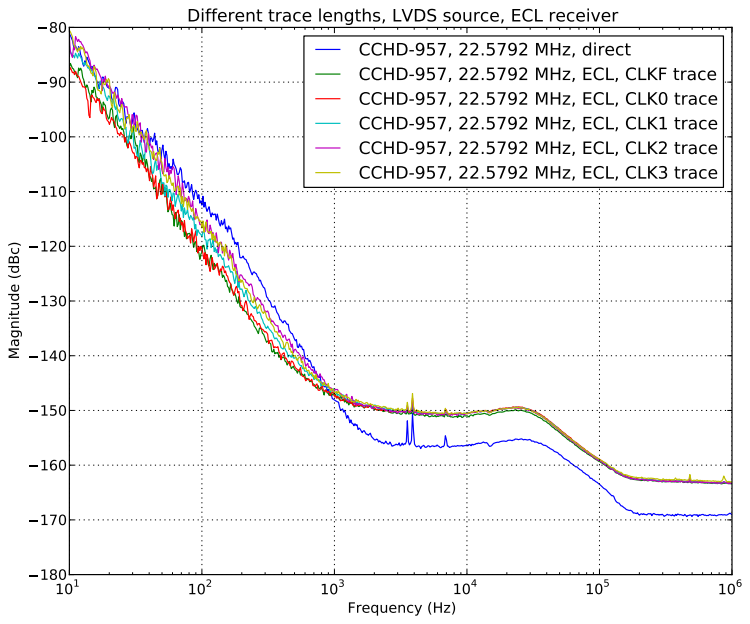
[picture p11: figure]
Frequency (Hz); Magnitude (dBc)

Different trace lengths, LVDS source, ECL receiver CCHD-957, 22.5792 MHz, direct CCHD-957, 22.5792 MHz, ECL, CLKF trace

CCHD-957, 22.5792 MHz, ECL, CLK0 trace CCHD-957, 22.5792 MHz, ECL, CLK1 trace

CCHD-957, 22.5792 MHz, ECL, CLK2 trace CCHD-957, 22.5792 MHz, ECL, CLK3 trace

Figure 6: Comparison of differential trace lengths for Crystek 22.5792 MHz oscillator on source board A, with receiver B.

vibration. Purpose-built LVPECL clock distribution chips introduced less phase noise than their LVDS counterparts; this difference was more pronounced in the receiver than in the transmitter. It appears that either LVDS or LVPECL schemes can tolerate 12” long differential traces.

Finally, even with the best components tested, differential clock distribution does degrade the performance of a good oscillator like the CCHD-957. The excess phase noise is mostly at 1 kHz and higher offsets, and integrates out to around 0.15 ps RMS (assuming 5 MHz bandwidth). This may be an unavoidable price to pay for synchronizing mul-tiple DAC/ADC modules to a single oscillator across a physically large PCB. I cannot predict whether this difference will be measurable or subjectively noticeable in an audio application.

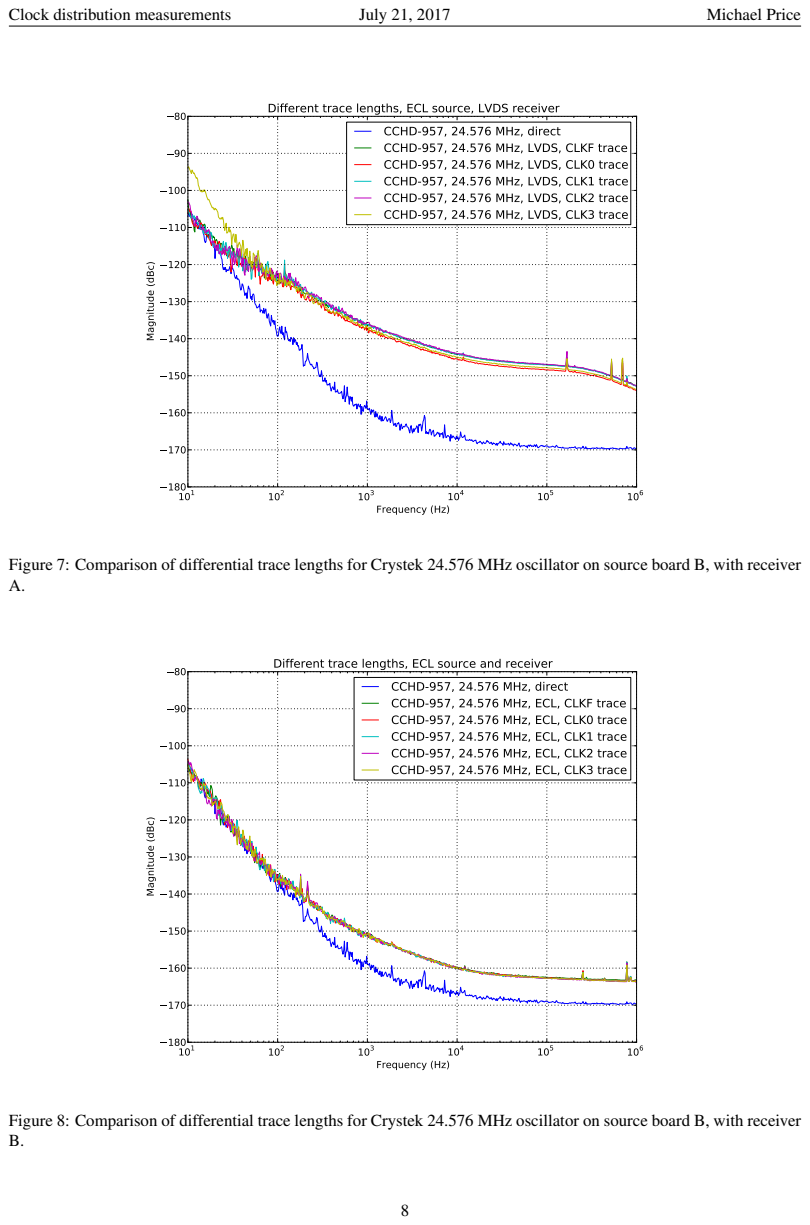
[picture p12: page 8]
Frequency (Hz); Magnitude (dBc)

Different trace lengths, ECL source, LVDS receiver

CCHD-957, 24.576 MHz, direct CCHD-957, 24.576 MHz, LVDS, CLKF trace

CCHD-957, 24.576 MHz, LVDS, CLK0 trace CCHD-957, 24.576 MHz, LVDS, CLK1 trace

CCHD-957, 24.576 MHz, LVDS, CLK2 trace CCHD-957, 24.576 MHz, LVDS, CLK3 trace

Figure 7: Comparison of differential trace lengths for Crystek 24.576 MHz oscillator on source board B, with receiver

Different trace lengths, ECL source and receiver

CCHD-957, 24.576 MHz, direct CCHD-957, 24.576 MHz, ECL, CLKF trace

CCHD-957, 24.576 MHz, ECL, CLK0 trace CCHD-957, 24.576 MHz, ECL, CLK1 trace

CCHD-957, 24.576 MHz, ECL, CLK2 trace CCHD-957, 24.576 MHz, ECL, CLK3 trace

Figure 8: Comparison of differential trace lengths for Crystek 24.576 MHz oscillator on source board B, with receiver

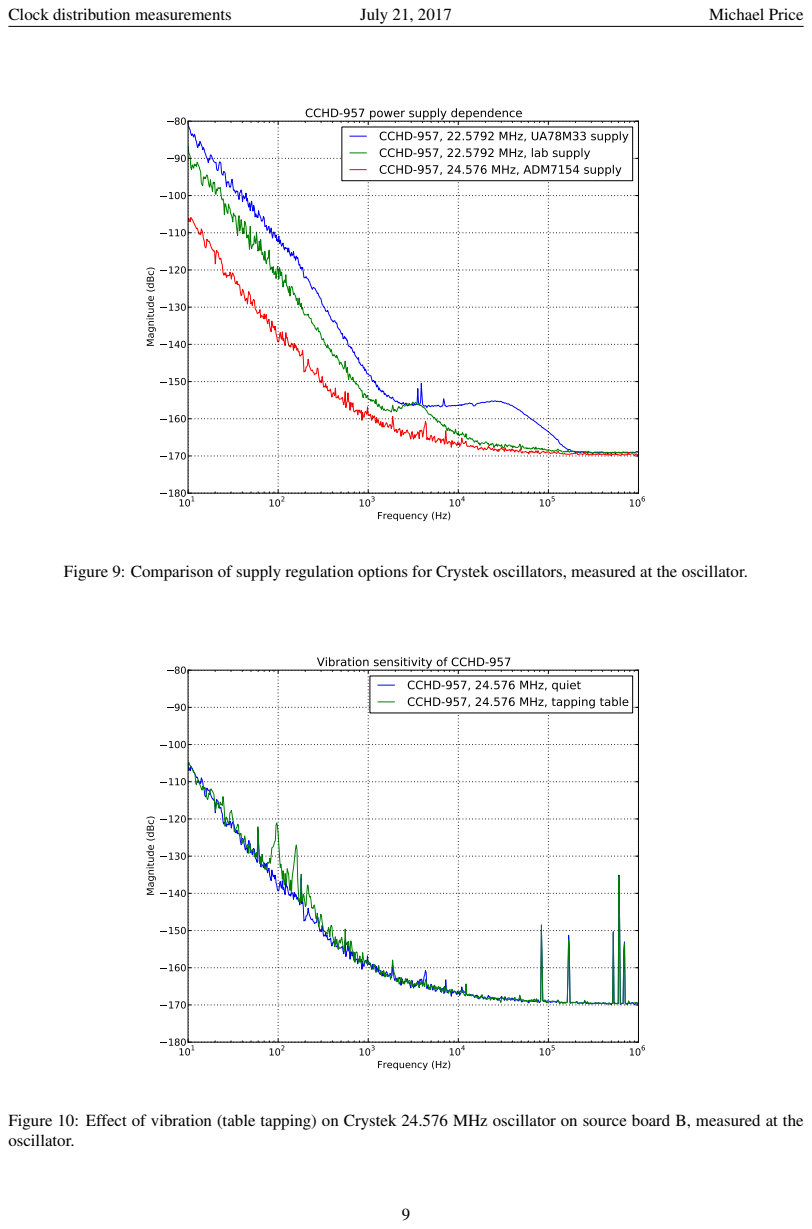
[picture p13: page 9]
Frequency (Hz); Magnitude (dBc)

CCHD-957 power supply dependence

CCHD-957, 22.5792 MHz, UA78M33 supply CCHD-957, 22.5792 MHz, lab | supply

CCHD-957, 24.576 MHz, ADM7154 supply

Figure 9: Comparison of supply regulation options for Crystek oscillators, measured at the oscillator.

Vibration sensitivity of CCHD-957

CCHD-957, 24.576 MHz, quiet
CCHD-957, 24.576 MHz, tapping table

Figure 10: Effect of vibration (table tapping) on Crystek 24.576 MHz oscillator on source board B, measured at the
oscillator.

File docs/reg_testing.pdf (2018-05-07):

Regulator measurements | July 2, 2017 | Michael Price

The digital audio platform provides supply regulators for the most commonly used voltages, so that DAC/ADC modules do not need to provide their own regulators. There are four regulators, for ±15 V, +5 V, and +3.3 V. Of course, any amount of local supply regulation can be included on a module–the unregulated outputs of the rectifiers are also connected to the module. The unregulated supply voltages are approximately ±22 V and +7 V.

I constructed a test platform to evaluate the performance of these regulators and identify any design mistakes. This turned out to be quite a learning experience as the regulators’ performance probed the limits of the measurement setup. These limits will be discussed below. (There were a few design mistakes also, so it was a useful exercise even if the measurements didn’t turn out perfectly.)

The signal generator and analyzer was a PC with an Asus Xonar Essence STX sound card and Jensen CI-2RR isolation transformer for the input. The test bandwidth was 10 Hz to 20 kHz. Briefly, the regulators were exercised as follows:

- To inject an AC signal on the input, the sound card output was buffered and level shifted (via a Zener diode) to the ADJ terminal of an LM317/LM337 regulator. The regulator ensures the output voltage is 1.25 V above the voltage at the ADJ pin. This stimulus was fairly accurate if the capacitive load was kept small and the dropout voltage was sufficiently large. A stimulus of 100 mV RMS was used for all tests.
- To inject an AC current into the output, the sound card output was buffered and connected to an op amp based current source, regulating the voltage across a 25 ohm resistor. The DC current was 100 mA and an AC compo-nent of 4 mA was used for all tests.

The test board is shown in figure 1. The top side contains a rectifier and stimulus circuitry and the bottom contains the regulators. (In retrospect, it would have been better to put the rectifier on a separate board to reduce the ground errors introduced by ripple currents.) Jumpers are used to select which regulator is being tested. The four SMA connectors allow injecting input voltage and load current, and monitoring the input and output of the active regulator. The socketed Zener diodes set the DC input level (unless otherwise specified, a 16 V Zener was used, and the input was ±19.75 V.)

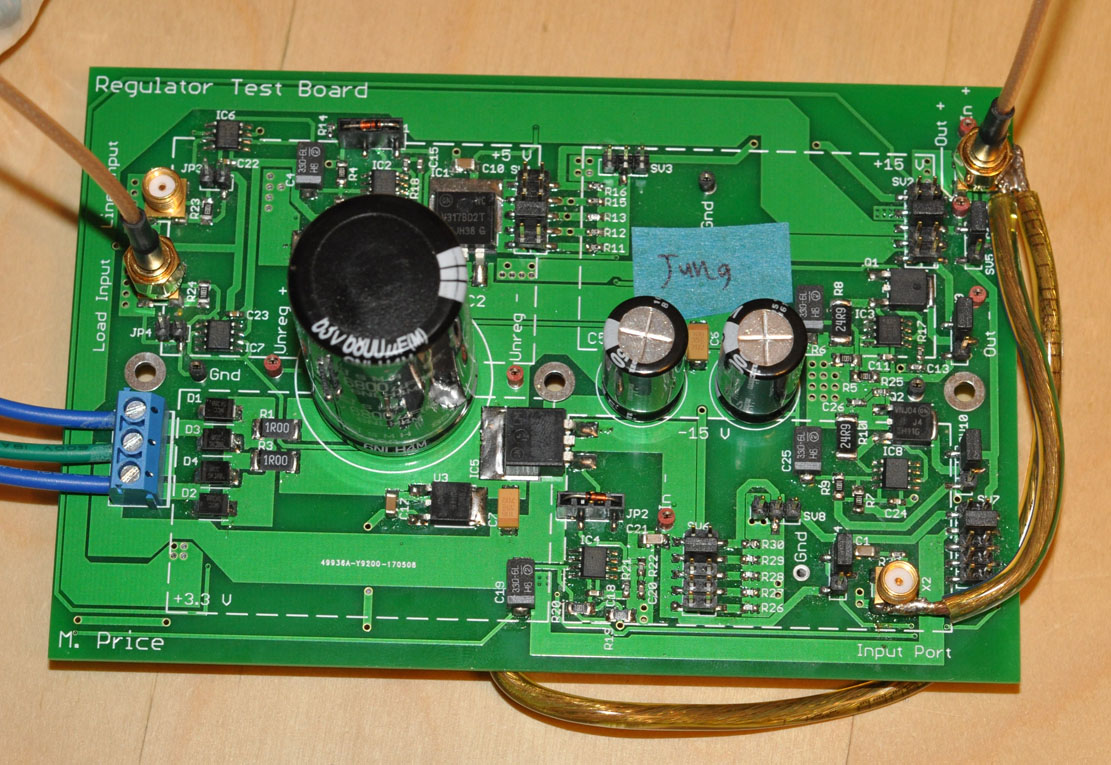
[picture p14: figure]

Figure 1: Regulator testing board

I assembled two boards. One was stuffed with components for Jung regulators [2] and one with lower cost LM317/LM337 regulators. In figure 2 you can see the Jung regulator option. D2PAK preregulators and pass tran-sistors allow a rectangular heat spreader to be placed under the board. (Note that the +5 and +3.3 V versions of the

Jung regulator do not include preregulators, in order to reduce the required dropout voltage.) Figure 3 shows the LM317/337 option.

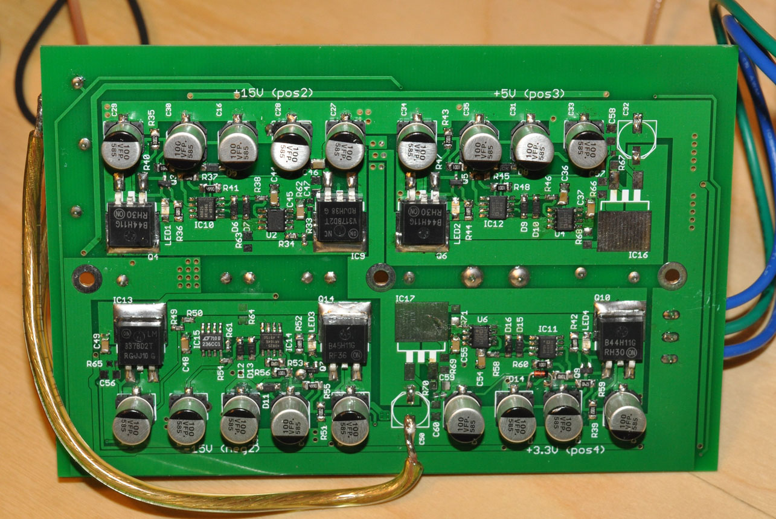
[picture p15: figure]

Figure 2: Regulators shown on bottom (Jung stuffing option)

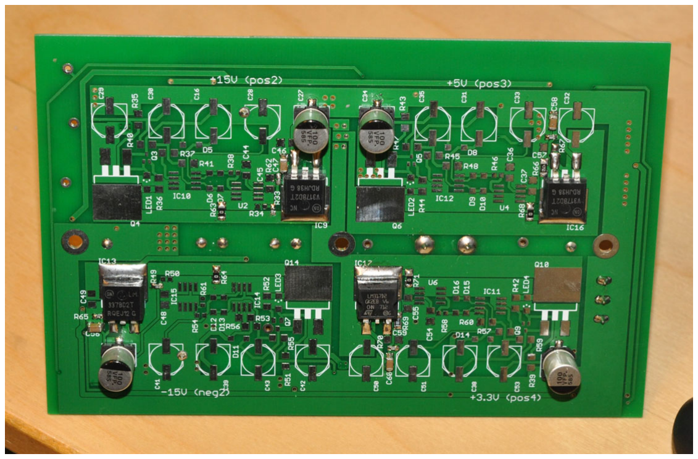
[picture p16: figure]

Figure 3: Regulators shown on bottom (LM317/337 stuffing option)

The first step in measuring was to measure the frequency response from the computer to the input port of the regulator; see figure 4. This looks about as you’d expect, with a low frequency rolloff from the soundcard and/or isolation transformer. There is some shelving at high frequencies, perhaps due to the limited slew rate of the LM317 driving the regulator input. (This device was driving a capacitive load of 11 µF.)

By observing the output of the regulator instead of the input, we can measure the line rejection. Figure 5 shows the line rejection of the LM317/337 regulators and figure 6 shows the Jung regulators.

Frequency (Hz); Magnitude (dB); Frequency response at input port; Jung +15 V Jung +5 V; Jung +3.3 V Jung -15 V Meas. floor

Figure 4: Input port calibration

The LM317 regulators offer good line rejection of more than -80 dB at moderate frequencies. The performance of the +5 V and +3.3 V regulators is similar to that shown in the datasheet (the ADJ pin was bypassed with 10 µF as recommended). The comparatively poor performance of the -15 V regulator is probably caused by the test setup; see below.

Frequency (Hz); Magnitude (dB); Line rejection; Meas. floor

Figure 5: Line rejection of LM317/337 regulators

The line rejection of the Jung regulators is much better, as you would expect given that both the reference and error amplifier are supplied by the output voltage. The ±15 V regulators, which include preregulators, are probably better than the measurement floor (around 105 dB) over most of the audio band. The +5 V and +3.3 V versions, without preregulators, still provide more than 100 dB of line rejection at low frequencies, but this seems to degrade faster as frequency increases.

It isn’t clear how much of the high frequency degradation is caused by the test setup. Jung’s measurements of the LM317 show line rejection of about 75 dB at 10 kHz, and 50 dB at 10 kHz for the LM337 [1]. This is about 10 dB

better than what I measured.; Frequency (Hz); Magnitude (dB); Line rejection; Jung +15 V Jung +5 V; Jung +3.3 V Jung -15 V; Meas. floor

Figure 6: Line rejection of Jung regulators

Next, we look at the noise density of the regulators. This was obtained by simply monitoring the output of the regulator with a DC load of 100 mA. The LM317/337 results are shown in figure 7 and the Jung regulator results are shown in figure 8.
The LM317 regulators all have a noise floor of around 100 nV/√
Hz or 15 µV RMS over the audio band. You can see some harmonics of 60 Hz visible on the spectrum; this could be due to the finite line rejection of the regulators, or to ground errors introduced by the rectifier. Again, the -15 V regulator performance is much worse–I should investigate this. Jung measured 180 nV/√

Hz for the LM317 and 210 nV/√ Hz for the LM337 [1].

The Jung regulators exhibit lower noise. They are close to the noise floor (sorry, I should have done this with an extra LNA). The output of the +5 and +3.3 V regulators is indistinguishable from the measurement floor of about 3.7 µV RMS integrated over the audio band (24 nV/√

Hz), so it’s probably under 10 nV/√ Hz. The ±15 V regulators
give about 5.1 µV, indicating that their actual noise contribution is about 3.5 µV; there is more noise at the lowest frequencies, but from 100 Hz to 20 kHz it looks like about 15 nV/√
Hz. There are also some 60 Hz harmonics appearing in the output spectra, probably related to the grounding in the test setup.

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


Output impedance measurements are shown in figures 9 and 10. The LM317 regulators have output impedance between 50–70 mΩ. Most of this is probably the resistance of the PCB traces and jumpers between the output pin and the current load.

The output impedance of the Jung regulators is lower, between 10–20 mΩ. This is probably caused by the addition of separate sense traces (for feedback) that go most of the way to the load on the test board. However, the parasitic resistances still swamp the output impedance of the regulator (expected to be in the µΩ range). The lesson here is that to exploit the low output impedance of a regulator, you need the feedback sense connections (both positive and negative) to be connected very close to the load. This is not possible with a 3-terminal regulator, and is not the case in most implementations I’ve seen with discrete regulators.

Frequency (Hz); Magnitude (mOhm); Output impedance; LM317 +15 V LM317 +5 V LM317 +3.3 V LM337 -15 V Meas. floor

Figure 9: Output impedance of LM317/337 regulators

The main finding of this study was that my implementation of the Jung regulators is probably competent, but to properly measure such good regulators is a non-trivial task. So we may never know for sure.

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


Addendum: example measurement problems

Please see figure 11 for an illustration of the challenges in performing these measurements. The regulator circuit was not changed. Instead, I added a 12 awg wire to reduce the impedance between the regulator ground and the ground of the output connector. This wire also bypasses some sources of ground current (stimulus circuits and rectifier).

After this change, the line rejection improves by 10–20 dB. The declining line rejection at high frequencies is still suspicious. Not only do the 60 Hz harmonics disappear from the noise spectrum, but the overall noise level improves by 6 dB. Why does changing a ground connection affect the broadband noise? I’m not sure.

Frequency (Hz); Magnitude (dB); Line rejection; Original With ground wire; PSD (nV / sqrt(Hz)); Output noise spectral density

Figure 11: Line rejection and noise density of Jung -15 V regulator before and after adding an additional ground wire to the PCB.

Adding another wire to the ground on the +3.3 V regulator improved the high-frequency line rejection by around 5 dB, but made the noise spectrum slightly worse.

Frequency (Hz); Magnitude (dB); Line rejection; With ground wire Original; PSD (nV / sqrt(Hz)); Output noise spectral density

Figure 12: Line rejection and noise density of Jung +3.3 V regulator before and after adding an additional ground wire to the PCB.

Another change that made an impact was to try powering the board with a DC supply, in other words to keep the rectifier on a separate board. This seemed to help with line rejection, and reduced the amount of 60 Hz-related spuriae in the output. However, I was only able to use this setup for the +5 and +3.3 V regulators because the DC output of my other supply wasn’t high enough. One thing to note was that I also tried removing the filter caps, and this degraded the line rejection.

Frequency (Hz); Magnitude (dB); Line rejection; Same PCB Separate PCB; No filter caps; PSD (nV / sqrt(Hz)); Output noise spectral density; Same PCB Separate PCB No filter caps

Figure 13: Line rejection and noise density of Jung +3.3 V regulator using different unregulated supplies.

Note that I did not perform any of these performance-enhancing experiments with the LM317/337 test board. It’s likely that those regulators perform better than the above graphs would indicate.

## References

[1] Walt Jung. Regulators for high-performance audio: part 2. The Audio Amateur, (2):20–35, 1995.
[2] Walt Jung. Improved positive/negative regulators. Audio Electronics, (4):8–19, 2000.
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

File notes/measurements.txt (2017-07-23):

Measurements on DA platform

1/2/2017
--------

"Good" channel distortion vs input level
Level shown by Arta seems to be -5.9 dB relative to 0 dBFS on DAC input (note: unbalanced)
Power supply noise floor is at about -79 dB rel 0 dBFS (not good...)

Level       THD         THD (dB)    THD+N       Notes
-----       ---         -----       -----       ----
-60 dB      0.39%       -48.2 dB    11.24%      
-40 dB      0.031%      -70.2 dB    1.13%       May be confusing THD and noise at this level and below?
-30 dB      0.0092%     -80.7 dB    0.36%
-25         0.0054%
-22         0.0042%
-20 dB      0.0034%     -89.4 dB    0.11%
-18         0.0045%
-15         0.0077%
-10 dB      0.019%      -74.4 dB    0.040%
-6 dB       0.028%      -71.1 dB    0.034%
-3 dB       0.033%      -69.6 dB    0.033%
-1 dB       0.035%      -69.1 dB    0.034%
0 dB        0.037%      -68.6 dB    0.034%      THD up to 0.13% at 5 kHz, 0.06% at 28 Hz

"Bad" channel
-40 dB at 1k: THD = 0.80%, output = -61.5 dB (-16 rel. good channel)

Try again: 0.034%, -46.0
-> just had to remove that stupid resistor
-60 dB: THD = 0.45, THD+N=11.72
0 dB: THD = 0.0080, THD+N=0.014
-20 dB: THD = 0.0024

-> Removing 1k resistors on the "good" channel improves its THD further, now below -80 dB at full scale

Supply noise floor might have been mostly from the sound card:
- Removing the isolation transformer makes SNR horrible; 60% THD+N at -60 dB
- Adding isolation transformer with amp makes it much quieter; hum about the same level as hiss (XLS1500 cranked to max)
- In the stereo, haven't had a problem

-> Warrants further investigation, i.e. adding preamp or distortion magnifier

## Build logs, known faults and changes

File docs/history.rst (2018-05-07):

History
-------

This project has been in the works for a while.  It was originally conceived in 2008 as a CD player built around a mini-ITX PC.  In 2009 I designed a set of PCBs and a custom chassis to hold everything.  Some of the design principles were established then: galvanic isolation of all digital signals, 2-channel and 8-channel DACs and ADCs, 4 modules per chassis.  I acquired a Digilent Nexys2 FPGA board for the digital interfaces.  However, my FPGA skills lagged behind my ambitions and the PCBs I had designed weren't very well thought out.  I more-or-less abandoned the project and, for my own stereo system, continued using a CD player and an analog active crossover.  

A few years later, I ended up doing research in digital circuits.  This made the digital design for the FPGA seem much less intimidating.  In 2013, I decided to finish the missing pieces and resurrected the original years-old hardware.  I was able to demonstrate the concept of an FPGA-controlled USB DAC with the DSD1792A.  However, I found many problems with the original PCB designs and my architecture was complex and unwieldy.  Also, the Nexys2 FPGA platform was no longer supported by current tools; in 2015 I switched to a ZTEX board with a modern FPGA.  In 2016, after finishing graduate school, I decided to revise the PCBs and construct a complete chassis.  This became the "baseline" implementation of the project, with plans to add other interchangeable components in the future.  In December 2017 I started using the device as a digital crossover and streaming server in my main stereo system.  I rewrote some of the HDL code that was license-encumbered and published the project on GitHub in April 2018.

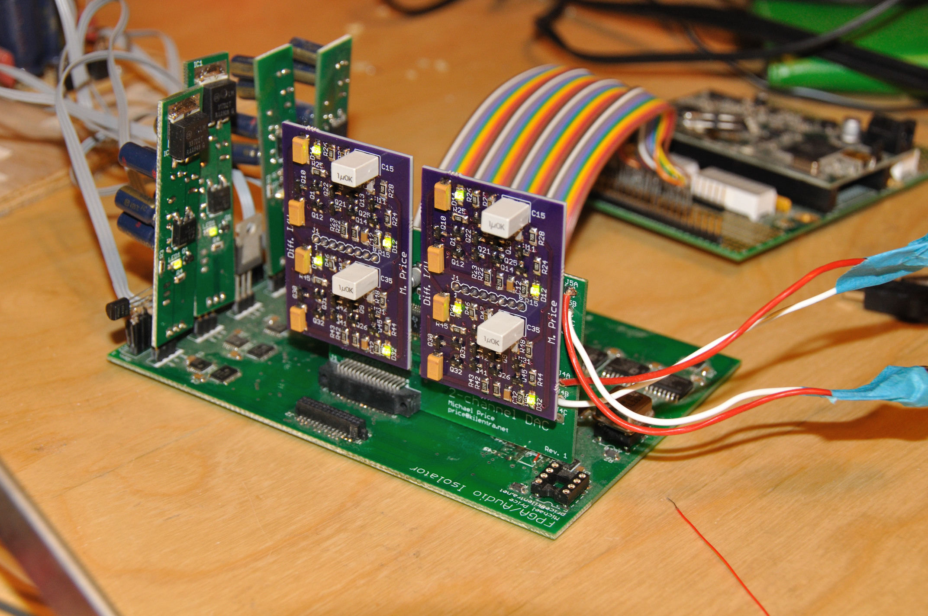
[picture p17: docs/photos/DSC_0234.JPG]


    Testing of an earlier version of the platform in early 2017.  On the left side are prototype Jung regulators with a 3-terminal form factor; they were later integrated onto the bottom side of the backplane.  At right is a 2-channel DAC module based on the DSD1792 and a new discrete I/V stage.  (This DAC worked quite well and I plan to port it to the current platform.)  In the background is the ZTEX FPGA development board connected by a ribbon cable.

Progress has been slow due to work and family commitments, but I intend to continue soliciting community input, making improvements, and for those brave enough to build their own version, supporting the project indefinitely.

Fun facts
=========

This list will be periodically updated with stories and lessons learned from building and testing this project.

* You may be wondering, where does the name "Samoyed" come from?  When I was working on many of the boards you see here, my wife would comment with enthusiasm about samoyeds.  A samoyed is a `large, playful, fluffy white dog <https://en.wikipedia.org/wiki/Samoyed_dog>`_.  She talked about them so much that I decided to name the project after them.

* Don't try to drill out your own holes for XLR connectors unless you are comfortable with: nasty vibration, chuck falling out of the spindle, and irregular holes larger than you wanted.  This happens even with the `cloth trick <http://www.giangrandi.ch/mechanics/sheetmetaldrill/sheetmetaldrill.shtml>`_.  Send them to the CNC shop.

* When I tested the current set of baseline modules, I wired the XLR connectors with pins 1 and 2 for differential signals and pin 3 for chassis ground.  This is wrong; pin 1 should be chassis ground and pin 3 should be a signal pin.  However, because I was doing loopback tests between the DACs and ADCs (both wired in the same incorrect way), everything seemed fine.  It was only when I connected the DAC outputs to an amplifier and asked "why is there still ground loop hum?" and "why is there so little gain?" that I recognized the problem.

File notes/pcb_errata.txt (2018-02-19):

CDP PCB errata (version 1 from 2009)

Regulators
----------
Both positive and negative 15 V regs have LM329 backwards
Negative reg has missing connection between R6 and R7
Positive regulator can't be used for +5 V supply with its 6.9 V reference 
	(have to use LDO version for this application)
Maybe these regulators could all be built using the same PCB layout and different stuffing?
R7 on LDO is too large, 475 ohms works (was 1k)
    -> 4/2/2017: R7 needs to be shorted and Q3 needs to be removed.
PCBs are too tall I think
Mechanical alignment/stability is not very good with 3 pin male/female headers

Isolator
--------
FX2 connector is rotated 180 deg, most likely
No debug headers for logic analyzer, SMAs or test points for scope
Prefer other types of connectors to Fastons for power/ground input
Needs to be a 4 layer board
No mounting holes
Slot 0 PCB collides with socket for clock oscillator
Why separate SPI ports for DACs and ADCs?
SPI CS muxing is annoying due to the delays that it causes
    -> But probably better than the alternatives?
AGND and DGND are isolated, but clock select circuitry crosses boundary without isolator
	Hack of adding 10 ohm resistor between input terminals worked for now
    TODO: Map out grounding scheme before designing boards
Clock oscillators use AGND (is this right?)
Sense of ADG1436 is reversed (e.g. CLK0 and CLK1 swapped) - easy workaround
ADG1436 is not the right clock switch to use--way too much capacitance (consider other clock dist methods)

Modules
-------

2-ch IV stage:
    I/V stage - op amp should be marked NE5534 (unless there is a good reason for something else)
    I/V is biased for opposite of actual DSD1792 current; change balancing CS resistors top/bottom
    I/V output follower biased too hot - increase CS resistors from 47.5 to 82.5 (20 mA to 12 mA)
    I/V has no lowpass filter, and way too much bandwidth (>1 MHz)
        Add 1 nF cap across IV resistor to limit bandwidth to ~200 kHz, but this causes DC offset?
        Also consider making a real antialiasing filter (TI has 2.2 nF across same 750 ohm, plus)
    Should probably have balanced to unbalanced converter (single ended line driver)
    Try to lower distortion from -80 to -100 dB.  Without feedback?  Think about it.

8-ch scaler:
    Serious DC offset problem from mismatched MOSFETs (up to 1 V)
    Distortion is not as low as it should be - some may be due to coupling caps.
    Use box film caps, not silly SMT polystyrene caps.  Or maybe they're fine?

2-ch ADC:
    WTF is a -2.5 V common mode doing?  With the gain you have, it should be +1.734 V 
        (and by the way, the ADC gives this as an output that should be used in a smarter circuit)
    Antialiasing filter is missing
    It wants buffering of the I2S outputs close to the chip.  (Ferrite bead for supply isolation of buffer?)

2-ch DAC:
    Board layout may be contributing some distortion not the fault of the IV stage.
        Right channel has more distortion than right (-94 vs -97)

General
-------
There needs to be a PCB for the power supply (the unregulated one with rectifiers and caps)
	with one multi-conductor cable from it to the isolator PCB
Need ECC for audio data - really do not want corruption for any reason
Put in more debug connectors for Logicport et al; it's impossible to probe traces on the boards (later revisions can remove them, or not populate them).  Worst regarding ACON on the ADC board.

===================================
Errata for version 2 (2017)
===================================

Mechanicals:
    PSU is bunched up close to transformers, and transformer wiring is a bit tight (with crimp connectors).
        -> Switch to a vertical header with some kind of retention?
    Think about whether to solder/crimp and also if it's feasible to adjust board placement.
    What about a (beefy) 7-pin header that attaches to a 7-conductor ribbon cable soldered to the transformer terminals?
    All screw holes for standoffs should be enlarged to handle M3 screws/standoffs since those are cheaper (hole dia = .135 maybe?)
        Note: M2.5 standoffs/screws seem to work, so far.

2-ch IV stage (version 2):
    LED as voltage reference had wrong voltage.  Bias currents too high.

PSU (version 2)
    Need high value bleeder resistors to discharge everything when power is removed.
    4.7k across each LV output (1.5 mA / 10 mW), 10k from each MV output to ground (2.5 mA / 50 mW)
        -> A bit slow on the +/- 22 V, but don't want to waste too much power.
    Add an indicator LED (through hole) that the power is on
    Consider separating the grounds for the +/- supplies (i.e. not supporting center tap)
        although this would be incompatible with my strategy of using a cap across the rails to limit ripple currents on ground
    Consider adding an inrush current limiter (thermistor).  Blew a resistor and tantalum cap when I hit the power switch too hard.
    
Clock test board
    SMA connector for output of ECL receiver is too close to PSU header - collides
        (Of course, I can use indiv. wires to PSU to rectify this)

All
    FIXED (Clock source and modules) ADM7154 max input is 5.5 V.  Need to prereg down to 5 V instead of hooking directly to D7VU.
    (Clock source and modules) LF50 prereg had 10u 1206 ceramic cap on output.  Must be changed to electrolytic with higher ESR to avoid oscillation.
    (Modules) Pin 1 of XLR should not be connected to AGND.  
        It should be connected to one of the standoff mounting pads for easy connection to the chassis.

Regulators
    FIXED Small transistor footprint in Jung regs. is narrower than BC807 - check package (the BC817 is fine)
    FIXED MAX6220 reg doesn't work for +5 or +3.3 V - replace with AD4525 and remove NR cap
    FIXED Remove 100 uF input cap C32/C50 for +5 and +3.3 V regs
    FIXED Replace AD825 with LME49710 to save money.  Performance is fine as confirmed by Walton.
    FIXED Feedback resistor dividers should be adjusted to match 500 ohm source resistance of reference.
    -- Note 7/5/2017: Above changes made on isolator_v2.sch.  regtest_v2.sch is original design as built for testing.

Carrier
    Hole for JST connector locating pin is on wrong side of footprint (currently left of notch, needs to be right)
    Should attempt to route BCK for each module to clock capable input pins

Isolator
    Zener diodes in Jung regs - pads are spaced too far apart for diodes MMSZ5226BS-FDICT-ND (SOD-323)
        They are OK for SOD-123 though, so that's what should be ordered.

DAC2
    FIXED DAC pads need to be extended out a ways.  Impossible to solder (or touch up) by hand, as it is.
    FIXED LPF amps need their (active low) disable pins tied to V+ to lower input bias current.  Also add resistors to V- to cancel the bias current.

ADC2
    Input buffer opamp needs larger local decoupling (10+ uF) to lower LF noise floor

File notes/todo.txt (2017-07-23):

DA platform to-do

Sep 21, 2014

- Fix errors in CellRAM sim

- Create behavioral model of FPGALink so that it's easy to test 
  by supplying an input data file on the command line
  (contents of this file should be relayed over USB)

- Create a basic read/write test of CellRAM
  (command can either read or write variable number of bytes)
    - Get working in simulation
    - Get working on Nexys2

Jan 18, 2015
- Received ZTEX USB-FPGA Module 2.13a (FPGA board with Artix-7)
- Switching from earlier CellRAM/Nexys2 to [DDR3] DRAM and Xilinx MIG

Mar 1, 2015
- Earlier demonstrated FIFO app using ZTEX board
- Currently working on test of DRAM based FIFO arbitrator

No easy way to simulate the memory
- Micron provides a plain Verilog model of DDR3 chips, but
- Xilinx MIG requires Xilinx encrypted primitives
--> Do most design work with a MIG model, and use VCS once it's working to simulate the full system

Jan 2, 2017

See planning.txt for more details
    Figure out software side of 2-ch setup
    Do listening eval
    Try 8-ch DAC and/or ADC?  Fix 2-ch ADC?
    Begin PCB design rev

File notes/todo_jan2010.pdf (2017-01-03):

Programmers Notepad - <new>
Todo (descending order of priority)

IN PROG Make controller state machine
- Add occasional in/out byte count monitoring messages

Add converter interface module for PMOD-DA2
- Determine if anything architectural needs changing
- Base module should handle adjustable bit rates and provide correct output format

Improve test framework; use to find and fix more bugs
- Write Python test jigs for: converter board, PMOD-DA2 (later: all converter modules)
- Write proper bit matching, format, and timing into MyHDL test framework and make unit tests
- Design complete test case for initial PMOD-DA2 usage
- Exercise serializer/deserializer issues
- Use real audio signals and register programming sequences; run longer; use multiple channels simultaneously

Update FX2 firmware to use all endpoints
- Determine proper algorithm for using only 3 flags with 4 endpoints
- Come up with a test for the FX2 firmware using simple software and FPGA firmware (echo EP2->EP6, EP4->EP8, measure accuracy/bitrate?)

Test simple sound card using PMOD-DA2
- Write simple program to stream setup commands followed by audio data
- Use logic analyzer to debug

Make register control software
- Can be anything, but preferably a daemon that talks to a simple Python UI
- When a setting changes, what changes are needed in the firmware in addition to writing converter registers? (Implement constraints)

Make converter interface modules
- Parameterized instantiation of DAC/ADC modules using specified types
- Look into merging control specifications so a single module handles all converters (extend differently for DAC, ADC)

Begin documenting this architecture

Add ability for memory arbitrator to reinitialize reads/writes at the end of a cell RAM row
- Keep track of current cell RAM address; when it reaches a multiple of 128, update the start address and return to initializing cycle state

Add configurable behavior to cell RAM

Make memory arbitrator capable of handling reads/writes down to 1 byte[?]
- Properly handle upper/lower byte issues
- Reduce min_chunk to 1 and adjust timings for correctness
- Is this really necessary? (If you stop playing audio, do you care if it stops 1 sample short?) Yes, but defer to later

Allow direction and channels to be byte values deserialized like AOVF, etc.
(or just replace by single "port type" value)

Make simple Linux sound card driver framework
- Alternatively, make a simple program for playing audio files that writes to EP2
- Figure out API for configuration settings, both in SPI

Make firmware test mode that has DAC data buses looped back to ADC data buses

Completed things
DONE Add SPI interface that reads/writes configuration memory
DONE Assign I/O module registers; finish documenting registers
DONE Add deserializer for dir/chan, aovf; serializer for hwcon, chipselect to toplevel
DONE Modify FX2 interface to work with controller
DONE Document all settings/adjustments that can be made and sent over EP4 or internally performed DONE Update fake generic DAC and ADC modules to actually consume / produce data

Page 1, 1/3/2010 - 12:12:11 AM

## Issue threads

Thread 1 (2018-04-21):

Improve documentation

pricem, 2018-04-21:
This issue will serve as a running commentary on documentation tasks:

- [ ] Provide an overview of the system with a couple high level diagrams
- [ ] Rearrange notes/writeup.txt into something more useful
- [ ] Locate photos and link to them appropriately
- [ ] Compile assorted plots of measured performance
- [ ] Write up detailed description of modular architecture and interfaces
- [ ] Write up detailed description of boards (v2 modules, carrier, clock, isolator)
- [ ] Write up detailed description of digital logic architecture
- [ ] Write up software documentation - how to configure MPD, Python scripts, etc.
- [ ] Compile subjective impressions of audio quality from various iterations

pricem, 2018-05-03:
Initial documentation is pushed and synced to da-platform.readthedocs.io.  I'll continue working down the list as time permits.

pricem, 2018-05-15:
Requested by passive420:
```
Please post some pics of your PCB designs and modules, the pics in the documents are gone...
```

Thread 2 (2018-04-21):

Clocking improvements

pricem, 2018-04-21:
I have tested the D/A and A/D modules at different sample rates, but this is not exposed by the software--everything is 44.1 kHz now.  This needs to be fixed.

Tasks:
- [ ] Build up a new clock board with the "standard" clock configuration (CLK0 = 22.5792 MHz, CLK1 = 24.576 MHz).  My board actually has CLK0 = 24.576 MHz and CLK1 = 11.2896 MHz for historical reasons.
- [ ] Make I2S clock divider adjustable in slot_controller and expose this functionality through the host interface.
- [ ] Modify Python scripts to accept sample rate as a command line argument and change the clock configuration if necessary before sending audio.  (Careful; there might already be samples in the FIFO that need to be played back with the previous sample rate before switching.)
- [ ] Evaluate different oscillator types subjectively.

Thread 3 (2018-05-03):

Better driver for FPGA carrier

pricem, 2018-05-03:
The baseline carrier has a USB interface and defines a protocol for sending commands and audio over that interface.  In the repository, there is currently a set of Python scripts building on top of libusb1 to exercise this protocol.  This is insufficient for at least two reasons:
1. Only a single process can access the hardware at a time.
2. Performance is somewhat slow; the Python script uses a lot of CPU cycles, and this will be a problem if trying to use high channel counts or sample rates on a Raspberry Pi.

A proper Linux driver could address both of those problems.  Addressing this issue should consider what (if anything) needs to be in the kernel vs. user-space, and what the appropriate APIs and command line programs would be.

As an intermediate step, it would make sense to refactor the existing scripts into a single program that could accept different playback and recording options, such as the map of logical channels to physical modules/channels, on the command line.

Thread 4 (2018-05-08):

Better measurements

pricem, 2018-05-08:
This is a wish list for measurements to be performed on current hardware:

- [ ] Harmonics and noise swept against signal level for DAC/ADC loopback.  I currently have plots swept against frequency at a fixed level; it would be good to do this for a few other levels (say, 0/-3/-10/-20/-60) and see if anything sticks out.
- [ ] Update phase noise measurements in final chassis with module breakout.

To be continued.

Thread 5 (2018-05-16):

Baseline module improvements

pricem, 2018-05-16:
This issue will be used to keep track of desired upgrades for the baseline DAC and ADC modules (which are AKM-based), in case we decide to do any further revisions.  Improving other modules (e.g. DSD1792 DAC) or using different converter chips would be a separate issue.

- [ ] All: Improve I/O connectors.  Each channel on DAC2/ADC2 has a 4-pin header, so it isn't possible to connect an RCA and XLR at the same time.  It would also be nice to have higher quality connectors (coaxial?) or at least something that locks.  For DAC8/ADC8, ribbon cable to RCA panel mount board works well, but the XLR input option for ADC8 needs more thought.
- [ ] DAC2: Figure out the right filter values to get a flat HF response through 20 kHz (before digital filtering).
- [ ] ADC2: Reduce distortion at near full scale signal levels.  Might have something to do with ADC driver power supplies--should use asymmetrical rails (say, +7.5 and -2.5 V) for best swing with 2.5 V CM output.
- [ ] ADC2/ADC8: Consider adding selectable input attenuators to handle more than 2 V RMS if desired (e.g. amplifier measurements, music recording).  Or maybe an LNA for less than 2 V.
- [ ] ADC8: Reduce distortion at high frequencies (2nd harmonic increases starting at 100 Hz) at high input levels.  Might have something to do with ADC driver?
- [ ] DAC8: Reduce crosstalk.  Worst channel pair is -59 dB at 5 kHz.  Probably capacitive coupling related to attenuator routing.
- [ ] ADC8: Summing 8 channels down to 2 seems to work, but summing 8 channels down to 1 doesn't.  Fix this.

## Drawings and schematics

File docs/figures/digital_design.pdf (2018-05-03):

### MIG

### DDR3 memory

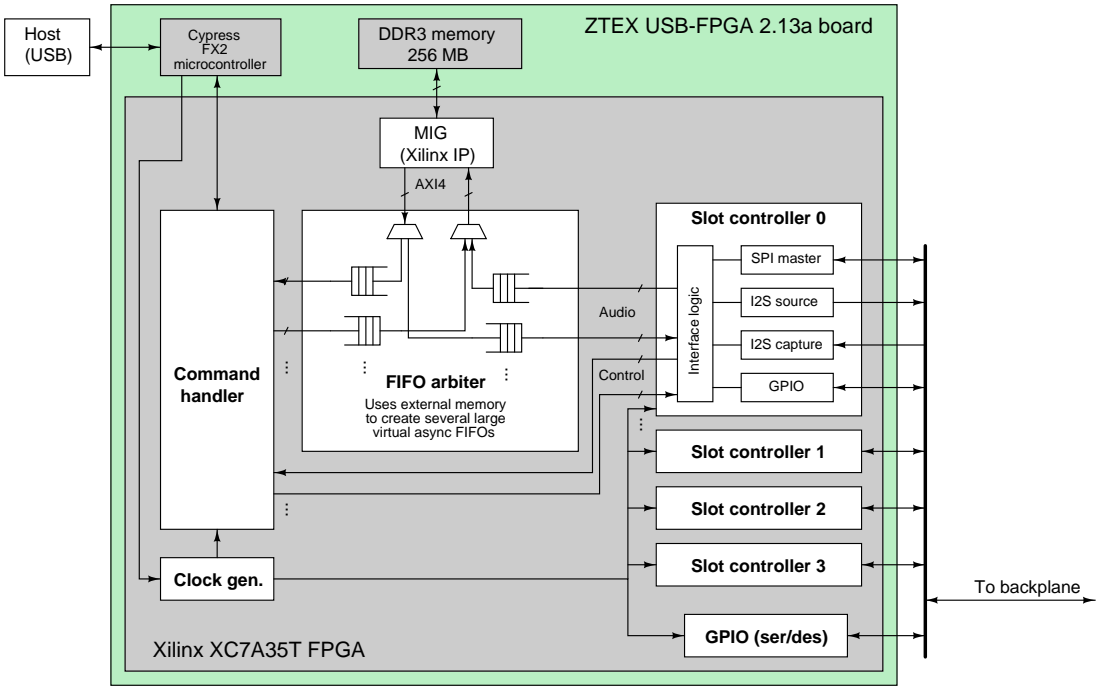
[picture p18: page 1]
Slot controller 0; AXI4; SPI master; I2S source; I2S capture; Host (USB); (Xilinx IP); Xilinx XC7A35T FPGA; Command handler; Control; Audio; Cypress; microcontroller; Interface logic; GPIO; Slot controller 1; Slot controller 2; Slot controller 3

ZTEX USB-FPGA 2.13a board

FIFO arbiter
Uses external memory
to create several large
virtual async FIFOs

To backplane Clock gen.

GPIO (ser/des)

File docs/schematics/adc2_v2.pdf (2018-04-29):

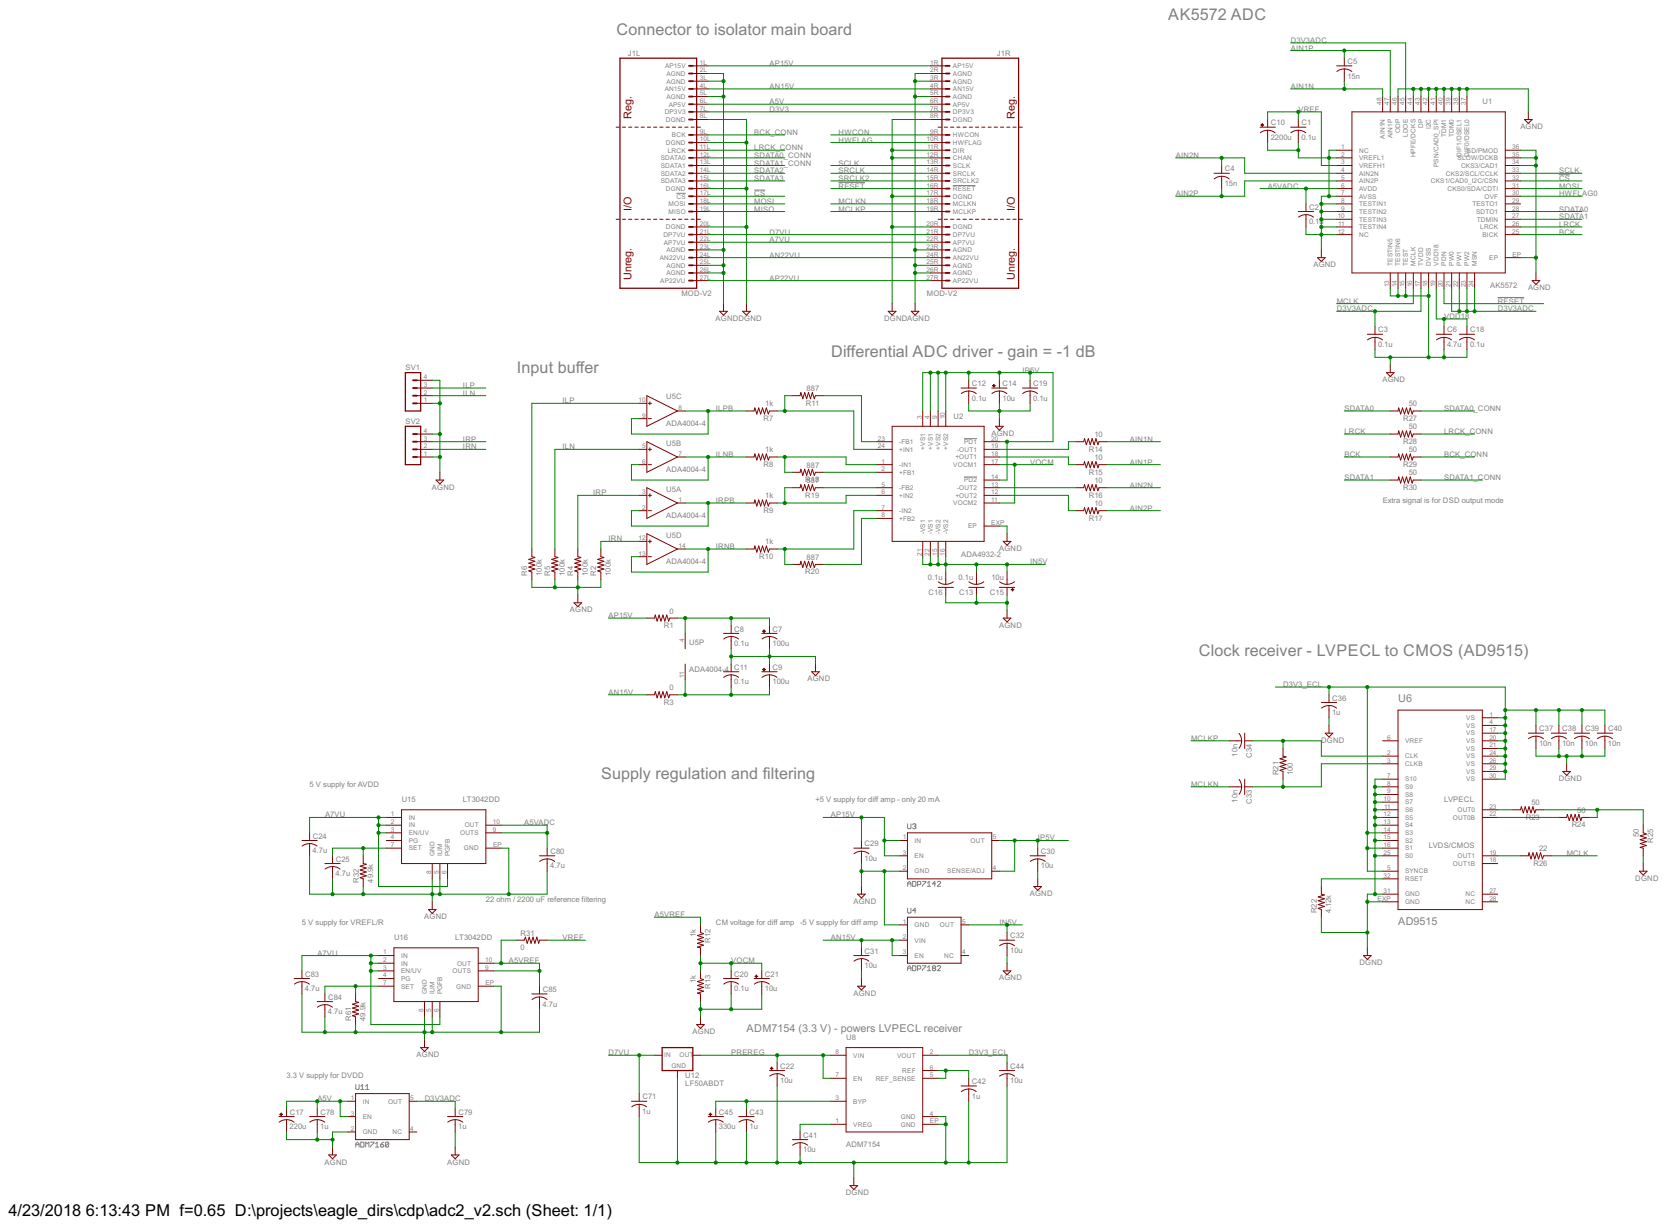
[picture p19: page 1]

Connector to isolator main board

10L BCK | LRCK_CONN
11L DGND

Differential ADC driver - gain = -1 dB

VOCM

Extra signal is for DSD output mode

Clock receiver - LVPECL to CMOS (AD9515)

Supply regulation and filtering

+5 V supply for diff amp - only 20 mA

22 ohm / 2200 uF reference filtering

CM voltage for diff amp

-5 V supply for diff amp

4/23/2018 6:13:43 PM f=0.65 D:\projects\eagle_dirs\cdp\adc2_v2.sch (Sheet: 1/1)

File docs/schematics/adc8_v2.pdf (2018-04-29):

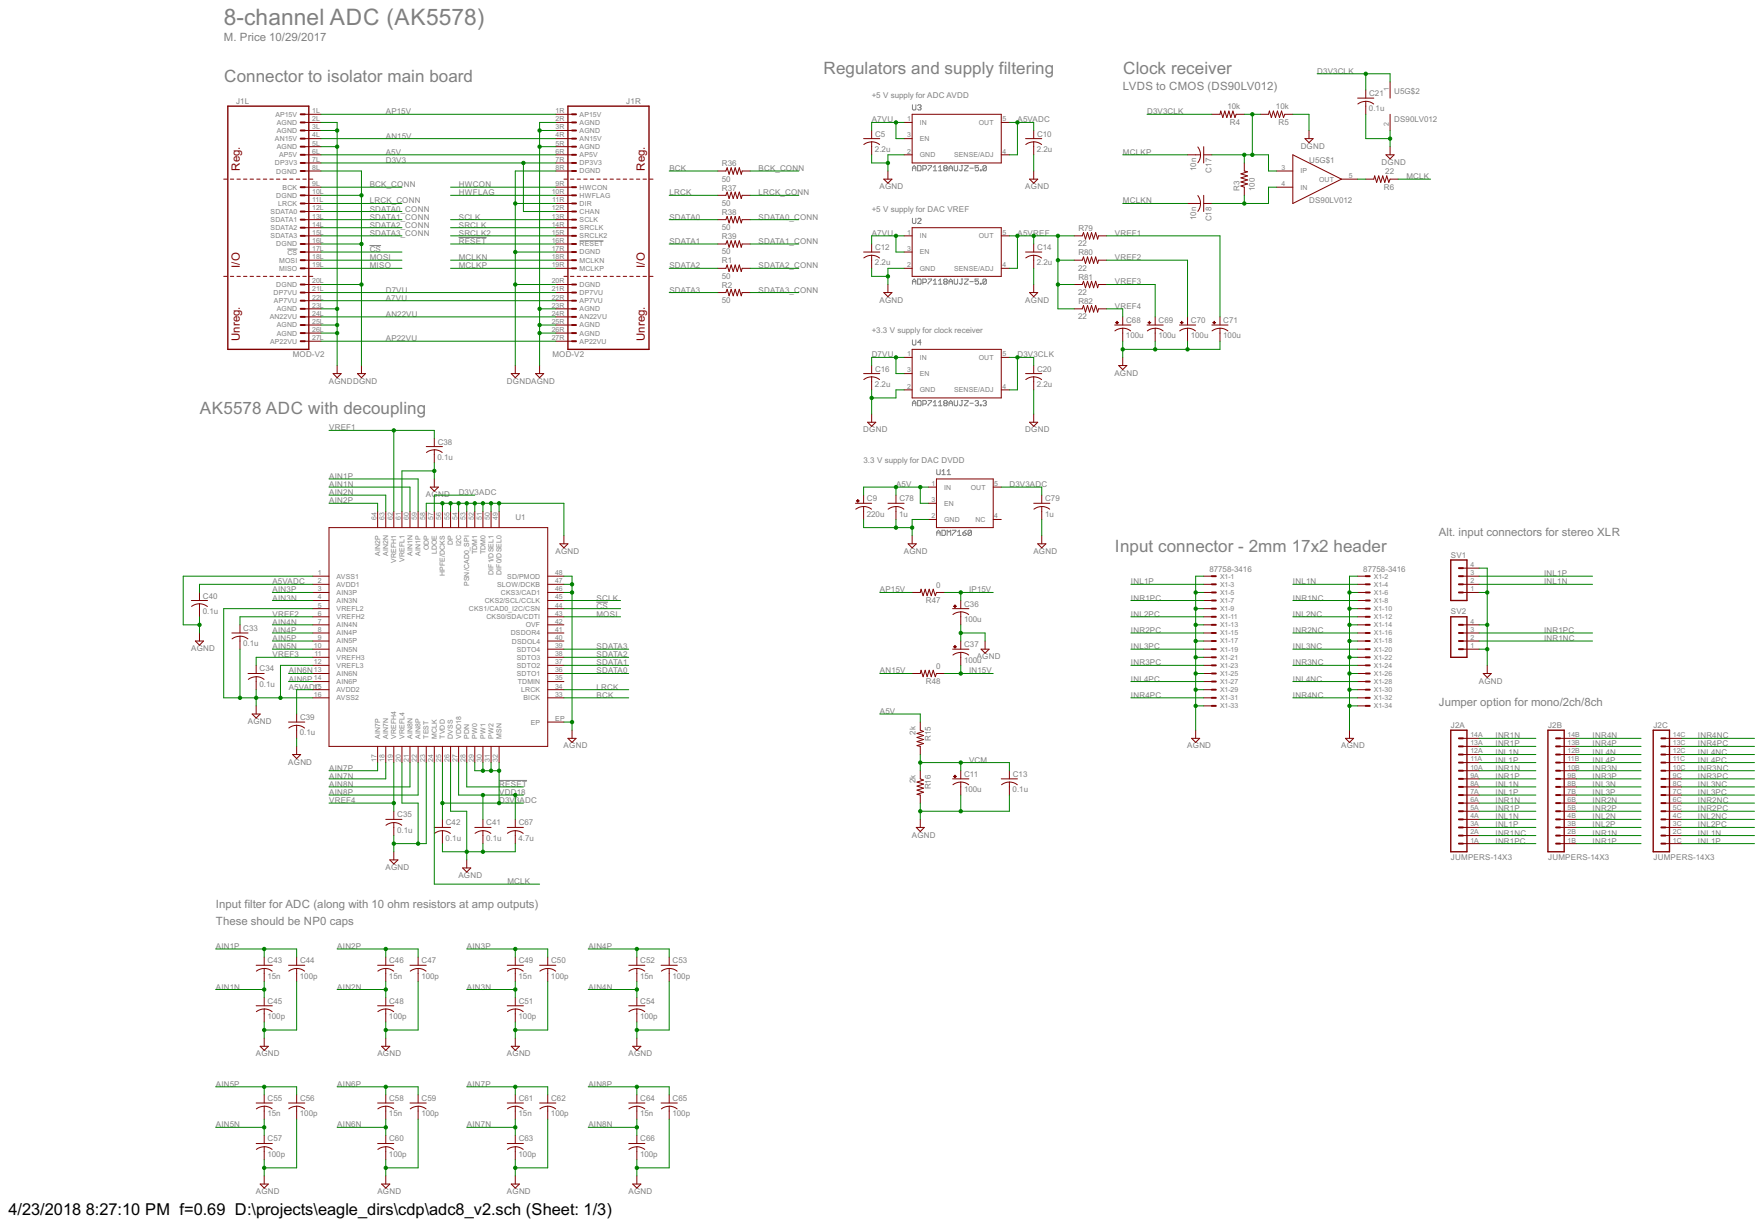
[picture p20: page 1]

+5 V supply for ADC AVDD

7L AP5V | D3V3 | 7R
8L DP3V3 | | | 8R

+5 V supply for DAC VREF

22L DP7VU | A7VU | 22R
23L AP7VU | AN22VU | 23R

+3.3 V supply for clock receiver

3.3 V supply for DAC DVDD

Alt. input connectors for stereo XLR

Jumper option for mono/2ch/8ch

Input filter for ADC (along with 10 ohm resistors at amp outputs)
These should be NP0 caps

4/23/2018 8:27:10 PM f=0.69 D:\projects\eagle_dirs\cdp\adc8_v2.sch (Sheet: 1/3)

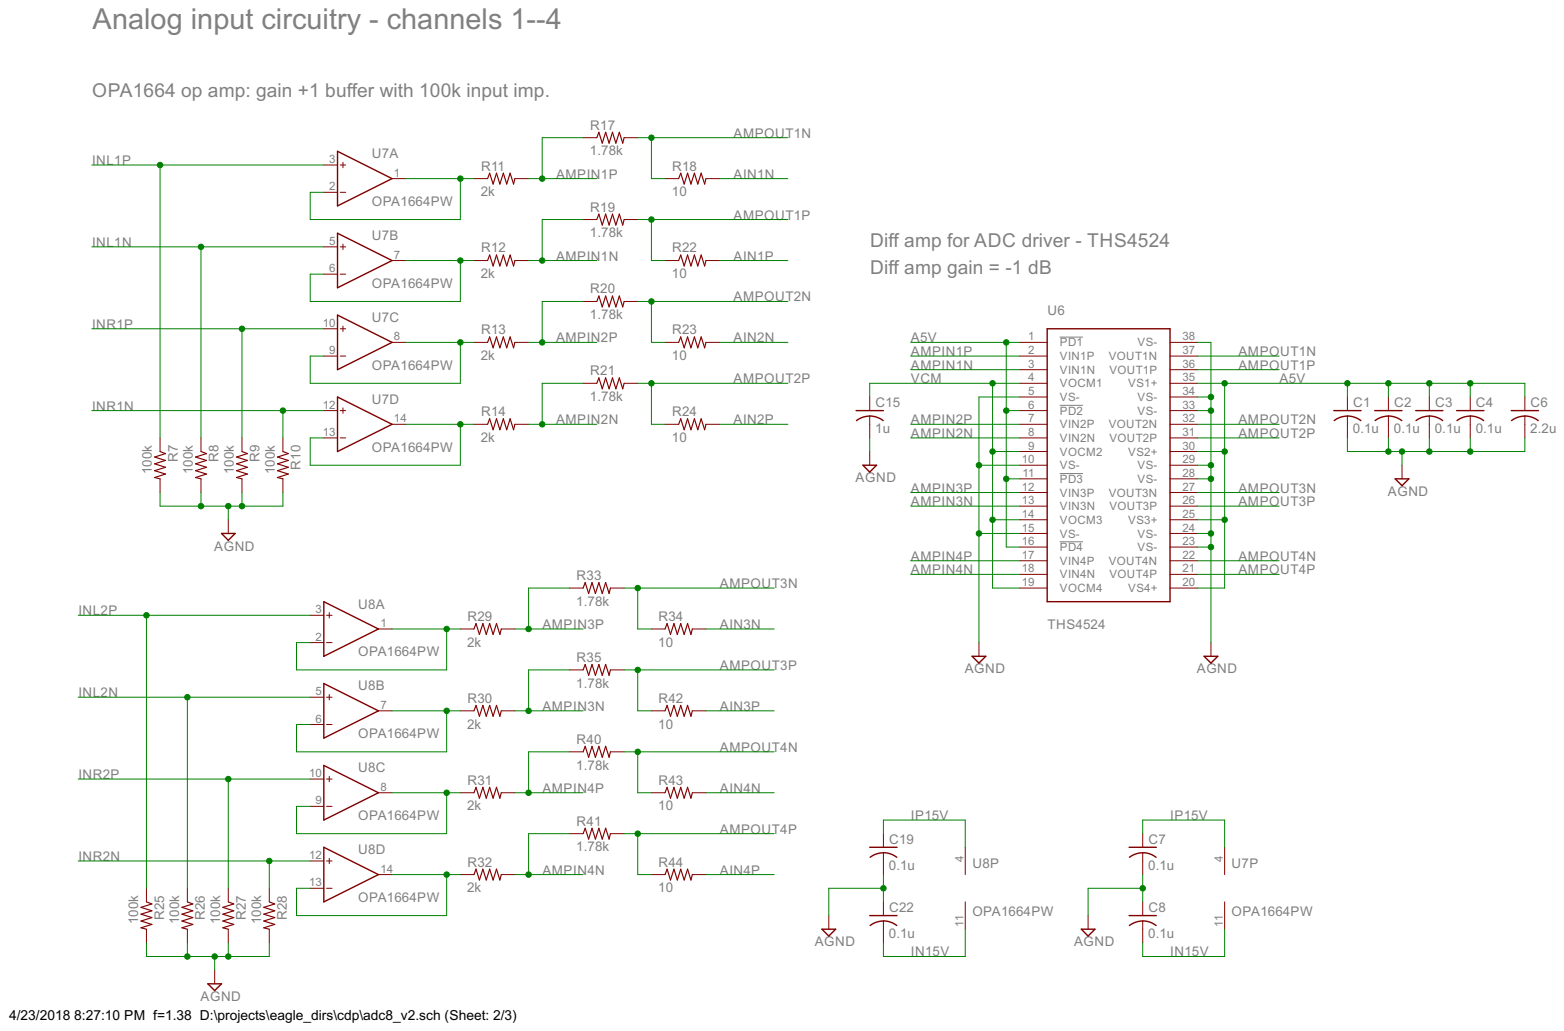
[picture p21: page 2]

Analog input circuitry - channels 1--4

OPA1664 op amp: gain +1 buffer with 100k input imp.

Diff amp for ADC driver - THS4524
Diff amp gain = -1 dB

7 8 9 | | 31 VOUT2N 30 VOUT2P

11
12 13 14 | | 26 VOUT3N 25 VOUT3P

4/23/2018 8:27:10 PM f=1.38 D:\projects\eagle_dirs\cdp\adc8_v2.sch (Sheet: 2/3)

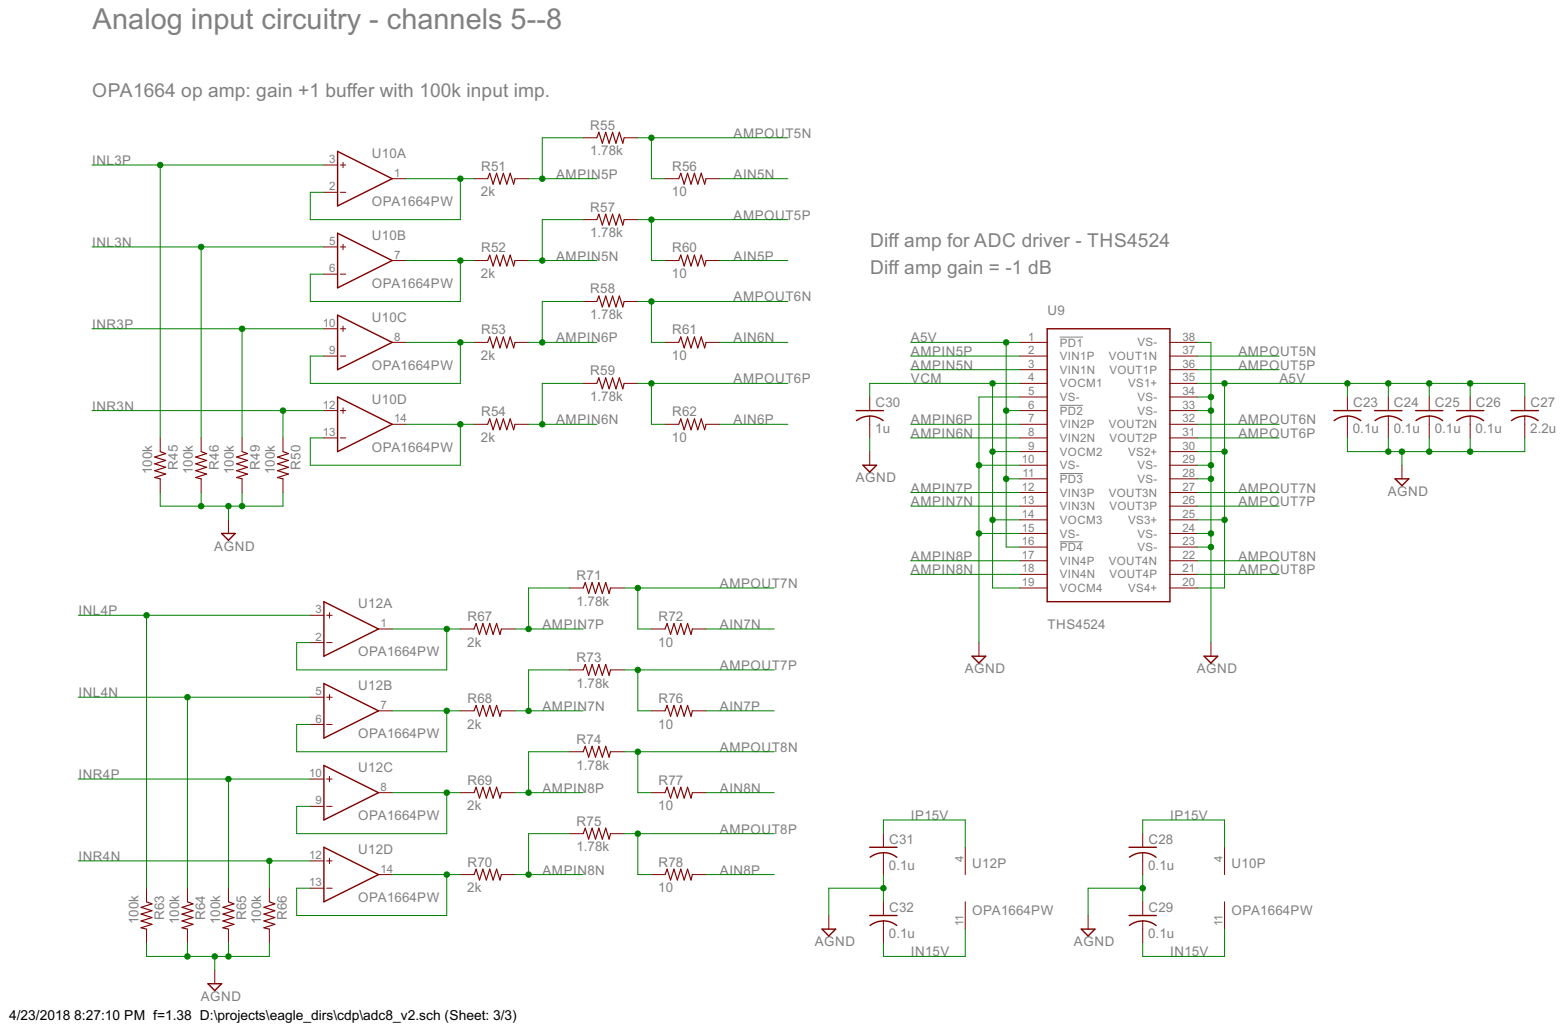
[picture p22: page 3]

Analog input circuitry - channels 5--8

OPA1664 op amp: gain +1 buffer with 100k input imp.

Diff amp for ADC driver - THS4524
Diff amp gain = -1 dB

7 8 9 | | 31 VOUT2N 30 VOUT2P

11
12 13 14 | | 26 VOUT3N 25 VOUT3P

4/23/2018 8:27:10 PM f=1.38 D:\projects\eagle_dirs\cdp\adc8_v2.sch (Sheet: 3/3)

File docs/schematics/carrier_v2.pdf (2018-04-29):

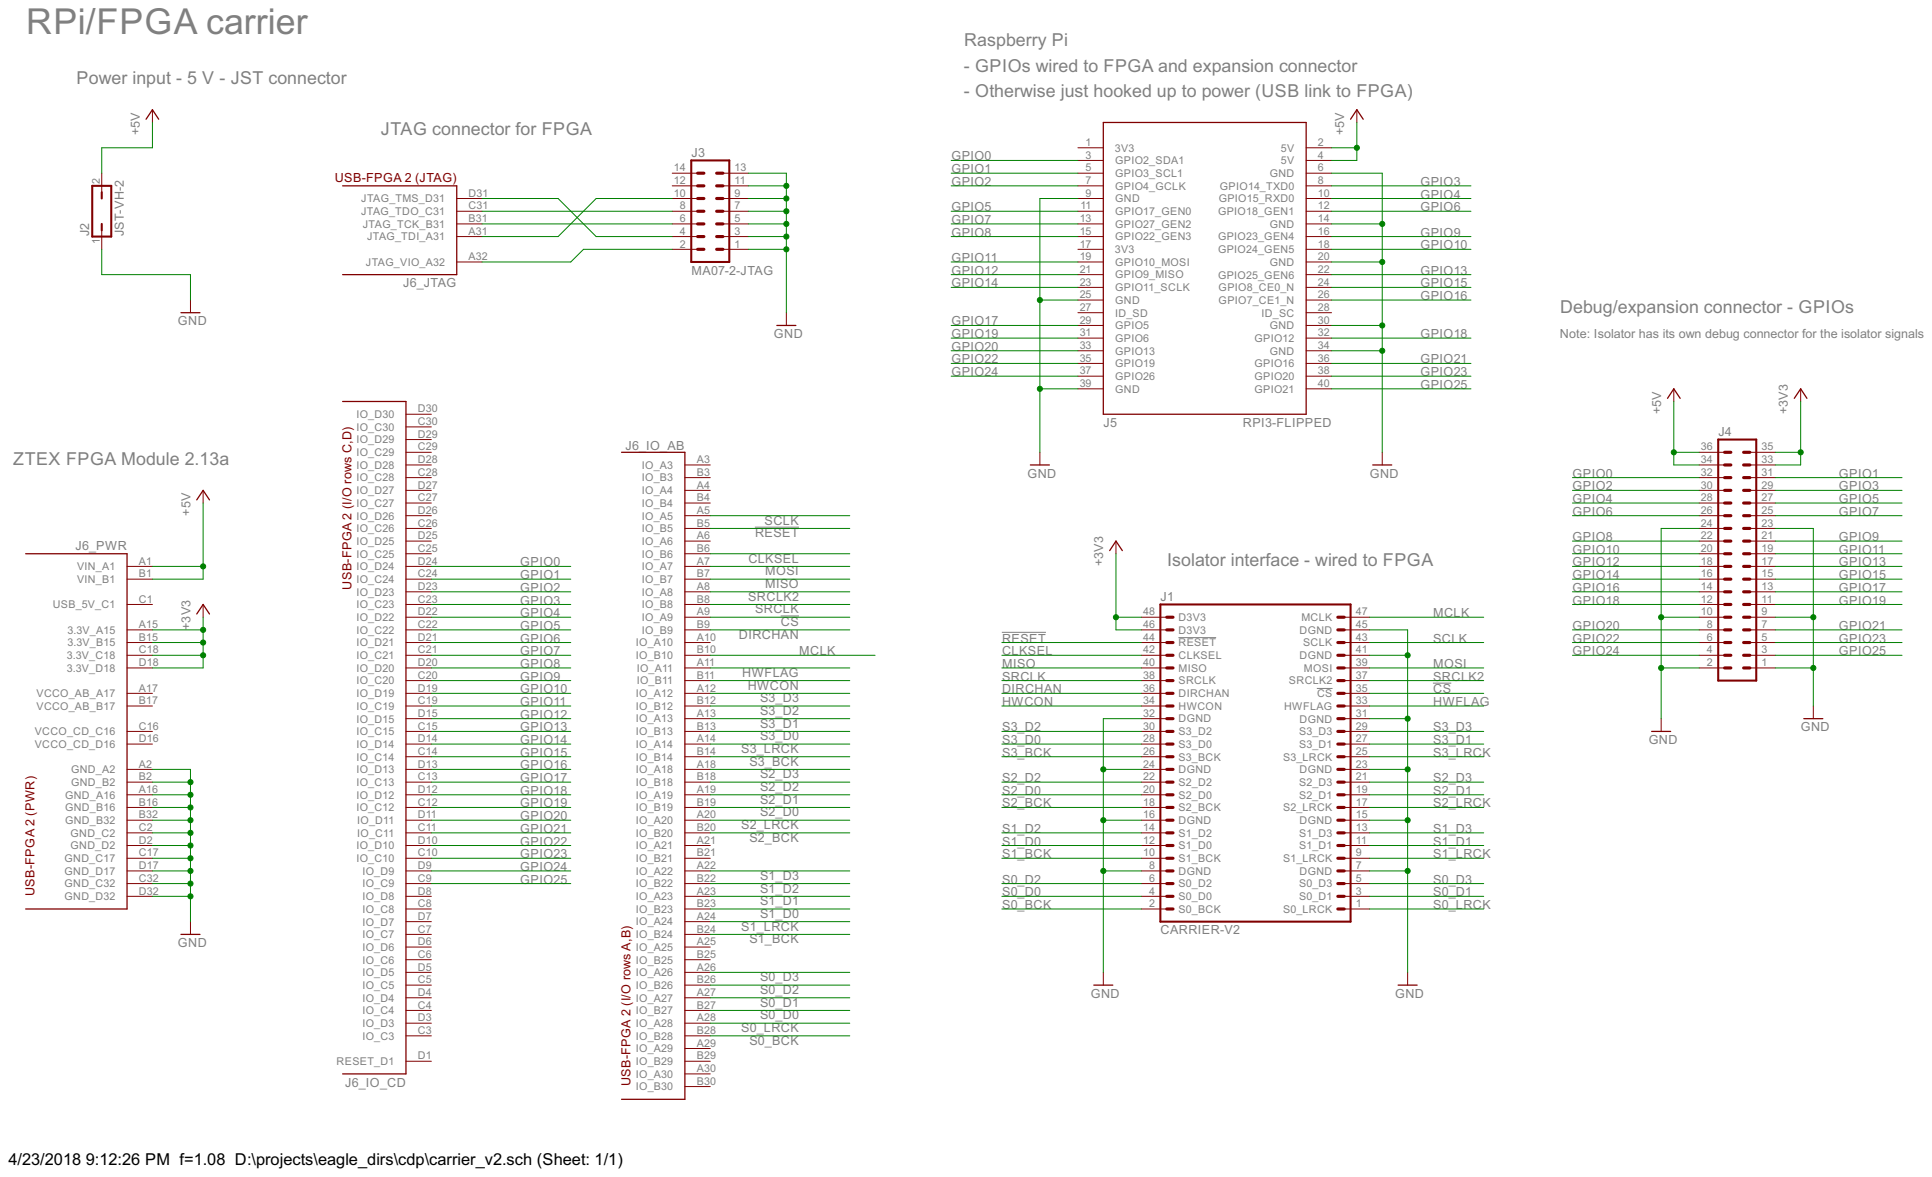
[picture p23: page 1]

Raspberry Pi - GPIOs wired to FPGA and expansion connector

Power input - 5 V - JST connector

- Otherwise just hooked up to power (USB link to FPGA)

JTAG connector for FPGA

Debug/expansion connector - GPIOs

Note: Isolator has its own debug connector for the isolator signals ZTEX FPGA Module 2.13a

Isolator interface - wired to FPGA

4/23/2018 9:12:26 PM f=1.08 D:\projects\eagle_dirs\cdp\carrier_v2.sch (Sheet: 1/1)

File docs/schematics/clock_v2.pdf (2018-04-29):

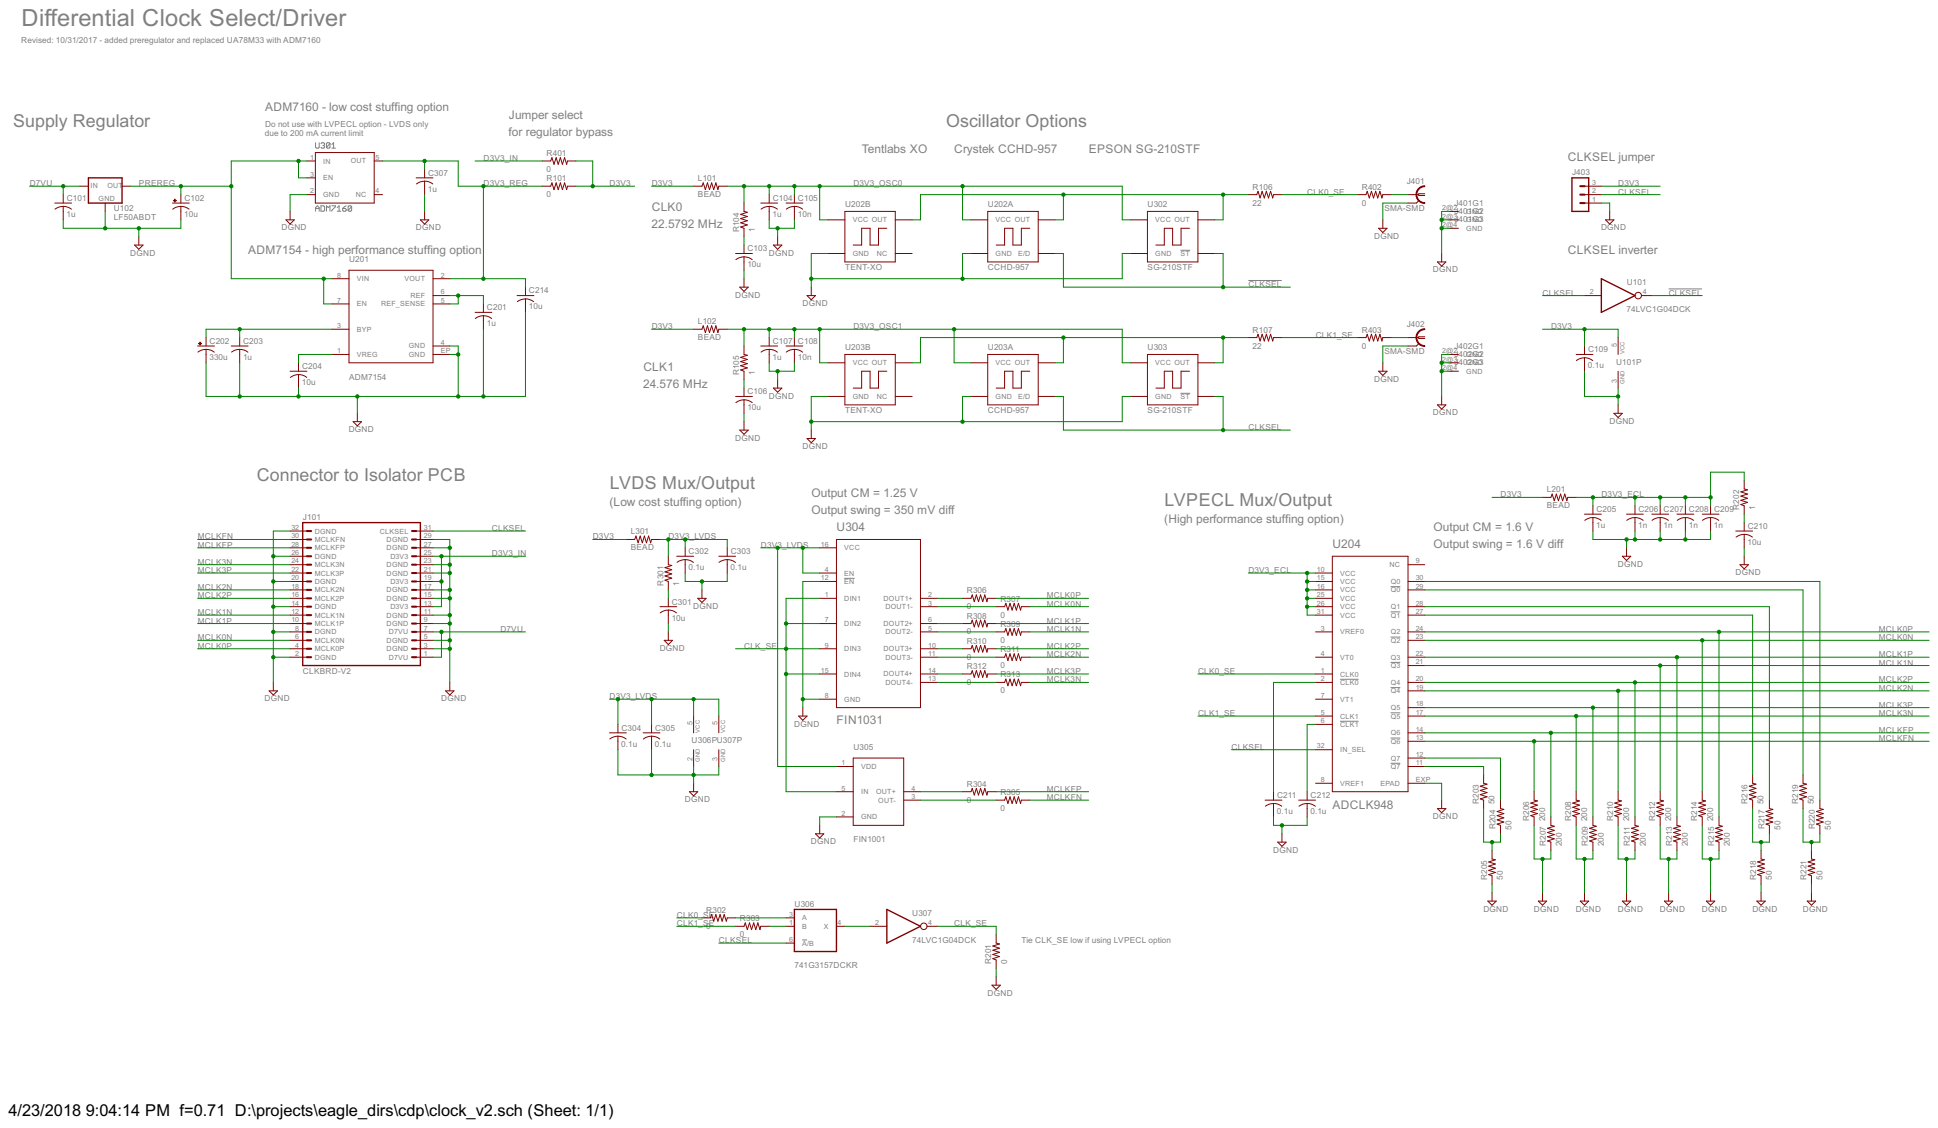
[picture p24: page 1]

Differential Clock Select/Driver

Revised: 10/31/2017 - added preregulator and replaced UA78M33 with ADM7160

ADM7160 - low cost stuffing option

Do not use with LVPECL option - LVDS only
due to 200 mA current limit

VCC GND NC OUT U202B

ADM7154 - high performance stuffing option

VCC GND NC OUT U203B

(Low cost stuffing option)

Output CM = 1.25 V
Output swing = 350 mV diff

LVPECL Mux/Output
(High performance stuffing option)

3 DGND
1 DGND

Tie CLK_SE low if using LVPECL option

4/23/2018 9:04:14 PM f=0.71 D:\projects\eagle_dirs\cdp\clock_v2.sch (Sheet: 1/1)

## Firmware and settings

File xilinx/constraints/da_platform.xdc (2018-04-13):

# fxclk_in - nominal period is 20.833 (48 MHz)
create_clock -period 20.833 -name fxclk_in [get_ports fxclk_in]
set_property PACKAGE_PIN P15 [get_ports fxclk_in]
set_property IOSTANDARD LVCMOS33 [get_ports fxclk_in]

# IFCLK - nominal period is 20.833 (48 MHz)
create_clock -period 20.833 -name ifclk_in [get_ports ifclk_in]
set_property PACKAGE_PIN P17 [get_ports ifclk_in]
set_property IOSTANDARD LVCMOS33 [get_ports ifclk_in]

# PA7/FLAGD/SLCS#
set_property PACKAGE_PIN T10 [get_ports reset]
set_property IOSTANDARD LVCMOS33 [get_ports reset]

# PB[0..9], PD[0..7]
set_property PACKAGE_PIN M16 [get_ports {fx2_fd[0]}]
set_property PACKAGE_PIN L16 [get_ports {fx2_fd[1]}]
set_property PACKAGE_PIN L14 [get_ports {fx2_fd[2]}]
set_property PACKAGE_PIN M14 [get_ports {fx2_fd[3]}]
set_property PACKAGE_PIN L18 [get_ports {fx2_fd[4]}]
set_property PACKAGE_PIN M18 [get_ports {fx2_fd[5]}]
set_property PACKAGE_PIN R12 [get_ports {fx2_fd[6]}]
set_property PACKAGE_PIN R13 [get_ports {fx2_fd[7]}]
set_property PACKAGE_PIN T9 [get_ports {fx2_fd[8]}]
set_property PACKAGE_PIN V10 [get_ports {fx2_fd[9]}]
set_property PACKAGE_PIN U11 [get_ports {fx2_fd[10]}]
set_property PACKAGE_PIN V11 [get_ports {fx2_fd[11]}]
set_property PACKAGE_PIN V12 [get_ports {fx2_fd[12]}]
set_property PACKAGE_PIN U13 [get_ports {fx2_fd[13]}]
set_property PACKAGE_PIN U14 [get_ports {fx2_fd[14]}]
set_property PACKAGE_PIN V14 [get_ports {fx2_fd[15]}]

# CTL0/FLAGA
set_property PACKAGE_PIN N16 [get_ports fx2_flaga]

# CTL1/FLAGB
set_property PACKAGE_PIN N15 [get_ports fx2_flagb]

# PA2/SLOE
set_property PACKAGE_PIN T14 [get_ports fx2_sloe]

# PA4/FIFOADR0
set_property PACKAGE_PIN R11 [get_ports fx2_fifoaddr0]

# PA5/FIFOADR1
set_property PACKAGE_PIN T11 [get_ports fx2_fifoaddr1]

# PA6/PKTEND
set_property PACKAGE_PIN R10 [get_ports fx2_pktend]

# RDY0/SLRD
set_property PACKAGE_PIN V16 [get_ports fx2_slrd]

# RDY1/SLWR
set_property PACKAGE_PIN U16 [get_ports fx2_slwr]
#set_property DRIVE 4 [get_ports SLWR]
#set_property SLEW FAST [get_ports SLWR]

set_property IOSTANDARD LVCMOS33 [get_ports fx2_*]
set_property DRIVE 4 [get_ports {fx2_fd[*]}]
set fx2_ports_in [get_ports {fx2_flag* {fx2_fd[*]}}]
set_input_delay -clock ifclk_in -min 0 $fx2_ports_in
set_input_delay -clock ifclk_in -max 12 $fx2_ports_in
set fx2_ports_out [get_ports {fx2_slrd fx2_slwr fx2_sloe fx2_fifoaddr0 fx2_fifoaddr1 fx2_pktend {fx2_fd[*]}}]
set_output_delay -clock ifclk_in -min 0 $fx2_ports_out
set_output_delay -clock ifclk_in -max 12 $fx2_ports_out

# Isolator interface

#   New pin assignments as of 8/8/2017
set_property PACKAGE_PIN F18 [get_ports {iso\.hwflag}]
set_property PACKAGE_PIN F16 [get_ports {iso\.hwcon}]
set_property PACKAGE_PIN G17 [get_ports {iso\.cs_n}]
set_property PACKAGE_PIN G16 [get_ports {iso\.dirchan}]
set_property PACKAGE_PIN H17 [get_ports {iso\.srclk2}]
set_property PACKAGE_PIN G14 [get_ports {iso\.srclk}]
set_property PACKAGE_PIN J14 [get_ports {iso\.mosi}]
set_property PACKAGE_PIN H14 [get_ports {iso\.miso}]
set_property PACKAGE_PIN J13 [get_ports {iso\.clksel}]
set_property PACKAGE_PIN J15 [get_ports {iso\.sclk}]
set_property PACKAGE_PIN K13 [get_ports {iso\.reset_n}]
set_property PACKAGE_PIN H16 [get_ports {iso\.mclk}]

set_property PACKAGE_PIN E18 [get_ports {iso\.slotdata[23]}]
set_property PACKAGE_PIN F15 [get_ports {iso\.slotdata[22]}]
set_property PACKAGE_PIN D18 [get_ports {iso\.slotdata[21]}]
set_property PACKAGE_PIN E17 [get_ports {iso\.slotdata[20]}]
set_property PACKAGE_PIN G13 [get_ports {iso\.slotdata[19]}]
set_property PACKAGE_PIN D17 [get_ports {iso\.slotdata[18]}]

set_property PACKAGE_PIN F13 [get_ports {iso\.slotdata[17]}]
set_property PACKAGE_PIN F14 [get_ports {iso\.slotdata[16]}]
set_property PACKAGE_PIN E16 [get_ports {iso\.slotdata[15]}]
set_property PACKAGE_PIN E15 [get_ports {iso\.slotdata[14]}]
set_property PACKAGE_PIN C17 [get_ports {iso\.slotdata[13]}]
set_property PACKAGE_PIN C16 [get_ports {iso\.slotdata[12]}]

set_property PACKAGE_PIN C15 [get_ports {iso\.slotdata[11]}]
set_property PACKAGE_PIN D15 [get_ports {iso\.slotdata[10]}]
set_property PACKAGE_PIN B17 [get_ports {iso\.slotdata[9]}]
set_property PACKAGE_PIN B16 [get_ports {iso\.slotdata[8]}]
set_property PACKAGE_PIN C14 [get_ports {iso\.slotdata[7]}]
set_property PACKAGE_PIN D14 [get_ports {iso\.slotdata[6]}]

set_property PACKAGE_PIN A16 [get_ports {iso\.slotdata[5]}]
set_property PACKAGE_PIN A15 [get_ports {iso\.slotdata[4]}]
set_property PACKAGE_PIN B14 [get_ports {iso\.slotdata[3]}]
set_property PACKAGE_PIN B13 [get_ports {iso\.slotdata[2]}]
set_property PACKAGE_PIN B12 [get_ports {iso\.slotdata[1]}]
set_property PACKAGE_PIN C12 [get_ports {iso\.slotdata[0]}]

#   Make it clear that mclk input is a clock at up to 25 MHz.
#   And that it's unrelated to the USB clock.
create_clock -period 40 -name clk0 [get_ports {iso\.mclk}]
set_false_path -from [get_clocks clk0] -to [get_clocks ifclk_out]
set_false_path -to [get_clocks clk0] -from [get_clocks ifclk_out]
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

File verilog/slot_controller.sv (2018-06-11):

/*
    Open-source digital audio platform
    Copyright (C) 2009--2018 Michael Price

    slot_controller: Controls audio and control interfaces for one module
    (audio interface card).  This includes I2S communication with a DAC or ADC,
    an SPI master, and GPIO lines.

    Warning: Use and distribution of this code is restricted.
    This HDL file is distributed under the terms of the Solderpad Hardware 
    License, Version 0.51.  Other files in this project may be subject to
    different licenses.  Please see the LICENSE file in the top level project
    directory for more information.
*/

`timescale 1ns / 1ps

module slot_controller(
    input clk_core, 
    input reset,
    FIFOInterface.in ctl_rd,
    FIFOInterface.out ctl_wr,
    FIFOInterface.in aud_rd,
    FIFOInterface.out aud_wr,
    output spi_ss_out, 
    input spi_ss_in, 
    output spi_sck, 
    output spi_mosi, 
    input spi_miso,
    inout [5:0] slot_data, 
    input slot_clk, 
    input sclk, 
    input dir, 
    input chan, 
    output logic [7:0] hwcon, 
    input [7:0] hwflag,
    output [3:0] spi_state, 
    output ctl_wr_waiting,
    //  This is a general "blocking" bit which determines whether the slot should
    //  produce or consume samples 
    input fifo_en
);

`include "commands.vh"

logic [5:0] slot_data_val;

//  DAC/ADC enable flags - first synchronized to I2S clock, then latched in by LRCK to ensure
//  that left channel always comes first.
logic clocks_enabled;
logic playback_enabled;
(* keep = "true" *) logic recording_enabled;
logic playback_enabled_synclr;
logic playback_enabled_sync;
(* keep = "true" *) logic recording_enabled_sync;
(* keep = "true" *) logic recording_enabled_synclr;

logic [9:0] audio_clk_ratio;
logic [3:0] audio_sample_res;

logic [9:0] audio_clk_counter;

logic [23:0] audio_samples_active[7:0];
logic [23:0] audio_samples_next[7:0];

logic [3:0] audio_samples_received;
logic [3:0] audio_samples_requested;

//  FIFO for control output (before it gets muxed; this is helpful for letting slot_controller logic do its thing)
FIFOInterface #(.num_bits(8)) ctl_wr_int(clk_core);
(* keep = "true" *) logic [3:0] ctl_wr_fifo_count;

fifo_sync #(.Nb(8), .M(3)) ctl_wr_fifo(
	.clk(clk_core), 
	.reset(reset),
	.in(ctl_wr_int.in),
	.out(ctl_wr),
	.count(ctl_wr_fifo_count)
);

assign ctl_wr_waiting = (ctl_wr_fifo_count > 0);

//  Reset for SPI master - needs to wait for clock to clear itself
logic reset_spi;
logic [3:0] spi_clock_count;
always_ff @(posedge reset or posedge sclk) begin
    if (reset) begin
        reset_spi <= 1;
        spi_clock_count <= 0;
    end
    else begin
        if (spi_clock_count >= 4)
            reset_spi <= 0;
        else begin
            reset_spi <= 1;
            spi_clock_count <= spi_clock_count + 1;
        end
    end
end

//  2 channel DAC mode
logic dac_pbck;
logic dac_plrck;
//  logic plrck;
logic [3:0] dac_pdata;

//  Note: alternatively the other 3 lines can be used for DSD format.
//  This is not yet supported.
logic dac_dbck = 0;
logic dac_dsdr = 0;
logic dac_dsdl = 0;

always_comb begin
    //  Version 2 isolator standardizes which pins are BCK/LRCK/DATA
    //  Side effect: DSD will have to use existing names
    slot_data_val = {dac_pdata[3], dac_pdata[2], dac_pdata[1], dac_pdata[0], dac_plrck, dac_pbck};
end

//  2 channel ADC mode
(* keep = "true" *) logic adc_pbck;
logic adc_plrck;
logic [3:0] adc_pdata;
always_comb begin
    //  Version 2 isolator standardizes which pins are BCK/LRCK/DATA
    adc_pbck = slot_data[0];
    adc_plrck = slot_data[1];
    adc_pdata[0] = slot_data[2];
    adc_pdata[1] = slot_data[3];
    adc_pdata[2] = slot_data[4];
    adc_pdata[3] = slot_data[5];
end

assign slot_data = dir ? slot_data_val : 6'bzzzzzz;


//  Latch to ensure FIFO gets reset properly even though it waits for ADC bit clock
logic fifo_reset;
always @(reset, adc_pbck) begin
    if (reset)
        fifo_reset <= 1;
    else if (adc_pbck)
        fifo_reset <= 0;
end

//  Synchronizers for playback/record enable
delay #(.num_cycles(2)) pe_delay(.clk(slot_clk), .reset(reset), .in(playback_enabled && fifo_en), .out(playback_enabled_sync));
delay #(.num_cycles(2)) re_delay(.clk(adc_pbck), .reset(fifo_reset), .in(recording_enabled && fifo_en), .out(recording_enabled_sync));

//  Synchronizers for dir/chan for ADC and DAC logic
wire dir_sync_adc;
wire chan_sync_adc;
wire dir_sync_dac;
wire chan_sync_dac;
delay #(.num_cycles(2)) dir_delay_adc(.clk(adc_pbck), .reset(reset), .in(dir), .out(dir_sync_adc));
delay #(.num_cycles(2)) chan_delay_adc(.clk(adc_pbck), .reset(reset), .in(chan), .out(chan_sync_adc));
delay #(.num_cycles(2)) dir_delay_dac(.clk(slot_clk), .reset(reset), .in(dir), .out(dir_sync_dac));
delay #(.num_cycles(2)) chan_delay_dac(.clk(slot_clk), .reset(reset), .in(chan), .out(chan_sync_dac));

//  Convenience: figure out how many channels we're supposed to have
wire [3:0] audio_num_channels_adc = chan_sync_adc ? 8 : 2;
wire [3:0] audio_num_channels_dac = chan_sync_dac ? 8 : 2;

//  SPI controller

FIFOInterface #(.num_bits(35)) spi_request(clk_core);
FIFOInterface #(.num_bits(32)) spi_response(clk_core);

logic spi_request_isread;
logic spi_request_addr_bytes;
logic [15:0] spi_request_addr_contents;
logic spi_request_data_bytes;
logic [15:0] spi_request_data_contents;
assign spi_request.data = {spi_request_isread, spi_request_addr_bytes, spi_request_data_bytes, spi_request_addr_contents, spi_request_data_contents};

logic [15:0] spi_response_read_addr;
logic [15:0] spi_response_read_data;
assign {spi_response_read_addr, spi_response_read_data} = spi_response.data;

spi_master spi(
    .clk(clk_core), 
    .clk_serial(!sclk),
    .reset(reset_spi), 
    .request(spi_request.in),
    .response(spi_response.out),
    .sck(spi_sck), 
    .ss_out(spi_ss_out), 
    .ss_in(spi_ss_in),
    .mosi(spi_mosi), 
    .miso(spi_miso),
    .state(spi_state)
);

(* keep = "true" *) logic [3:0] byte_counter;
(* keep = "true" *) logic [3:0] report_byte_counter;
(* keep = "true" *) logic [7:0] current_cmd;
(* keep = "true" *) logic [7:0] current_report;
(* keep = "true" *) logic report_active;

//  Asynchronous FIFO - audio for DACs

(* keep = "true" *) logic [4:0] audio_rx_fifo_wr_count;
(* keep = "true" *) logic [4:0] audio_rx_fifo_rd_count;

FIFOInterface #(.num_bits(32)) audio_rx(slot_clk);
always_comb audio_rx.ready = (((audio_clk_counter == 0) && (audio_rx_fifo_rd_count >= audio_num_channels_dac)) || (audio_samples_requested > 0));

logic audio_rx_rd_ready_last;
delay arfrr_delay(
    .clk(slot_clk), 
    .reset, 
    .in(audio_rx.ready), 
    .out(audio_rx_rd_ready_last)
);

fifo_async #(
    .Nb(32), 
    .M(4), 
    .N(16)
) audio_rx_fifo(
	.reset(reset),
	.in(aud_rd),
	.in_count(audio_rx_fifo_wr_count),
	.out(audio_rx.out),
	.out_count(audio_rx_fifo_rd_count)
);

/*
clk_divider lrclk_divider(reset, slot_clk, plrck);
defparam lrclk_divider.ratio = 192;
defparam lrclk_divider.threshold = 96;
*/
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

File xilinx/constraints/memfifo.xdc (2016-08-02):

# fxclk_in
create_clock -period 20.833 -name fxclk_in [get_ports fxclk_in]
set_property PACKAGE_PIN P15 [get_ports fxclk_in]
set_property IOSTANDARD LVCMOS33 [get_ports fxclk_in]

# IFCLK
create_clock -period 20.833 -name ifclk_in [get_ports ifclk_in]
#create_clock -name ifclk_in -period 33.333 [get_ports ifclk_in]
set_property PACKAGE_PIN P17 [get_ports ifclk_in]
set_property IOSTANDARD LVCMOS33 [get_ports ifclk_in]

# GPIO
set_property PACKAGE_PIN R15 [get_ports gpio_clk]
set_property PACKAGE_PIN T15 [get_ports gpio_dir]
set_property PACKAGE_PIN T13 [get_ports gpio_dat]
set_property PULLUP true [get_ports gpio_dat]
set_property IOSTANDARD LVCMOS33 [get_ports gpio_*]

# PA7/FLAGD/SLCS#
set_property PACKAGE_PIN T10 [get_ports reset]
set_property IOSTANDARD LVCMOS33 [get_ports reset]

# PB[0..9], PD[0..7]
set_property PACKAGE_PIN M16 [get_ports {fd[0]}]
set_property PACKAGE_PIN L16 [get_ports {fd[1]}]
set_property PACKAGE_PIN L14 [get_ports {fd[2]}]
set_property PACKAGE_PIN M14 [get_ports {fd[3]}]
set_property PACKAGE_PIN L18 [get_ports {fd[4]}]
set_property PACKAGE_PIN M18 [get_ports {fd[5]}]
set_property PACKAGE_PIN R12 [get_ports {fd[6]}]
set_property PACKAGE_PIN R13 [get_ports {fd[7]}]
set_property PACKAGE_PIN T9 [get_ports {fd[8]}]
set_property PACKAGE_PIN V10 [get_ports {fd[9]}]
set_property PACKAGE_PIN U11 [get_ports {fd[10]}]
set_property PACKAGE_PIN V11 [get_ports {fd[11]}]
set_property PACKAGE_PIN V12 [get_ports {fd[12]}]
set_property PACKAGE_PIN U13 [get_ports {fd[13]}]
set_property PACKAGE_PIN U14 [get_ports {fd[14]}]
set_property PACKAGE_PIN V14 [get_ports {fd[15]}]
set_property IOSTANDARD LVCMOS33 [get_ports {fd[*]}]
set_property DRIVE 4 [get_ports {fd[*]}]

# CTL0/FLAGA
set_property PACKAGE_PIN N16 [get_ports FLAGA]
set_property IOSTANDARD LVCMOS33 [get_ports FLAGA]

# CTL1/FLAGB
set_property PACKAGE_PIN N15 [get_ports FLAGB]
set_property IOSTANDARD LVCMOS33 [get_ports FLAGB]

# PA2/SLOE
set_property PACKAGE_PIN T14 [get_ports SLOE]
set_property IOSTANDARD LVCMOS33 [get_ports SLOE]

# PA4/FIFOADR0
set_property PACKAGE_PIN R11 [get_ports FIFOADDR0]
set_property IOSTANDARD LVCMOS33 [get_ports FIFOADDR0]

# PA5/FIFOADR1
set_property PACKAGE_PIN T11 [get_ports FIFOADDR1]
set_property IOSTANDARD LVCMOS33 [get_ports FIFOADDR1]

# PA6/PKTEND
set_property PACKAGE_PIN R10 [get_ports PKTEND]
set_property IOSTANDARD LVCMOS33 [get_ports PKTEND]

# RDY0/SLRD
set_property PACKAGE_PIN V16 [get_ports SLRD]
set_property IOSTANDARD LVCMOS33 [get_ports SLRD]

# RDY1/SLWR
set_property PACKAGE_PIN U16 [get_ports SLWR]
set_property IOSTANDARD LVCMOS33 [get_ports SLWR]
#set_property DRIVE 4 [get_ports SLWR]
#set_property SLEW FAST [get_ports SLWR]

# I/O delays
set_input_delay -clock ifclk_in -min 0.000 [get_ports {FLAG* {fd[*]}}]
set_input_delay -clock ifclk_in -max 14.000 [get_ports {FLAG* {fd[*]}}]
set_output_delay -clock ifclk_in -min 0.000 [get_ports {SLRD SLWR}]
set_output_delay -clock ifclk_in -max 14.000 [get_ports {SLRD SLWR}]

# LED's
set_property PACKAGE_PIN H15 [get_ports {led1[0]}]
set_property PACKAGE_PIN J13 [get_ports {led1[1]}]
set_property PACKAGE_PIN J14 [get_ports {led1[2]}]
set_property PACKAGE_PIN H14 [get_ports {led1[3]}]
set_property PACKAGE_PIN H17 [get_ports {led1[4]}]
set_property PACKAGE_PIN G14 [get_ports {led1[5]}]
set_property PACKAGE_PIN G17 [get_ports {led1[6]}]
set_property PACKAGE_PIN G16 [get_ports {led1[7]}]
set_property PACKAGE_PIN G18 [get_ports {led1[8]}]
set_property PACKAGE_PIN H16 [get_ports {led1[9]}]
set_property IOSTANDARD LVCMOS33 [get_ports {led1[*]}]
set_property DRIVE 12 [get_ports {led1[*]}]

set_property PACKAGE_PIN U9 [get_ports {led2[0]}]
set_property PACKAGE_PIN V9 [get_ports {led2[1]}]
set_property PACKAGE_PIN U8 [get_ports {led2[2]}]
set_property PACKAGE_PIN V7 [get_ports {led2[3]}]
set_property PACKAGE_PIN U7 [get_ports {led2[4]}]
set_property PACKAGE_PIN V6 [get_ports {led2[5]}]
set_property PACKAGE_PIN U6 [get_ports {led2[6]}]
set_property PACKAGE_PIN V5 [get_ports {led2[7]}]
set_property PACKAGE_PIN T8 [get_ports {led2[8]}]
set_property PACKAGE_PIN V4 [get_ports {led2[9]}]
set_property PACKAGE_PIN R8 [get_ports {led2[10]}]
set_property PACKAGE_PIN T5 [get_ports {led2[11]}]
set_property PACKAGE_PIN R7 [get_ports {led2[12]}]
set_property PACKAGE_PIN T4 [get_ports {led2[13]}]
set_property PACKAGE_PIN T6 [get_ports {led2[14]}]
set_property PACKAGE_PIN U4 [get_ports {led2[15]}]
set_property PACKAGE_PIN R6 [get_ports {led2[16]}]
set_property PACKAGE_PIN U3 [get_ports {led2[17]}]
set_property PACKAGE_PIN R5 [get_ports {led2[18]}]
set_property PACKAGE_PIN V1 [get_ports {led2[19]}]
set_property IOSTANDARD LVCMOS33 [get_ports {led2[*]}]
set_property DRIVE 12 [get_ports {led2[*]}]
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

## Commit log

2009-07-03 initial versions
    [adc2.brd, adc2.sch, dac2.brd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]
2009-07-03 Single version of I/V converter
    [iv_diff.brd, iv_diff.sch]
2009-07-03 I/V stage 2-channel version passes ERC/DRC
    [iv_diff.brd, iv_diff.sch]
2009-07-03 2-channel DAC widened to accept I/V board; passes DRC/ERC
    [dac2.brd, dac2.sch]
2009-07-04 Added 2-channel ADC board (includes analog scaling; passes ERC/DRC)
    [adc2.brd, adc2.sch]
2009-07-04 Fixed resistor values, renamed components, moved labels on ADC
    [adc2.brd, adc2.sch]
2009-07-06 Added voltage scaler for AD1934 DAC
    [scaler.brd, scaler.sch, scaler_dual.brd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]
2009-07-07 Added 8-channel DAC board, updated scaler to fit connector spacing on DAC exactly
    [dac8.brd, dac8.sch, scaler_dual.brd]
2009-07-10 Added 8-channel ADC and positive, negative, LDO regulators; began layout of isolator
    [adc2.brd, adc2.sch, adc8.brd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]
2009-07-12 Some progress on isolator layout
    [isolator.brd, isolator.sch]
2009-07-13 First version of isolator board that passes ratsnest and DRC; corresponding updates to schematic
    [isolator.brd, isolator.sch]
2009-07-14 Updated boards and schematics to rev. 1, added zip archive with Gerber files
    [adc2.brd, adc2.sch, adc8.brd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]
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2009-11-02 Added entire sandbox project folder
    [nexys2_toplevel_pad.csv]
2009-11-02 Added USB framework
    [nexys2_toplevel_pad.csv]
2009-11-14 Tried to add DA2 PMOD interface
    [nexys2_toplevel_pad.csv]
2009-11-15 Added Python folder, moved PCB stuff to PCB folder
    [adc2.brd, adc2.sch, adc8.brd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]
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2009-12-31 Fixed dummy ADC, added notes and register/command definitions, initialized memory
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2010-01-02 A few bug fixes (now ADC data comes out of EP6)
2010-01-02 Updated ISE project files
    [nexys2_toplevel_pad.csv]
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2010-01-03 Split off I/O module registers; added controller interrupts, which are used for periodic timebase updates
2010-01-04 Added event support in testing framework; exposed bug that needs to be fixed
2010-06-13 Removed Verilog files from Xilinx project directory, converted to ISE 12.1
    [nexys2_toplevel_pad.csv]
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2016-08-10 Got SPI working on FPGA; I2S through FIFO arbiter is doing something, but not working yet (lots of dropped samples)
    [da_platform.sv, da_platform.xdc, da_platform_tb.sv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]
2016-08-12 Add ADC support (working in simulation, not tested) and clean up control responses. Still need to test with I2S loopback to diagnose dropped samples.
2017-01-01 Bringing repo up to date. Added READ_STATUS and RESET_SLOTS commands, fixed memory aliasing bug.
    [da_platform.sv, da_platform_tb.sv, da_platform_wrapper.sv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]
2017-01-02 Fix arbiter bug at FIFO rollaround; I2S loopback tests now works for a few minutes with no errors
    [da_platform_tb.sv, fifo_arbiter.sv, ztex_test.py]
2017-01-03 Add a bunch of notes from 2016 and start of 2017[?]
    [ztex_pinout_aug16.xlsx]
2017-01-15 Improve flexilibity of SPI and add 8-ch DAC model. Tested, working with DAC8 board.
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2017-03-27 Add initial V2 clock and power supply boards
    [clock_v2.brd, clock_v2.sch, psu_v2.brd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]
2017-07-23 Check in latest notes
    [da_platform_interfaces_v2.xlsx, ztex_pinout_aug16.xlsx]
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2017-10-03 Checking in some boards I had forgotten to copy over.
    [adc2_v2.brd, adc2_v2.sch, dac2_v2.brd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]
2017-10-06 ADC2/DAC2 v2.1 as submitted
    [adc2_v2.brd, adc2_v2.sch, dac2_v2.brd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]
2017-10-06 Added some notes and parts spreadsheets
    [da_platform_interfaces_v2.xlsx, dacadc2_v2_digikey.csv, dacadc_v2_parts.xlsx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]
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2017-10-12 Clean up Xilinx project directories and add project creation scripts
    [nexys2_toplevel_pad.csv]
2018-02-19 Switched MIG to AXI interface, initial rewrite of mig_adapter without license restriction
2018-02-19 Fiddling around with drive strength settings; may be orthogonal to real problem
    [da_platform.xdc]
2018-02-19 Make some 'logic' -> 'wire' changes in FIFOs to keep compiler happy
2018-02-19 Fix FX2 model again
    It was inserting an extra word at the beginning of the second and subsequent
    transfers into da_platform. The reason was that data_pending was being
    asserted unnecessarily. Probably a holdover from before I adjusted the clock
    timing to make things more realistic.
2018-02-19 Fix SELECT_CLOCK command
    The da_platform state machine wasn't resetting word_counter to 0 after receiving
    the desired clock index, which made it confused.
    [da_platform.sv]
2018-02-19 Start making slot model more generic
    Instead of having different Verilog modules for the various module types
    (DAC2, ADC2, DAC8, ADC8), we use one Verilog module (slot_model) and
    have the isolator model reconfigure it. The idea is to let the testbench
    try out different physical configurations of modules.
2018-02-19 Disable SPI slave model during reset
    [spi_slave.sv]
2018-02-19 Get SPI test cases working
    There were a few issues that had to be fixed. The SPI master was driving CS_N
    low for the wrong number of cycles (with unpredictable results) and the
    different combinations of address/data field sizes weren't all working.
    [da_platform.sv, da_platform_tb.sv, slot_controller.sv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]
2018-02-25 Fix bug in the count output of synchronous FIFO
    If a sample at the output was held up by flow control, the "count" output
    would not include that sample. So, downstream logic might think the FIFO
    was empty even if there was still a sample waiting to be read. This is
    now fixed.
2018-02-25 Fix fifo_arbiter bug
    The port_in_active register, which enables a FIFO for the write path, was being
    asserted 1 cycle too late.
    [fifo_arbiter.sv]
2018-02-25 Add test of DAC signal path
    This writes samples through the host interface and checks that the same samples
    come out of the selected DAC's I2S port, allowing for a small latency. It now
    uses the reconfigurable source/capture logic in the board-level model.
2018-02-25 Work around annoying enumerated types issue
    [isolator_model.sv, slot_model.sv]
2018-02-25 Remove duplicative aud_slots_out_read interfaces in da_platform
    These were originally put in to separately buffer each slot's outgoing
    audio samples on their way to the host. But it turns out this isn't
    necessary since we can only read a chunk of samples from one slot
    at a time. Let the FIFO arbiter do this job for us.
    Also, this was causing bus contention on the FIFO interface "ready"
    signals going into the FIFO arbiter.
2018-02-25 Add test of ADC signal path
    Works like the DAC test, but in reverse: We provide samples to the
    I2S sources in the board-level model. Then we ask the DUT to send us
    the right number of audio samples from the selected port.
    [da_platform_tb.sv, isolator_model.sv]
2018-02-28 Synchronize dir/chan inputs to slot controller
    This is only an issue for simulation, but: it seems there were clock domain
    crossings on these signals. We now separately synchronize them to the
    appropriate clocks for the DAC-related and ADC-related logic.
    [slot_controller.sv]
2018-02-28 Stop ADC data transfer when dir = 1
    Again for simulation only, some extra samples were getting sent out after
    recording was stopped and the slot direction was flipped from ADC to DAC.
    [slot_controller.sv]
2018-02-28 Add test of DAC->ADC loopback
    Rewrites some of the isolator model to correctly assign the various sample FIFO
    signals; I don't think it was possible without breaking out the interfaces
    (due to SV's inability to address the array elements with a variable).
    [da_platform_tb.sv, isolator_model.sv]
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2018-03-30 Hook up MIG related resets properly
    [da_platform_wrapper.sv]
2018-03-30 Add wait time to loopback test to fix a bug
    If you enable recording on a slot soon after changing the direction
    of the module connected to that slot, you might get some lingering
    (invalid) ADC samples written to the FIFO. This won't happen in
    real life because the module configuration is static after powerup.
    It's only a testbench issue.
    [da_platform_tb.sv]
2018-04-02 Correct polarity of MIG-clock-related reset
    [da_platform_wrapper.sv]
2018-04-02 Update Xilinx project script for MIG simulation options
    We now create two simulation sets, sim_real_mig and sim_fake_mig.
    As you might imagine this lets you choose (via current_fileset or
    "Make Active") whether to use the full MIG design and DDR3 memory
    model, or just a behavioral model of what an AXI slave memory
    should do. The simulation can take a while when you use the full
    MIG.
2018-04-04 Fix some synthesis warnings - switched "parameter" to "localparam" where it was really local - resized some FIFO interfaces that were too wide
    [da_platform.sv]
2018-04-13 Clean up constraints
    This commit explicitly defines the various clock domains (audio, SPI, etc.) and
    constrains the inputs/outputs as a reasonable first pass. I wrote these up
    in response to the various warnings and timing violations flagged by Vivado.
    Hopefully a reasonable first pass to resume hardware testing.
    A couple of clock nets had to be marked "keep" in order for the constraints
    to be applied properly. This prevents optimizations but isn't a big problem
    since everything is so slow.
    [da_platform.sv, da_platform.xdc]
2018-04-13 Put in safeguards against 0-length memory accesses
    This was holding things up in testing, and was easy enough to reproduce
    in simulation. This would happen when the FIFO of samples leading back
    to the top level (from an ADC slot) was full; the FIFO arbiter would select
    that slot since it knew more samples were available, but then compute
    (correctly) a maximum transfer length of 0 because there was nowhere
    for the samples to go on the other side.
    The fix is easy enough: Just cancel the requests and wait until you
    have space freed up to write the samples out (i.e. to the host.)
    [fifo_arbiter.sv]
2018-04-13 Increase the ifclk to SCLK divider ratio from 8 to 16
    ifclk (from USB) is 48 MHz. This change is necessary to reduce SCLK below
    5 MHz as required by the AKM chips.
    Testbench code needs to wait longer for anything depending on SCLK,
    including HWCON updates and SPI transfers.
2018-04-13 Fix HWCON serializer timing
    There was a potential for hold violations in the per-slot HWCON serializers.
    The reason was that the serializer requires the parallel (slow) clock to be
    stable at the falling edge of the serial (fast) clock. But in this context,
    the parallel and serial clocks (srclk2_sync and srclk_sync) were both really
    registers, and they were both triggered by the same clock edge (sclk).
    The fix is to make srclk2_sync change on the negative edge of sclk so it
    comes "before" srclk_sync.
    [da_platform.sv]
2018-04-21 Stop FIFO arbiter from going into read mode when FIFO is blocked
    Reads have a higher priority than writes, so we would repeatedly
    enter the "read" state and then go back to idle. This would normally
    be fine, except that if the host is sending data for a DAC, it will
    stall until another sample is consumed on the read side. Kind of
    defeats the purpose of having a big FIFO.
    [fifo_arbiter.sv]
2018-04-21 Bring Python scripts more up-to-date
    This is a batch of changes from the development PC and the Raspberry Pi.
    Once I switch those over to using the Git repository, any remaining bugs
    should show up (and get fixed) pretty quickly. But this initial pass
    is going to be a bit messy.
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2018-05-01 Add Excel sheet for pinout diagrams
    [interface_pinout_diagrams.xlsx]
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2018-05-20 Add some missing Eagle PCB files
    [adc8_v2.brd, adc8_v2.sch, carrier_v2.brd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]
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2018-06-12 AK4490: Reset during setup() to handle any prior sample rate change
2018-06-12 Improve sample rate switching
    Adds support for a few more sample rates, clearer code,
    and now also waits for FIFO to be flushed before actually changing anything.
    This prevents a few milliseconds or seconds of audio from coming out in
    "mouse mode" if the sample rate is changed.
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

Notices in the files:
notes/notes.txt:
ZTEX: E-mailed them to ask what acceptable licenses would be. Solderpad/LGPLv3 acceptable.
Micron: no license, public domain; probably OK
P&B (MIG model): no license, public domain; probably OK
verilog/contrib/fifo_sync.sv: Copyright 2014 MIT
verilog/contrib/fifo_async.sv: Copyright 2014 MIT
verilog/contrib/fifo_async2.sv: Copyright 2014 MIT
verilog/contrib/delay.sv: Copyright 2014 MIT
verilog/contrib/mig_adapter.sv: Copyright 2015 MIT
